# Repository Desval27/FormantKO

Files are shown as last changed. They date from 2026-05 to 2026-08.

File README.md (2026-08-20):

# Formant-KO 

# WIP
A somewhat authentic (at least in spirit) knockoff of the Elektor Formant™ DIY project synthesizer.  

Components that are not easily sourcable are substitued.  Substituted components or adapater boards are noted.

[Original Book 1 PDF](https://ikiwiki.laglab.org/Modular_Beast/ElektorFormantMusicSynthesiser.pdf)

DIN 41617 connecters are replaced with DIN 41612 connectors (Type B 32-PIN).  A backplane is included as part of the project to avoid the point-to-point backend wiring of the original.  However, the current backplane does not currently offer more configurability compared to the original.  It simply provides a secure connection and reduces wiring complexity and fragility.  

I have opted to keep the flying wires for connecting the panel components as opposed to a separate panel mounted "control" PCB.  Right now I'm torn between keeping the layouts and wiring as they were originally defined or replacing them with something like JST XH connectors for easy disconnect & replacement.  Perhaps both?

The goal for verison 2 is to make both the cards and the bus system more configurable compared to the original normaled path (e.g. jumpers for signal routing, etc.).

### What About the μA726?

Of course this part is in very short supply and often quite expensive when available.  However, at least for this iteration, the plan is to replicate the original design as closely as possible.  Not only will this allow original parts to be used but it will also permit available drop in replacements such as the [pA726](https://www.portabellabz.be/pa726.html). 

### A Note About Board Heights

The original Formant used two different PCB sizes.  These were Small (160mm x 100mm) and Large (160mm x 200mm).  The Small corresponds to the standard single height EuroCard, but the standard double height EuroCard is 160mm x 233.35mm. The latter being 33.35mm taller than the original.  This replica will use the double height EuroCard instead of the original Large.  This allows for eaiser usage of standard EuroCard cages and accessories.  

Note: All modules offer mounting support for typical Schroff EuroCard panel and rack accessories.

## Status

⚠️ Very Incomplete ⚠️

Note: This information is only as accurate as I can remember to update it.

Most activity has been in the COM, NOISE, and LFOs modules. Scratch that....most activity has been bits and pieces all over.  I like to switch things up.

Latest updates are for the [ADSR CONTROLLER](modules/ADSR_CONTROLLER/README.md) module.

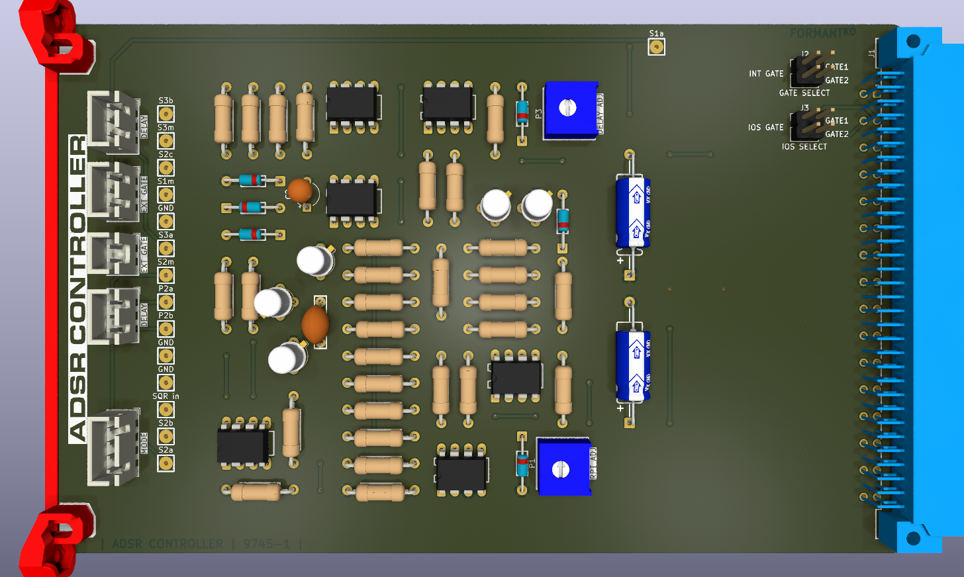
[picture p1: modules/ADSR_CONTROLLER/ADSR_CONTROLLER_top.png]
Top Render


- ✓ PCB/Panel exists but likely a WIP.
- ✔ PCB/Panel exists but may not be completely functional or untested.
- ✅ PCB/Panel exists and is working (for a given value of "working").

## Modules

- [TEMPLATE](modules/TEMPLATE/README.md)

### Book 1

- ✓ [VCO](modules/VCO/README.md)
- ✓ [VCF 12dB](modules/VCF_12/README.md)
- [VCF 24dB](modules/VCF_24/README.md)
- ✓ [RFM](modules/RFM/README.md)
- ✓ [ADSR](modules/ADSR/README.md)
- ✔ [DUAL VCA](modules/DUAL_VCA/README.md)
- [LFOs](modules/LFOs/README.md)
- ✓ [NOISE](modules/NOISE/README.md)
- ✓ [COM](modules/COM/README.md)

### Book 2

- [TOUCH CONTROLLER](modules/TOUCH_CONTROLLER/README.md)
- [NEW PITCH DETECTOR](modules/NPD/README.md)
- [DIGITAL KEYBOARD CONTROLLER](modules/DKC/README.md)
- [VCF EXTENSIONS](modules/VCF_EXT/README.md)
- ✓ [LFO SINE CONVERTER](modules/LFO_SINE/README.md)
- ✓ [NOISE DNG](modules/NOISE_DNG/README.md)
- ✓ [NOISE CNC](modules/NOISE_CNC/README.md)
- [COM EXTENSIONS](modules/COM_EXT/README.md)
- ✓ [RING MODULATOR](modules/RING_MODULATOR/README.md)
- ✔ [PHASE SHIFTER](modules/PHASE_SHIFTER/README.md)
- [KRIMISIZER](modules/KRIMISIZER/README.md)
- [DIGITAL REVERB](modules/DIGITAL_REVERB/README.md)
- [POWER SUPPLIES](modules/POWER_SUPPLIES/README.md)
- [KOV KB-GATE DISTRIBUTION](modules/KOV_KB_GATE_DISTRIBUTION/README.md)
- [MULTIPLE JACKS](modules/MULTIPLE_JACKS/README.md)
- ✔ [ADSR CONTROLLER](modules/ADSR_CONTROLLER/README.md)
- ✓ [VC LFOs](modules/VC_LFOs/README.md)
- [LF VCO](modules/LF_VCO/README.md)
- [DNG](modules/DNG/README.md)
- ✔ [ENVELOPE_FOLLOWER](modules/ENVELOPE_FOLLOWER/README.md)
- ✔ [SAMPLE & HOLD](modules/SAMPLE_AND_HOLD/README.md)
- ✓ [WAVEFORM-PROCESSOR](modules/WAVEFORM_PROCESSOR/README.md)
- [MIXER](modules/MIXER/README.md)
- ✔ [TUNING](modules/TUNING/README.md)
- [SEQUENCER](modules/SEQUENCER/README.md)

## Panels

- [TEMPLATE_3U](panels/TEMPLATE_3U/README.md)
- [TEMPLATE_6U](panels/TEMPLATE_6U/README.md)

### Book 1

- ✓ [VCO](panels/VCO/README.md)
- ✓ [VCF-12](panels/VCF_12/README.md)
- ✓ [VCF-24](panels/VCF_24/README.md)
- ✓ [RFM](panels/RFM/README.md)
- ✓ [ADSR](panels/ADSR/README.md)
- ✓ [DUAL_VCA](panels/DUAL_VCA/README.md)
- [LFOs](panels/LFOs/README.md)
- ✓ [NOISE](panels/NOISE/README.md)
- ✓ [COM](panels/COM/README.md)

### Book 2

- ✓ [RING MODULATOR](panels/RING_MODULATOR/README.md)
- ✓ [PHASE SHIFTER](panels/PHASE_SHIFTER/README.md)
- ✓ [MULTIPLE JACKS 3U](panels/MULTIPLE_JACKS_3U/README.md)
- ✓ [MULTIPLE JACKS 6U](panels/MULTIPLE_JACKS_6U/README.md)
- [DNG](panels/DNG/README.md)
- ✓ [ENVELOPE FOLLOWER](panels/ENVELOPE_FOLLOWER/README.md)
- [WAVEFORM PROCESSOR](panels/WAVEFORM_PROCESSOR/README.md)
- [MIXER 3](panels/MIXER_3/README.md)
- ✓ [TUNING](panels/TUNING/README.md)

## System

- ✓ [KEYBOARD INTERFACE](system/KBI/README.md)
- ✓ [KEYBOARD DIVIDER](system/KB_DIV/README.md)
- ✓ [INTERFACE RECEIVER](system/INTF_RCVR/README.md)
- ✔ [POWER SUPPLY](system/PSU/README.md)
- ✓ [POWER SUPPLY TRANSISTORS](system/PSU/PSU_PT/README.md)
- ✓ [BACKPLANE A](system/BACKPLANE_A/README.md)
- ✅ [TEST BOARD](system/TEST_HARNESS/README.md)
- ✓ [CARD EXTENDER](system/CARD_EXTENDER/README.md)
- ✓ [µA726C TESTER](system/VALIDATOR_JIG/README.md)

## MFOS Based Modules

[MFOS Site (External Link)](https://musicfromouterspace.com/)

### Modules

- [CALIBRATOR](MFOS/modules/CALIBRATOR/README.md)
- [CLOCK](MFOS/modules/CLOCK/README.md)
- [ANALOG CV-16](MFOS/modules/ANALOG/README.md)

### Panels

- [CLOCK](MFOS/panels/CLOCK/README.md)
- [ANALOG CV-16](MFOS/panels/ANALOG/README.md)

## ⚠️ Disclaimer⚠️

This project is provided **"as is"**, without warranty of any kind, express or implied,
including but not limited to the warranties of merchantability, fitness for a
particular purpose, and noninfringement.

This is a DIY electronics project intended for educational and experimental use.
Use at your own risk.

The author assumes **no responsibility or liability** for any damage, injury, or loss
resulting from the use or misuse of this design, including but not limited to:

* Damage to connected equipment (Eurorack modules, power supplies, computers, etc.)
* Incorrect assembly or wiring
* Use with incompatible voltages or signal levels
* Personal injury

### Electrical Safety

This project may interface with:

* ±15V Power rails
* AC Mains Power (Lethal Risk)
* External control voltages (CV)
* Digital and analog circuitry

Improper handling may result in damage or unsafe conditions.

You are responsible for:

* Verifying all connections before powering the system
* Ensuring correct polarity of power connections
* Confirming voltage ranges and signal compatibility
* Using appropriate protection circuits where necessary

### No Guarantees

Schematics, PCB layouts, and code are provided for reference only.
They may contain errors, omissions, or design flaws.

**Always review and validate the design before building or using it.**

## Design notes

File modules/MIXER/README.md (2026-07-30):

# MIXER-3

Format: 3U

## Status

⚠️ Incomplete⚠️

## Documents

- [English Translation](doc/MIXER__en.pdf)
<!--
- [Schematic](doc/schematic.pdf)
- [Assembly](doc/assembly.pdf)
- [Bill of Materials](doc/bom.csv)
- [Interactive Bill of Materials](doc/ibom.html)
-->

## Gerber to Order

⚠️ Untested ⚠️

<!--
- [Default](gerber_to_order/MIXER_160.0x100.0mm_for_Default.zip)
- [Elecrow](gerber_to_order/MIXER_160.0x100.0mm_for_Elecrow.zip)
- [FusionPCB](gerber_to_order/MIXER_160.0x100.0mm_for_FusionPCB.zip)
- [JLCPCB](gerber_to_order/MIXER_160.0x100.0mm_for_JLCPCB.zip)
- [PCBWay](gerber_to_order/MIXER_160.0x100.0mm_for_PCBWay.zip)
-->

## Images

<!--
![Rendered PCB Top](MIXER_top.png "Rendered PCB Top")

![Rendered PCB Bottom](MIXER_bottom.png "Rendered PCB Bottom")
-->

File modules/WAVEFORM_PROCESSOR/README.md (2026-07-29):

# WAVEFORM PROCESSOR

Format: 3U

The **Waveform Processor (WP)** is a versatile waveshaping module that dramatically expands the sonic palette of the **FORMANT** synthesizer by transforming existing oscillator waveforms into entirely new timbres. Using adjustable and voltage-controlled clipping, symmetry control, and selective amplification and inversion of waveform segments, it can produce effects ranging from brighter harmonics and trapezoidal waveforms to emphasized overtones, frequency doubling, and ring-modulator-like textures. With two signal inputs and a CV input for clipping modulation, the module responds dynamically to LFOs, envelopes, sequencers, or audio-rate control signals, making it equally suited for subtle animated timbral movement and aggressive experimental sound design. No calibration is required, making it a straightforward yet highly rewarding addition to any FORMANT system.

## Status

⚠️ Untested⚠️

## Documents

- [English Translation](doc/WAVEFORM_PROCESSOR__en.pdf)
- [Schematic](doc/schematic.pdf)
- [Assembly](doc/assembly.pdf)
- [Bill of Materials](doc/bom.csv)
- [Interactive Bill of Materials](doc/ibom.html)

## Gerber to Order

⚠️ Untested ⚠️

- [Default](gerber_to_order/WAVEFORM_PROCESSOR_160.0x100.0mm_for_Default.zip)
- [Elecrow](gerber_to_order/WAVEFORM_PROCESSOR_160.0x100.0mm_for_Elecrow.zip)
- [FusionPCB](gerber_to_order/WAVEFORM_PROCESSOR_160.0x100.0mm_for_FusionPCB.zip)
- [JLCPCB](gerber_to_order/WAVEFORM_PROCESSOR_160.0x100.0mm_for_JLCPCB.zip)
- [PCBWay](gerber_to_order/WAVEFORM_PROCESSOR_160.0x100.0mm_for_PCBWay.zip)

## Images

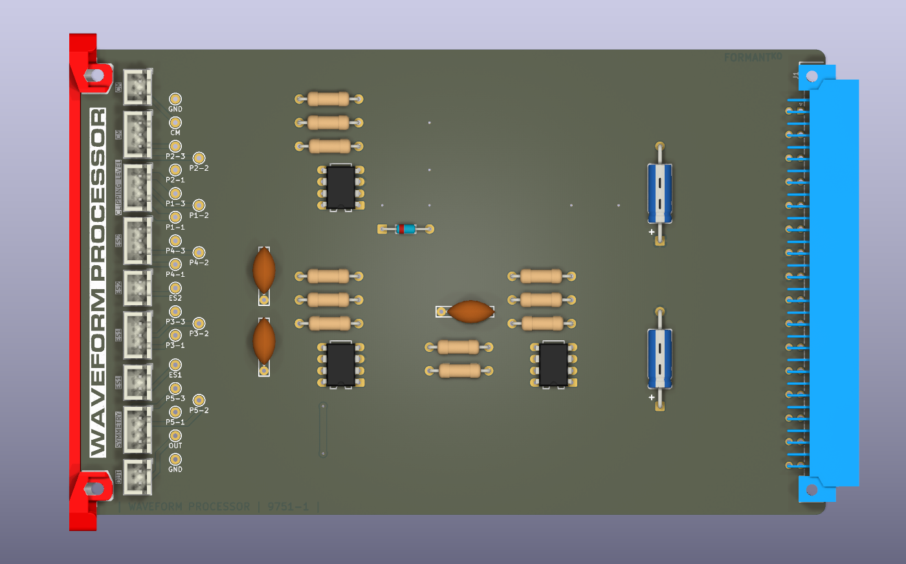
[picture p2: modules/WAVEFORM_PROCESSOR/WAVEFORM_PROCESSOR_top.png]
Rendered PCB Top


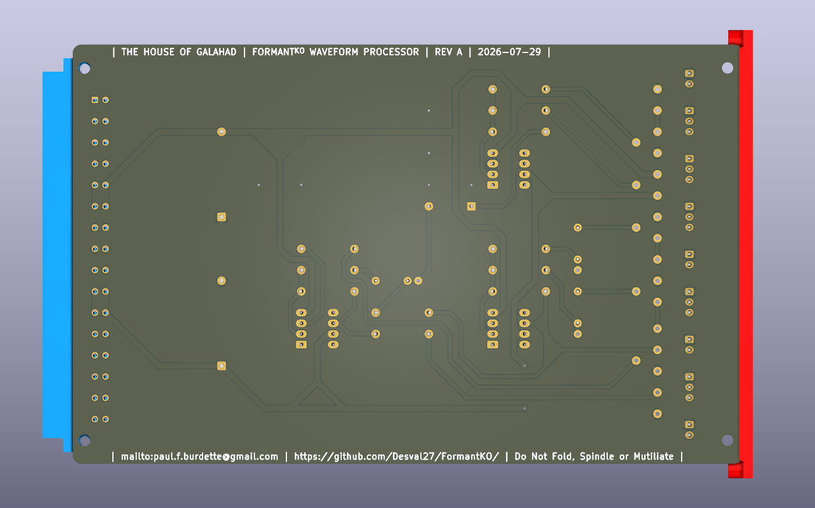
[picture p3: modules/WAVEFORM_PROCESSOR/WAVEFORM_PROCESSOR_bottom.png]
Rendered PCB Bottom


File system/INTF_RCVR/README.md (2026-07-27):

# INTERFACE RECEIVER

Format: Misc

### Modifications

Nothing major so far.

## Status

⚠️ Untested⚠️

## Documents

- [Schematic](doc/schematic.pdf)
- [Assembly](doc/assembly.pdf)
- [Bill of Materials](doc/bom.csv)
- [Interactive Bill of Materials](doc/ibom.html)

## Gerber to Order

⚠️ Untested⚠️

- [Default](gerber_to_order/INTF_RCVR_64.0x72.0mm_for_Default.zip)
- [Elecrow](gerber_to_order/INTF_RCVR_64.0x72.0mm_for_Elecrow.zip)
- [FusionPCB](gerber_to_order/INTF_RCVR_64.0x72.0mm_for_FusionPCB.zip)
- [JLCPCB](gerber_to_order/INTF_RCVR_64.0x72.0mm_for_JLCPCB.zip)
- [PCBWay](gerber_to_order/INTF_RCVR_64.0x72.0mm_for_PCBWay.zip)

## Images

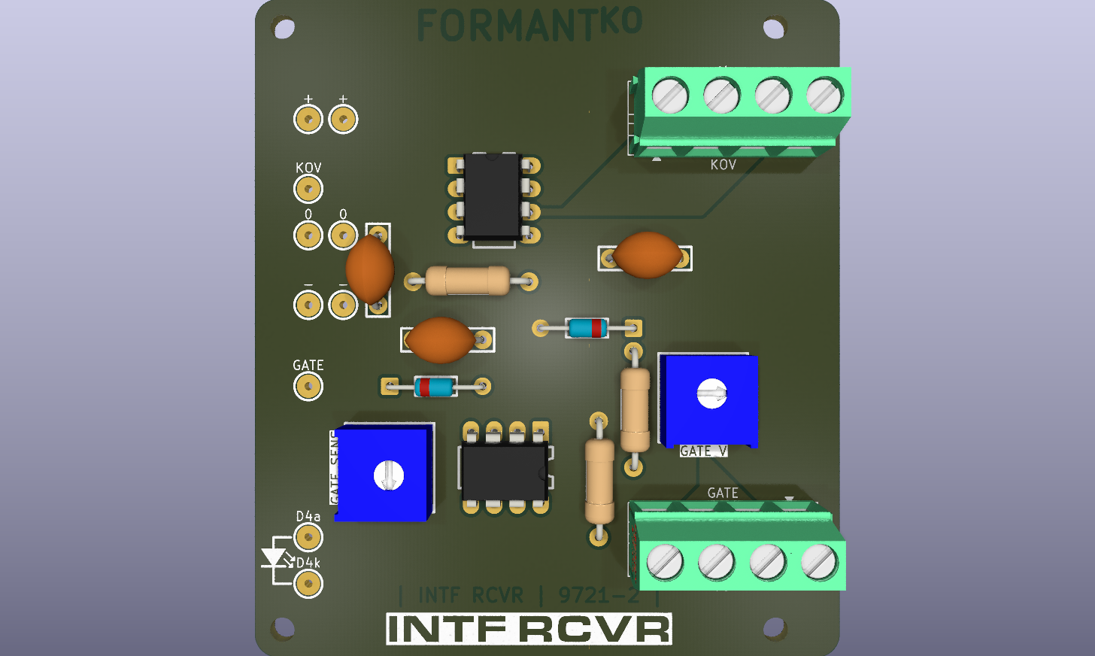
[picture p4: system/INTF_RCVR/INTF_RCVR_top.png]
Rendered PCB Top


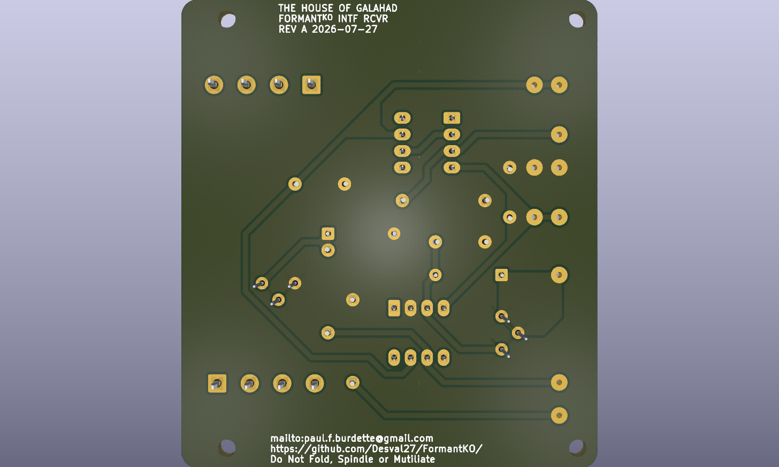
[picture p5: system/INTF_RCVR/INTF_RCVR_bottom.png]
Rendered PCB Bottom


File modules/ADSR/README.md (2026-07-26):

# ADSR

Format: 3U

### Modifications

- Add external gate input.  This is normalized and will disconnect any existing internal gate bus assignment.
- Added jumper to completly disable the external gate path.  With the jumper in place the gate I/O functions the same as the original design.

## Status

⚠️ Untested⚠️

## Documents

- [Schematic](doc/schematic.pdf)
- [Assembly](doc/assembly.pdf)
- [Bill of Materials](doc/bom.csv)
- [Interactive Bill of Materials](doc/ibom.html)

## Gerber to Order

⚠️ Untested⚠️

- [Default](gerber_to_order/ADSR_160.0x100.0mm_for_Default.zip)
- [Elecrow](gerber_to_order/ADSR_160.0x100.0mm_for_Elecrow.zip)
- [FusionPCB](gerber_to_order/ADSR_160.0x100.0mm_for_FusionPCB.zip)
- [JLCPCB](gerber_to_order/ADSR_160.0x100.0mm_for_JLCPCB.zip)
- [PCBWay](gerber_to_order/ADSR_160.0x100.0mm_for_PCBWay.zip)

## Images

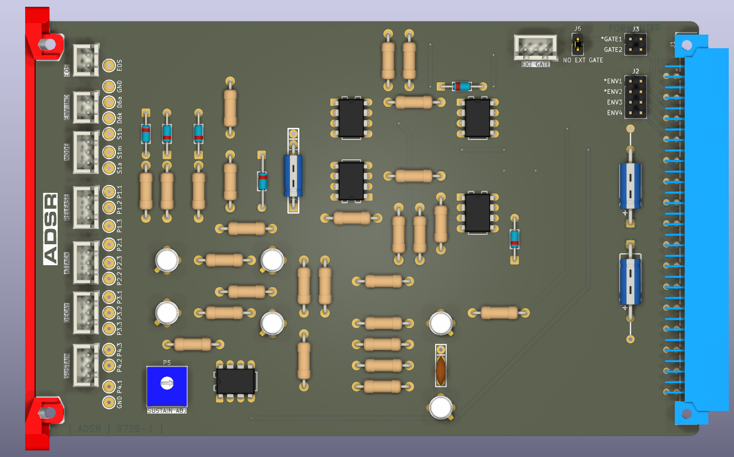
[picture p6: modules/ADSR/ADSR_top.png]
Rendered PCB Top


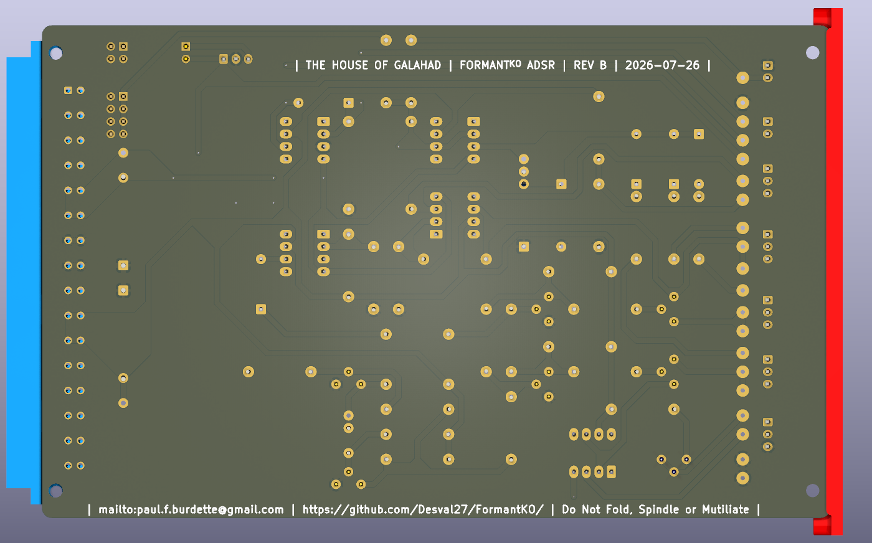
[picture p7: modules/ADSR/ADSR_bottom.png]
Rendered PCB Bottom


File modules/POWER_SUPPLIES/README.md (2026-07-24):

# POWER SUPPLIES

Format: Multiple

## Status

⚠️Incomplete⚠️

## Documents

- [English Translation](doc/POWER_SUPPLIES__en.pdf)

### Bipolar Power Supply

- [Assembly](BIPOLAR_PSU/doc/assembly.pdf)
- [Schematic](BIPOLAR_PSU/doc/schematic.pdf)
- [Bill of Materials](BIPOLAR_PSU/doc/bom.csv)
- [Interactive Bill of Materials](BIPOLAR_PSU/doc/ibom.html)

### 9V Power Supply

## Gerber to Order

⚠️Untested⚠️

### Bipolar Power Supply

- [Default](BIPOLAR_PSU/gerber_to_order/BIPOLAR_PSU_106.0x32.0mm_for_Default.zip)
- [Elecrow](BIPOLAR_PSU/gerber_to_order/BIPOLAR_PSU_106.0x32.0mm_for_Elecrow.zip)
- [FusionPCB](BIPOLAR_PSU/gerber_to_order/BIPOLAR_PSU_106.0x32.0mm_for_FusionPCB.zip)
- [JLCPCB](BIPOLAR_PSU/gerber_to_order/BIPOLAR_PSU_106.0x32.0mm_for_JLCPCB.zip)
- [PCBWAY](BIPOLAR_PSU/gerber_to_order/BIPOLAR_PSU_106.0x32.0mm_for_PCBWay.zip)

### 9V Power Supply

## Images

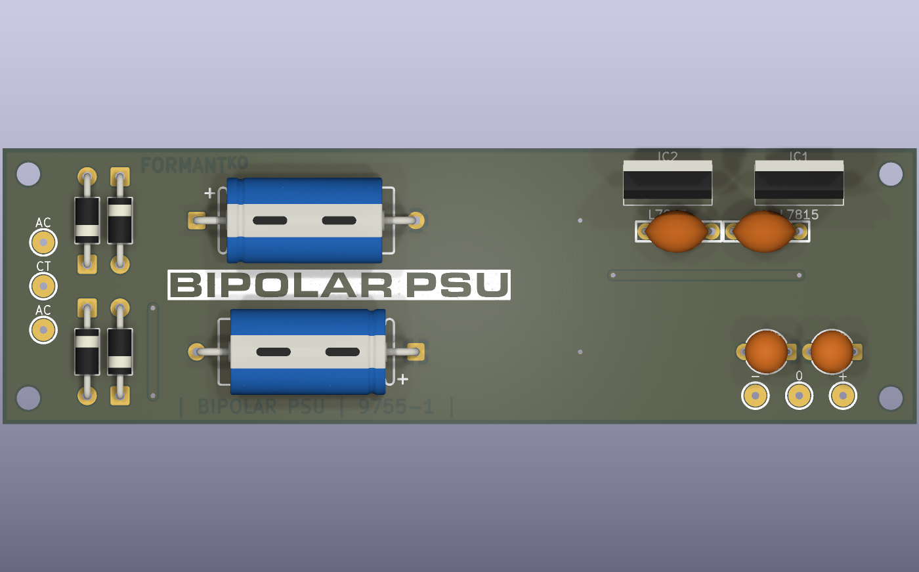
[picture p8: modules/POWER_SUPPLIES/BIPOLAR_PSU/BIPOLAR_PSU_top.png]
Rendered BIPOLAR PCB Top

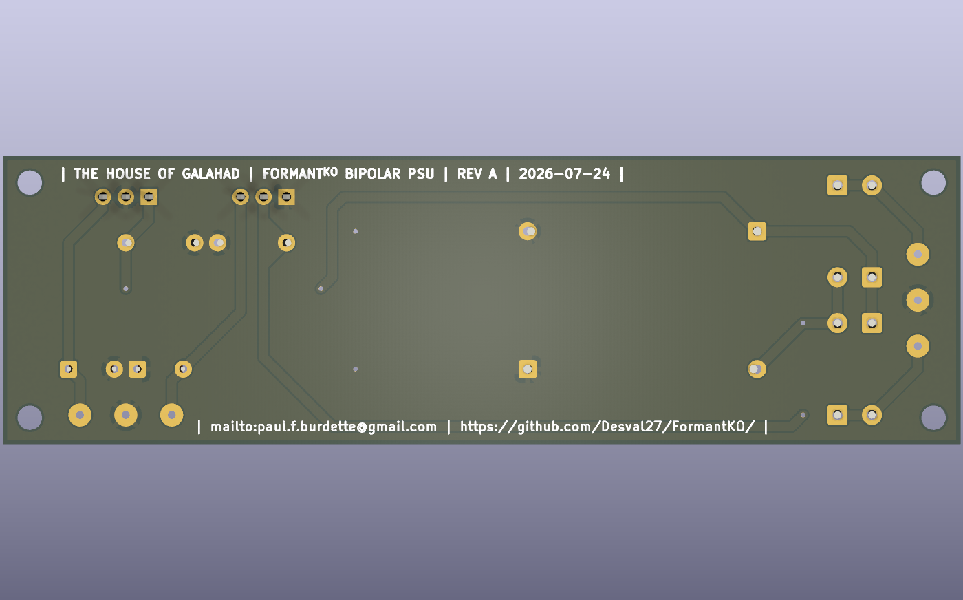
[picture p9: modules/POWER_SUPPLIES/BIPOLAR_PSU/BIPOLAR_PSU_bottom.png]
Rendered BIPOLAR PCB Bottom


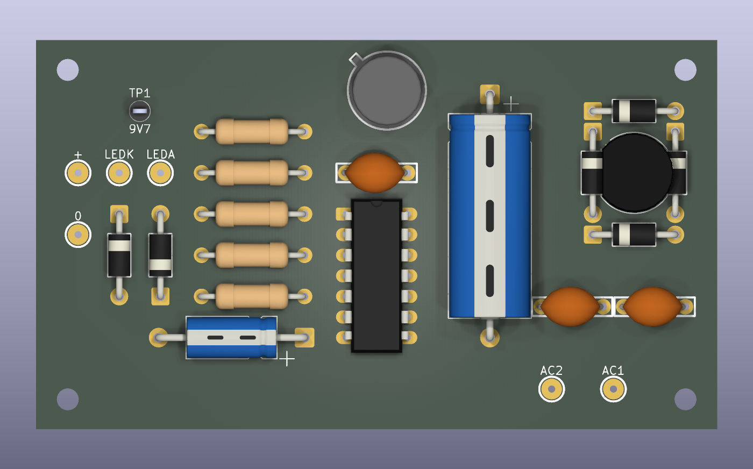
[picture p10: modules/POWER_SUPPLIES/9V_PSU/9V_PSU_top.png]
Rendered 9V PCB Top

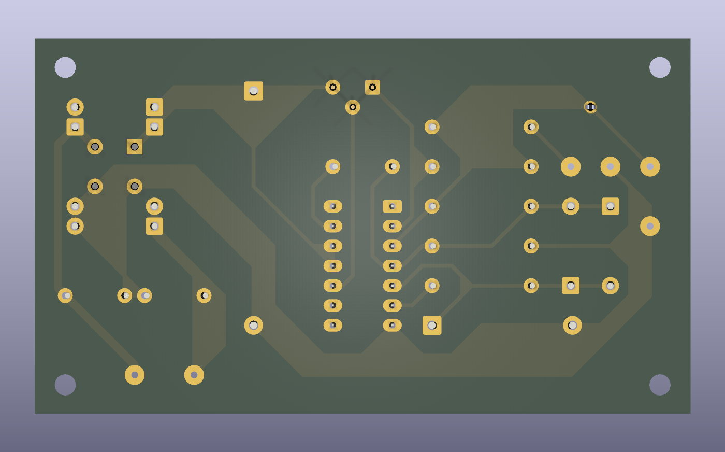
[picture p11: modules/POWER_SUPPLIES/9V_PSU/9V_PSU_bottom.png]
Rendered 9V PCB Bottom


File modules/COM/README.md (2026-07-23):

# COM

Format: 3U

### Modifications

- Change power & gate leds to not require the interface receiver board.
- Use transistor drivers for both gate LEDs.
- Add Gate2 LED and associated tranistor driver.

## Status

⚠️ Untested⚠️

## Documents

- [Schematic](plots/COM__Schematic.pdf)
- [Assembly](plots/COM__Assembly.pdf)
- [Bill of Materials](bom/bom.csv)
- [Interactive Bill of Materials](bom/ibom.html)

## Gerber to Order

⚠️ Untested⚠️

- [Default](gerber_to_order/COM_160.0x100.0mm_for_Default.zip)
- [Elecrow](gerber_to_order/COM_160.0x100.0mm_for_Elecrow.zip)
- [FusionPCB](gerber_to_order/COM_160.0x100.0mm_for_FusionPCB.zip)
- [JLCPCB](gerber_to_order/COM_160.0x100.0mm_for_JLCPCB.zip)
- [PCBWay](gerber_to_order/COM_160.0x100.0mm_for_PCBWay.zip)

## Images

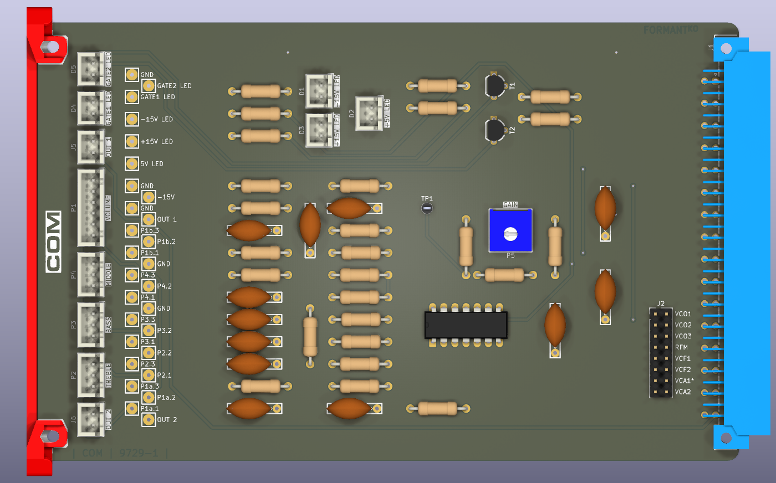
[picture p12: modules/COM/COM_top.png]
Rendered PCB Top


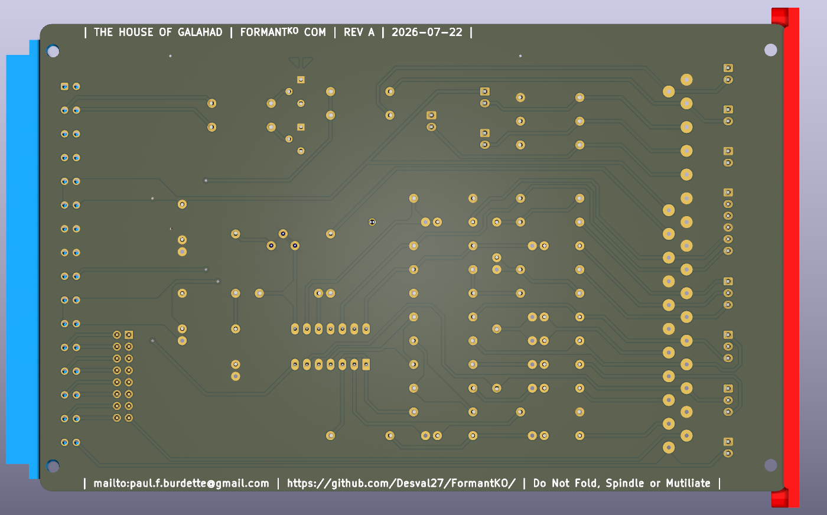
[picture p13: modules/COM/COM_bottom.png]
Rendered PCB Bottom


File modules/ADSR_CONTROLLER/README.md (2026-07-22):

# ADSR CONTROLLER

Format: 3U

The ADSR Controller expands the capabilities of the standard Formant ADSR module by adding clock-driven repeat and delayed triggering functions. An external square-wave clock source (typically an LFO or VC-LFO) can repeatedly retrigger the envelope, enabling rhythmic modulation and gated effects. Repeat operation may be disabled, run continuously (Auto), or only while an external or keyboard gate is active. An adjustable delay function can also postpone envelope triggering, making the module useful for creating delayed attacks, repeating envelopes, and more complex modulation patterns.

## Status

⚠️Untested⚠️

## Documents

- [English Translation](ADSR_CONTROLLER__en.pdf)
- [Schematic](plots/ADSR_CONTROLLER__Schematic.pdf)
- [Assembly](plots/ADSR_CONTROLLER__Assembly.pdf)
- [Bill of Materials](bom/bom.csv)
- [Interactive Bill of Materials](bom/ibom.html)

## Gerber to Order

⚠️Untested⚠️

- [Default](gerber_to_order/ADSR_CONTROLLER_160.0x100.0mm_for_Default.zip)
- [Elecrow](gerber_to_order/ADSR_CONTROLLER_160.0x100.0mm_for_Elecrow.zip)
- [FusionPCB](gerber_to_order/ADSR_CONTROLLER_160.0x100.0mm_for_FusionPCB.zip)
- [JLCPCB](gerber_to_order/ADSR_CONTROLLER_160.0x100.0mm_for_JLCPCB.zip)
- [PCBWay](gerber_to_order/ADSR_CONTROLLER_160.0x100.0mm_for_PCBWay.zip)

## Images

Rendered PCB Top

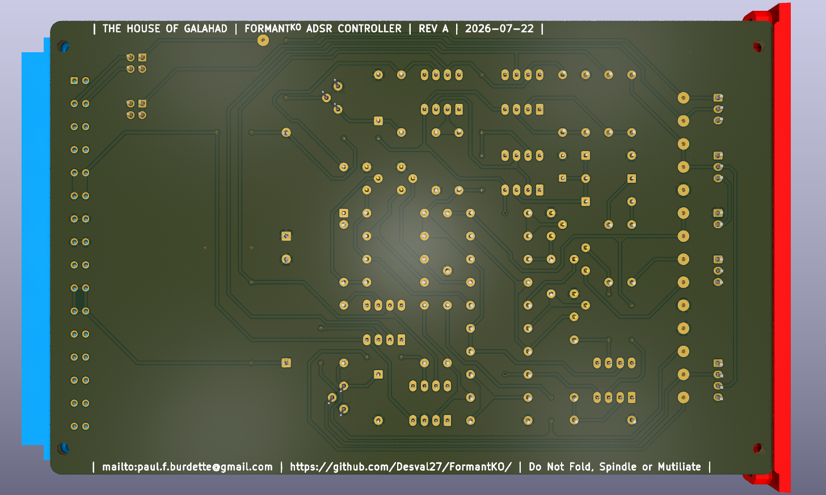
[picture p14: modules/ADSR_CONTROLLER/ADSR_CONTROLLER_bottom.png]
Rendered PCB Bottom


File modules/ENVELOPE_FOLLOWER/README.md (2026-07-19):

# ENVELOPE FOLLOWER

Format: 3U

The Envelope Follower converts an incoming audio signal into control voltages that can be used to modulate other synthesizer modules. It accepts microphone, guitar, or line-level signals, with an adjustable input gain to accommodate a wide range of sources. The module extracts the amplitude envelope of the audio and generates a proportional control voltage (CV), allowing dynamics such as playing intensity or volume changes to control filters, VCAs, oscillators, or other destinations. A separate threshold control produces a gate output whenever the input level exceeds the selected level, making it possible to trigger envelopes, sequencers, or other event-driven modules directly from an audio signal.

## Status

⚠️ Untested⚠️

## Documents

- [English Translation](ENVELOPE_FOLLOWER__en.pdf)
- [Schematic](plots/ENVELOPE_FOLLOWER__Schematic.pdf)
- [Assembly](plots/ENVELOPE_FOLLOWER__Assembly.pdf)
- [Interactive Bill of Materials](bom/ibom.html)

## Gerber to Order

⚠️ Untested⚠️

- [Default](gerber_to_order/ENVELOPE_FOLLOWER_160.0x100.0mm_for_Default.zip)
- [Elecrow](gerber_to_order/ENVELOPE_FOLLOWER_160.0x100.0mm_for_Elecrow.zip)
- [FusionPCB](gerber_to_order/ENVELOPE_FOLLOWER_160.0x100.0mm_for_FusionPCB.zip)
- [JLCPCB](gerber_to_order/ENVELOPE_FOLLOWER_160.0x100.0mm_for_JLCPCB.zip)
- [PCBWay](gerber_to_order/ENVELOPE_FOLLOWER_160.0x100.0mm_for_PCBWay.zip)

## Images

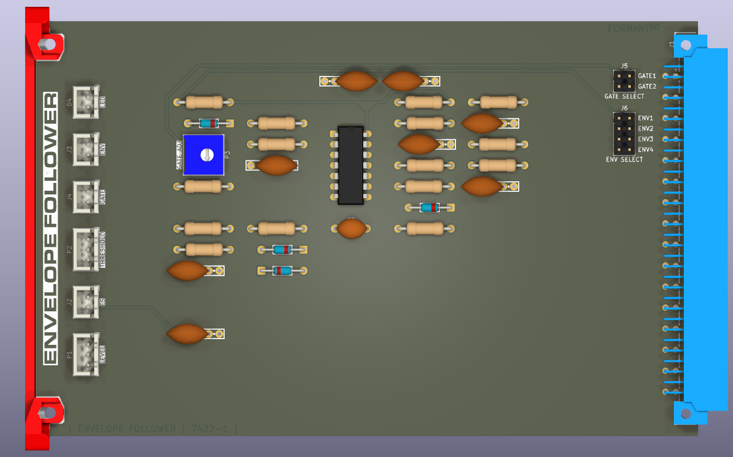
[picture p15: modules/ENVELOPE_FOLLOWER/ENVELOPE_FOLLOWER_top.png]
Rendered PCB Top


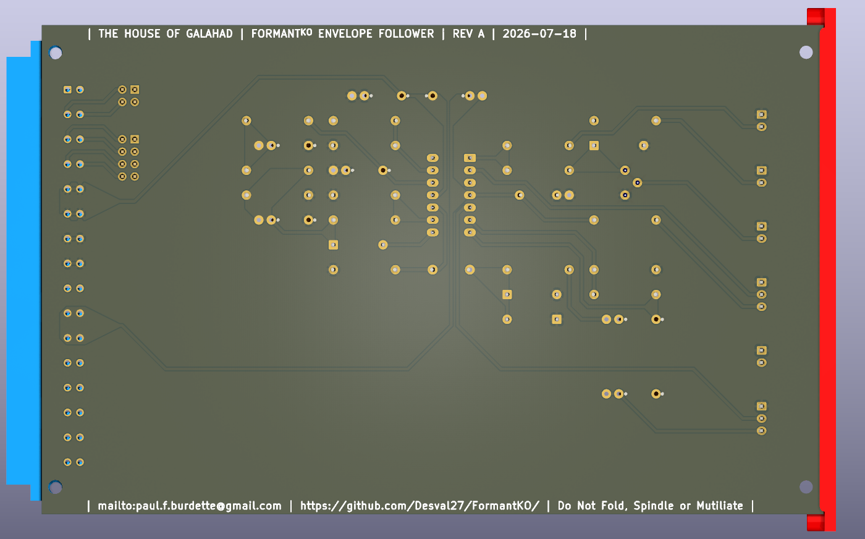
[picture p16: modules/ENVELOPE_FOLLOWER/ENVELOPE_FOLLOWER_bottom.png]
Rendered PCB Bottom


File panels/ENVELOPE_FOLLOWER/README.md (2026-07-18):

# ENVELOPE FOLLOWER

Formant: 3U

### Modifications

None

## Status

⚠️ Untested⚠️

## Gerber to Order

⚠️ Untested⚠️

- [Default](gerber_to_order/ENVELOPE_FOLLOWER_70.78x128.4mm_for_Default.zip)
- [Elecrow](gerber_to_order/ENVELOPE_FOLLOWER_70.78x128.4mm_for_Elecrow.zip)
- [FusionPCB](gerber_to_order/ENVELOPE_FOLLOWER_70.78x128.4mm_for_FusionPCB.zip)
- [JLCPCB](gerber_to_order/ENVELOPE_FOLLOWER_70.78x128.4mm_for_JLCPCB.zip)
- [PCBWay](gerber_to_order/ENVELOPE_FOLLOWER_70.78x128.4mm_for_PCBWay.zip)

## Images

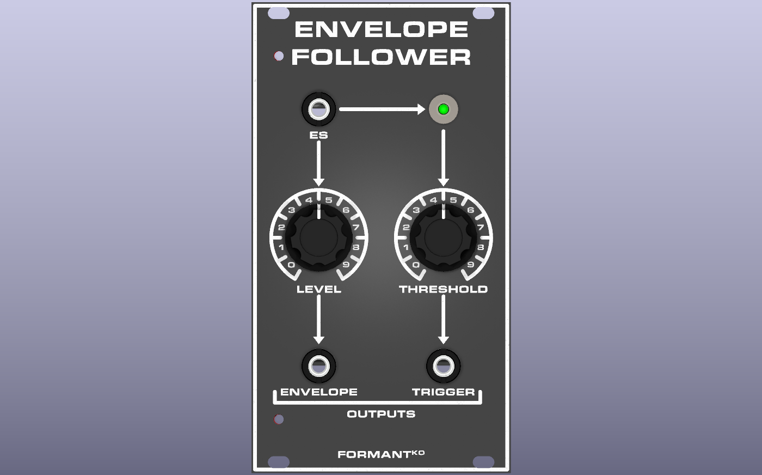
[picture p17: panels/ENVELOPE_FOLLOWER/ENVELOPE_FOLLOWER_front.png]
Rendered Panel Front


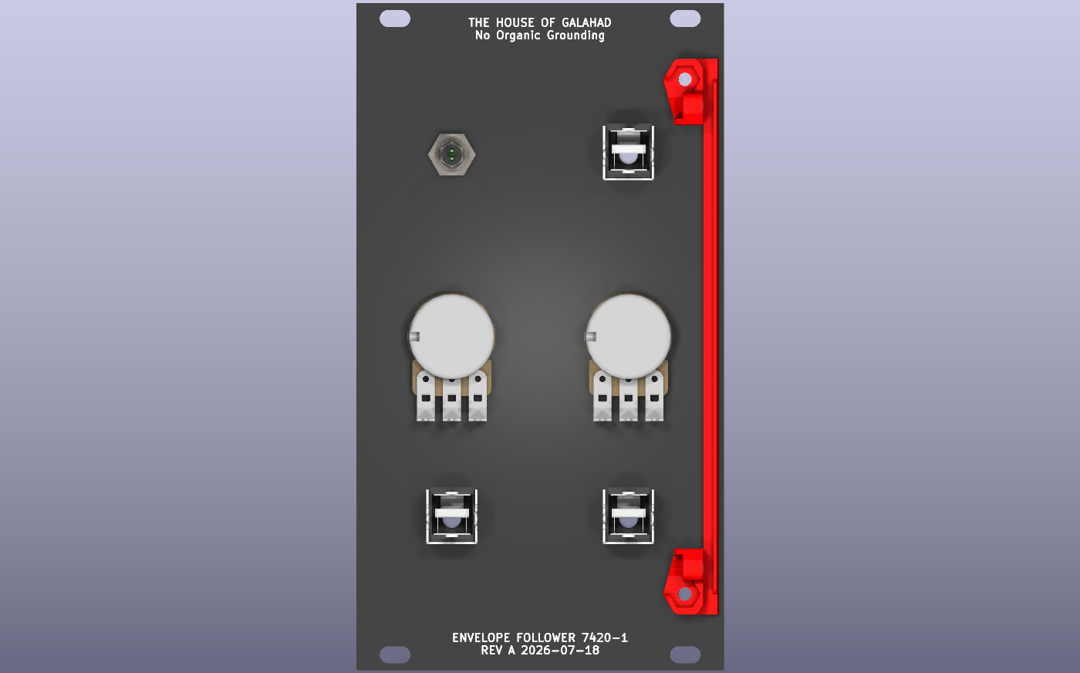
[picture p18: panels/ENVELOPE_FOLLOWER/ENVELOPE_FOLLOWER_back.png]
Rendered Panel Back


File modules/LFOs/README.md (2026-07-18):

# LFOs

Format: 3U

### Modifications

None

## Status

⚠️ Incomplete⚠️

## Documents

<!--
- [Schematic](plots/ADSR__schematic.pdf)
- [Assembly](plots/ADSR__Assembly.pdf)
- [Interactive Bill of Materials](bom/ibom.html)
-->

## Gerber to Order

<!--
⚠️ Untested⚠️
-->

## Images

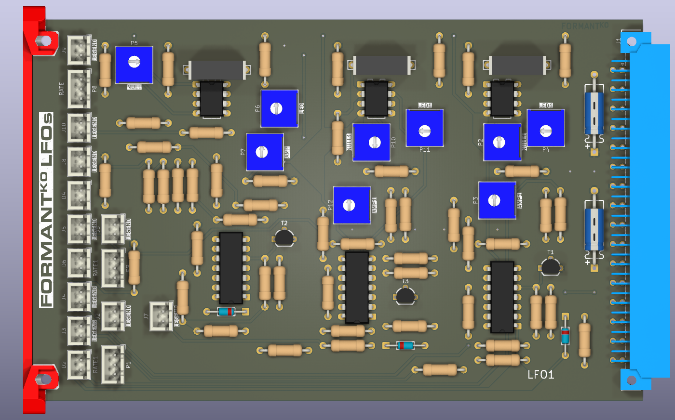
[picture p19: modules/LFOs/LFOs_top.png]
Rendered PCB Top


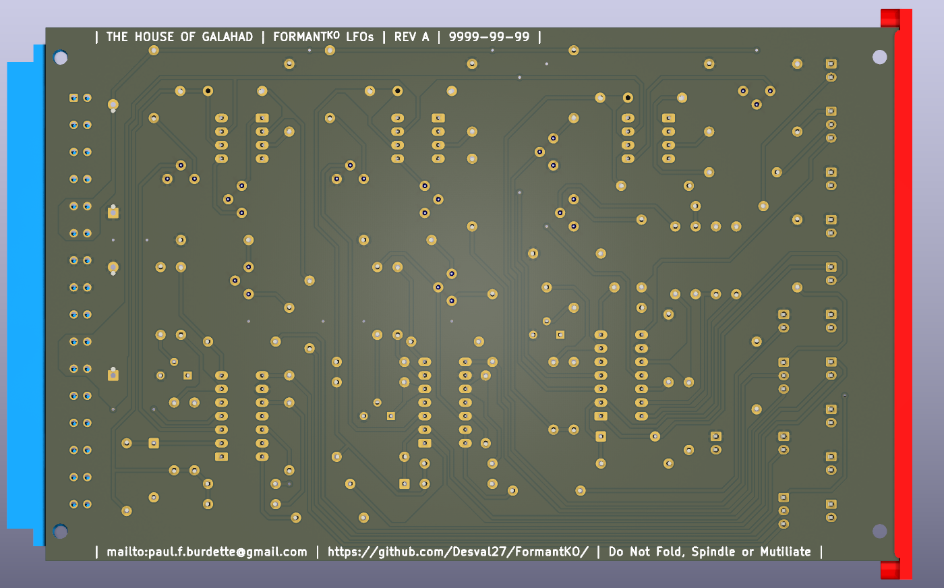
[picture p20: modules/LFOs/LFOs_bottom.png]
Rendered PCB Bottom


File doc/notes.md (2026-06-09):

For a standard 3U Eurocard (100mm x 160mm) system, connector positioning is strictly governed by global standards—specifically IEC 60297-3-101 and IEEE 1101.1. [1, 2] 
Because a backplane serves as a mirror to the card plugging into it, the layout of the backplane's card connectors is derived directly from the standard subrack grid dimensions. [3] 
## How to Access Official CAD Files
To get precise 3D step files, layout blueprints, or 3D PDFs for a 175mm depth 3U subrack, you can utilize official configurations:

* The Schroff Configurator: nVent features a [Visual 3D Configurator](https://www.electromek.com.au/product/nvent-schroff-subracks-and-chassis/) that lets you configure a subrack with a 175mm depth (such as the [EuropacPRO 24563-131 Kit](https://www.nvent.com/en-us/schroff/products/enc24563-131)). [4] 
* CAD Generation: By logging into the nVent Schroff CAD portal, you can download the complete mechanical enclosure in 35 native formats. This assembly includes the exact position of the rear horizontal backplane rails relative to the guide rails. [1, 5] 

## Connector Placement Mechanical Standards
When designing or laying out your backplane PCB, you must account for the exact spatial offset between the card guide rails and where the pins align.

* The Pitch (Horizontal Spacing): The horizontal spacing of card slots is based on 1 HP (Horizontal Pitch) = 5.08 mm (0.2 inches). Standard backplane spacing usually defaults to 4 HP (20.32 mm), 5 HP, or 8 HP increments. [2, 6, 7] 
* The Vertical Centerline: For a standard 3U Backplane (total profile height is roughly 128.4 mm to fit the 132.55 mm subrack opening), the vertical center lines for standard DIN 41612 connectors are strictly constrained:
* For a single-connector card (like VME J1), the connector is dead-centered vertically on the 100mm card edge.
   * The spacing between mounting screw holes on the rear horizontal subrack rails dictates the outer boundaries of your backplane PCB. [1, 8, 9] 

## Step-by-Step Layout Strategy

   1. Pull the Subrack CAD: Download the .STP file for the Schroff EuropacPRO 3U 175mm Subrack.
   2. Isolate the Card Grid: Look at the distance from the front card-mating plane to the rear insulation strip rail.
   3. Reference Plane Offset: Align your backplane PCB's front surface exactly where the card rails terminate. According to the standard [Schroff Design Guide](https://pdf.directindustry.com/pdf/nvent-schroff-gmbh/schroff-design-guide/7799-487781.html), the guide rail guides the bottom/top 1.6mm edge of the Eurocard. The connector pin array always indexes off the first pitch line relative to that 1.6mm reference plane. [1, 2, 4] 

Are you using standard DIN 41612 (two-part plug-in) connectors, or high-speed architectural connectors like CompactPCI (Hard Metric 2.0mm) or VPX (VITA 46)? Let me know so I can pinpoint the exact pin-to-edge offset constraints for that specification. [10, 11] 

[1] [https://www.nvent.com](https://www.nvent.com/en-us/schroff/products/enc24563-131)
[2] [https://pdf.directindustry.com](https://pdf.directindustry.com/pdf/nvent-schroff-gmbh/schroff-design-guide/7799-487781.html)
[3] [https://peakservo.com](https://peakservo.com/products/what-is-a-eurocard/)
[4] [https://us.rs-online.com](https://us.rs-online.com/product/nvent-schroff/24563131/70067572/)
[5] [https://www.nvent.com](https://www.nvent.com/en-us/schroff/configurator-login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)
[6] [https://forum.digikey.com](https://forum.digikey.com/t/backplanes/31677)
[7] [https://www.globalspec.com](https://www.globalspec.com/ds/1075/areaspec/gen_3u_160)
[8] [https://media.onlinecomponents.com](https://media.onlinecomponents.com/productfiles/mf-sch/schroffdesignguide.pdf)
[9] [https://www.nvent.com](https://www.nvent.com/sites/default/files/dam/tbaqy1qkgx/73972-103.pdf)
[10] [https://www.nvent.com](https://www.nvent.com/sites/default/files/dam//73972-101.pdf)
[11] [https://www.nvent.com](https://www.nvent.com/sites/default/files/dam//user-guide-vpx-3u-backplanes.pdf)

When aligning DIN 41612 connectors for a standard 3U Eurocard backplane, the dimensional constraints must strictly adhere to IEC 60297-3-101 standards. This ensures that when a 100mm high card slides into the subrack's top and bottom guide rails, the male connector on the card mates perfectly with the female socket on your backplane. [1] 
## Critical Vertical Alignment Dimensions
The total physical height of a standard 3U backplane PCB typically measures 128.4 mm (5.055 inches) to allow clearance inside a 132.55 mm subrack opening.

* The Reference Datum (0.00 mm): The absolute mechanical reference line is always the inside face of the bottom guide rail (where the bottom edge of the 100mm plug-in Eurocard rests). [2, 3] 
* Connector Centerline: The vertical center axis of the DIN 41612 connector must sit exactly 50.00 mm above this bottom card-guide datum line. This places the connector exactly dead-center relative to the 100mm Eurocard card edge. [2] 
* Mounting Hole Centers: The backplane PCB mounts to the rear horizontal rails of the Schroff EuropacPRO subrack. The center-to-center vertical distance between the top and bottom rear rail mounting screws is exactly 122.50 mm.

  +---------------------------------------------------------+ -- Top of Backplane PCB (~128.4 mm)

  |      o                                           o      | -- Top Mounting Rail Screw Line (122.50 mm)
  |                                                         |
  |   +-------------------------------------------------+   |
  |   | [ ] [ ] [ ] [ ] [ ] DIN 41612 [ ] [ ] [ ] [ ]   |   | == Connector Centerline (50.00 mm Axis)
  |   +-------------------------------------------------+   |
  |                                                         |
  |      o                                           o      | -- Bottom Mounting Rail Screw Line (0.00 mm / Datum)
  +---------------------------------------------------------+

## Connector Mounting Pin Hole Constraints
For a standard 96-position Type C or 64-position Type B DIN 41612 connector (the most common variants), the grid relies on a 2.54 mm (0.100 inch) pitch: [4] 

* The Center Pin (Row 16): On a standard 32-column connector, the horizontal spacing splits evenly between column 16 and 17.
* The Outer Flange Mounting Holes: DIN 41612 connectors feature two mechanical mounting flanges on the far left and right edges. The distance from the vertical centerline of these component mounting holes down to the bottom card reference datum is exactly 50.00 mm. The spacing between these two component holes on the connector body itself is 90.00 mm.

## Exact Reference CAD File Download Links
Instead of drawing the PCB profile from scratch, you can fetch official CAD profiles showing the exact layout of these components:

* Subrack Assembly Model: To verify clearances, view the [nVent Schroff EuropacPRO 3U 175mm Subrack Model](https://www.nvent.com/en-us/schroff/products/enc24563-131). The rear profiles explicitly detail the insulation strips and rail standoffs.
* Component-LevelFootprints: For the connector footprints, manufacturers like TE Connectivity Eurocard Connectors and Mouser Electronics' DIN 41612 Inventory offer native Altium, Eagle, and .STP files. These footprints contain the exact mounting-hole-to-signal-pin coordinate offsets.

Are you using a fully populated 96-pin Type C connector, or a high-power/coaxial hybrid (Type M) variant? I can provide the exact footprint drilling dimensions for the specialized pins if needed. [4] 

[1] [https://standards.iteh.ai](https://standards.iteh.ai/catalog/standards/sist/66706fc7-1eec-489a-9bd3-e31d8fc68f9a/sist-en-60297-3-101-2005)
[2] [https://uk.rs-online.com](https://uk.rs-online.com/web/content/discovery/ideas-and-advice/eurocards-pcb-guide)
[3] [https://en.wikipedia.org](https://en.wikipedia.org/wiki/Eurocard_%28printed_circuit_board%29)
[4] [https://www.farnell.com](https://www.farnell.com/datasheets/1731380.pdf)

Got it. Designing 14 HP modules with 64-position (2x32) Type B DIN 41612 connectors means you will have plenty of physical clearance on your backplane slots while adhering to a strict horizontal grid layout.
## Horizontal Slot Pitch (14 HP Spacing)
The horizontal grid of a Eurocard backplane is strictly bound to the 1 HP = 5.08 mm (0.2 inches) standard. For 14 HP slots, the mechanical constraints dictate the following layout guidelines:

* Slot Center-to-Center Pitch: Your horizontal card-slot spacing must be exactly 71.12 mm (14 HP × 5.08 mm).
* The Slot 1 Reference Datum (X = 0.00 mm): The horizontal center of your very first slot's connector is typically placed 10.16 mm (2 HP) or 15.24 mm (3 HP) from the left physical edge of the backplane PCB to clear the subrack's side panel assembly.
* Subsequent Slot Coordinates: The vertical centerline of each subsequent Type B connector will sit precisely at:
$$\text{Slot } N = \text{Slot 1 X-coordinate} + (N-1) \times 71.12\text{ mm}$$ 

## Type B (2x32) Connector Dimensions & Pin Alignment
A Type B DIN 41612 connector omits row "b", utilizing only rows "a" and "c" on a standard 2.54 mm (0.100 inch) grid.

* Physical Body Width: The connector housing is roughly 95.00 mm long, fitting perfectly within the 100 mm card height.
* Flange Mounting Holes: The spacing between the two mechanical fixing holes on the connector body is 90.00 mm. These holes must sit symmetrically at Y = 50.00 mm relative to the bottom card reference rail, giving them vertical positions of Y = 5.00 mm and Y = 95.00 mm.
* Pin Array Grid Coordinates:
* Rows (Y-Axis): Row "a" sits at Y = 48.73 mm and Row "c" sits at Y = 51.27 mm (spaced 2.54 mm apart, perfectly centered on the Y = 50.00 mm centerline).
   * Columns (X-Axis): There are 32 columns spaced 2.54 mm apart. The center point of the pin array falls exactly between column 16 and column 17. The distance from Pin 1 to Pin 32 along the X-axis is 78.74 mm (31 × 2.54 mm).

## Mechanical Grid Overview

       <----------------------- 71.12 mm (14 HP) ----------------------->

       |                                                                |
+-----------------------------------------------------------------------------------+

|      |                        Slot 1 Center                           |           |
|      v                              v                                 v           |
|     (O) Fixing Hole (Y=95.00)      (O)                               (O)          |
|      |                              |                                 |           |
|    +---+ Row c (Y=51.27)          +---+                             +---+         |
|    |:::|                          |:::|                             |:::|         |
|----|:::|-- Centerline (Y=50.00)---|:::|-----------------------------|:::|---------|
|    |:::|                          |:::|                             |:::|         |
|    +---+ Row a (Y=48.73)          +---+                             +---+         |
|      |                              |                                 |           |
|     (O) Fixing Hole (Y=5.00)       (O)                               (O)          |
|                                                                                   |
+-----------------------------------------------------------------------------------+
       ^                              ^                                 ^

       |---- X = 15.24 mm (Slot 1) ---|----------- X = 86.36 mm --------| (Slot 2)

## Free CAD Models for Type B Connectors
To quickly drop the 3D footprint into your backplane design layout:

* Footprints: You can grab the exact footprint and 3D .STP file directly from the TE Connectivity 64-Position Type B Eurocard Connector Page or Harting's DIN 41612 Type B Catalog.
* Clearance Check: Ensure your PCB layout keeps a 0.8 mm minimum trace clearance around the 90 mm fixing holes, as those will be bolted directly to the subrack's metallic, grounded rear rails.

Would you like me to map out the exact schematic pin numbering scheme for rows A and C, or help you calculate the total physical width your backplane PCB will need based on how many 14 HP slots you want to include?

For a standard 3U Eurocard backplane with 14 HP (71.12 mm) module spacing and HARTING 09021326921 (DIN 41612 Type B) connectors, the mechanical design is strictly defined by IEC 60297-3-101 standards to ensure subrack interchangeability. [1, 2] 
## 1. Backplane PCB Overall Size
The dimensions for a standard 3U backplane are constrained by the subrack's internal opening and mounting rail positions. [3] 

* Physical Height: Typically 128.55 mm.
* Width: This depends on the number of slots. For a 14 HP pitch, calculate the width as (Number of Slots * 71.12 mm) + Side Margin. A 3U 84 HP subrack generally accommodates up to six 14 HP modules.
* Thickness: Standard backplane PCBs are typically 1.6 mm or 2 mm thick. [3] 

## 2. Drill Hole Locations (PCB Mounting)
The backplane attaches to the subrack's rear horizontal rails via dedicated mounting holes. [4, 5] 

* Vertical Mounting Hole Spacing: The center-to-center distance between top and bottom mounting holes is 122.5 mm.
* Horizontal Pitch: Mounting holes are spaced at multiples of 1 HP (5.08 mm). For 14 HP modules, you will typically place mounting holes every 71.12 mm to align with the module slots. [3] 

## 3. Connector PIN Positions (X, Y Coordinates)
The HARTING 09021326921 connector features a 2.54 mm pitch and uses Rows a and b. The alignment is always referenced from the bottom of the subrack. [4, 6, 7] 

| Feature [3, 6, 8] | Coordinate Detail |
|---|---|
| Vertical Centerline (Y-axis) | Fixed at 50.00 mm from the bottom card-guide datum. |
| Row Positions (Y) | Row 'a' sits at Y = 48.73 mm; Row 'b' sits at Y = 51.27 mm. |
| Horizontal Centerline (X-axis) | Centered within the 71.12 mm (14 HP) slot allocation. |
| Column Spacing (X) | 32 columns spaced at 2.54 mm intervals (approx. 78.74 mm total pin width). |

## 4. HARTING 09021326921 Key Specs
This specific right-angle male connector is designed for secure through-hole mounting. [6] 

* Termination: Solder pins for through-hole PCB assembly.
* Mounting: Features two fixing flanges at the ends of the housing to secure the connector to the backplane PCB.
* Current Rating: Up to 2.0 A per pin.
* Durability: Rated for up to 400–500 mating cycles. [6, 9, 10, 11] 

## Design Recommendations

* Reference Datum: Always use the inside face of the bottom guide rail as your Y=0.00 mm reference point. [4] 
* Insulation Strips: Ensure your backplane design accounts for the Schroff insulation strip that sits between the backplane and the horizontal rail to prevent shorts. [5, 12] 
* CAD Models: You can download native 3D step files for your 175 mm depth subrack parts from the [nVent Schroff official portal](https://www.nvent.com/en-us/schroff/products/enc24563-131) to verify all mounting hole alignments. [5] 

Does this summary provide the specific drill coordinates you need for your KiCad layout, or would you like to verify the exact trace clearance required around the mounting flanges?

[1] [https://standards.iteh.ai](https://standards.iteh.ai/catalog/standards/clc/5e849e32-5b8d-4003-81e5-6a1557b2fef3/en-60297-3-101-2004)
[2] [https://standards.iteh.ai](https://standards.iteh.ai/catalog/standards/iec/bdebd5ce-2634-49b6-882c-97d1ca555e47/iec-60297-3-101-2004)
[3] [https://subrack.eu](https://subrack.eu/423-subrack/)
[4] [https://www.nvent.com](https://www.nvent.com/sites/default/files/acquiadam_assets/2023-04/6_1_schroff_cat_europacpro_en.pdf)
[5] [https://www.nvent.com](https://www.nvent.com/en-us/schroff/products/enc24567-149)
[6] [https://www.utmel.com](https://www.utmel.com/productdetail/harting-09231482921-5407667)
[7] [https://www.mouser.com](https://www.mouser.com/new/amphenol/amphenol-fci-din-41612-connectors/)
[8] [https://www.rtlecs.com](https://www.rtlecs.com/Products_36/102.html)
[9] [https://www.eptusa.com](https://www.eptusa.com/index.php?101-60064_en)
[10] [https://www.mouser.com](https://www.mouser.com/pdfDocs/ds-CCS-AIM-DIN-41612-connectors.pdf)
[11] [https://www.ept-connectors.com](https://www.ept-connectors.com/index.php?110-40064_en)
[12] [https://docs.rs-online.com](https://docs.rs-online.com/ef71/A700000010542646.pdf)

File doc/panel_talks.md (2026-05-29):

A 71 mm wide front panel corresponds to an industry-standard 14 HP Eurocard module width (nominally 70.78 mm to 71.12 mm). [1, 2] 
According to standard Schroff configurations for a 14 HP front panel, the module's component board is not centered down the exact middle of the 71 mm frame. Instead, the PCB card-guides align the card closer to the left edge to maintain the standardized chassis slot intervals. [3] 
The drill holes for your 60807-011 brackets must be placed at the following absolute panel coordinates: [3] 
## 1. Absolute Drill Hole Coordinates
Measure your dimensions from the Left-Most Edge and the Top-Most Edge of the raw aluminum front panel:

* Horizontal Position (X-Axis): 35.22 mm from the left-most edge.
* Upper Hole Vertical Position (Y-Axis): 14.20 mm down from the top edge.
* Lower Hole Vertical Position (Y-Axis): 114.20 mm down from the top edge. [2] 

(Note: The absolute vertical distance between your two drilled holes will be exactly 100.00 mm).
------------------------------
## 2. Panel Mounting Screw Hole Coordinates (To Secure Panel to Subrack Rails)
Because a 14 HP module is wide, it must be secured to the chassis subrack frame using its own peripheral mounting screws (independent of the PCB bracket screws). [3] 
To secure the panel itself to your subrack rails, add your external subrack mounting holes at these coordinates: [3] 

* Top-Left Subrack Hole: 7.45 mm from the left edge, 4.00 mm down from the top edge.
* Bottom-Left Subrack Hole: 7.45 mm from the left edge, 124.40 mm down from the top edge (or 4.00 mm up from the bottom).
* Top-Right Subrack Hole: 63.33 mm from the left edge, 4.00 mm down from the top edge.
* Bottom-Right Subrack Hole: 63.33 mm from the left edge, 124.40 mm down from the top edge. [4] 

------------------------------
## 3. Clear Visual Summary for Fabricating Your Front Panel
Use this 2D dimensional map when drilling or programming your CNC mill profile:

  0,0 (TOP-LEFT CORNER)
   +-----------------------------------------------------------+

   |   (O) 7.45mm, 4.00mm                         (O) 63.33mm  | <-- Chassis Rail Screws
   |                                                           |
   |                                                           |
   |                ( ) 35.22mm, 14.20mm                       | <-- UPPER BRACKET (60807-011)
   |                                                           |
   |                                                           |
   |                                                           |
   |                                                           |
   |                                                           |
   |                                                           |
   |                ( ) 35.22mm, 114.20mm                      | <-- LOWER BRACKET (60807-011)
   |                                                           |
   |                                                           |
   |   (O) 7.45mm, 124.40mm                       (O) 63.33mm  | <-- Chassis Rail Screws
   +-----------------------------------------------------------+
                                                               71.00mm, 128.40mm

## 4. Technical Design Reminders

* Drill Sizes: Use a 2.6 mm to 2.8 mm drill bit for the bracket holes at the 35.22 mm line to allow clean pass-through for the M2.5 screws. Use a 5.9 mm to 6.0 mm bit for the outer four subrack rail holes to clear standard subrack M2.5 collar sleeves.
* Chassis Clearance: The standard total vertical height of this front panel is 128.40 mm. [1, 2, 4, 5] 

Are you handling this panel milling manually on a drill press, or would a standard DXF profile file help you load it directly into CAM/CNC machining software?

[1] [https://uk.rs-online.com](https://uk.rs-online.com/web/p/rack-panels/4372028)
[2] [https://www.nvent.com](https://www.nvent.com/en-at/schroff/products/front-panel)
[3] [https://www.nvent.com](https://www.nvent.com/sites/default/files/acquiadam_assets/2023-04/7_1_schroff_cat_frontpanels_en.pdf)
[4] [https://www.farnell.com](https://www.farnell.com/datasheets/2622644.pdf)
[5] [https://www.nvent.com](https://www.nvent.com/en-us/schroff/products/enc20846-450)

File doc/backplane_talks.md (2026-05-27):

Eurocard backplane spacing relies on standardized dimensions established by IEC-60297-3 and IEEE 1101.1/.10. Backplane connectors (typically DIN 41612) feature a standard contact pitch (centerline) of $2.54\text{ mm}$ (0.1 in). Row-to-row spacing varies between $2.54\text{ mm}$, $3.81\text{ mm}$, $4.3\text{ mm}$, and $5.08\text{ mm}$, depending on the specific connector type (e.g., B, C, R, M). [1, 2, 3, 4, 5, 6] 
The layout of Eurocard connectors is highly standardized: [2] 
## Contact Pitch (Pin Spacing)

* Centerline (Pitch): $2.54\text{ mm}$ $[0.1\text{ in}]$ between individual pins.
* Row Spacing: Standard spacing between rows of pins is typically $2.54\text{ mm}$ $[0.1\text{ in}]$ for standard 3-row connectors, or $5.08\text{ mm}$ $[0.2\text{ in}]$ depending on the type. [3, 5] 

## Row & Pin Configurations (DIN 41612)
Eurocards commonly utilize DIN 41612 indirect edge connectors. The most common configurations include: [7, 8, 9] 

* Type B: 2 rows ($32$ or $64$ positions).
* Type C: 3 rows ($32$, $64$, or $96$ positions).
* Type R: Standardized for rear-plugging backplanes.
* Type M: Mixed layouts that accommodate high-power or coaxial contacts alongside standard signal pins. [6, 10, 11, 12, 13, 14] 

## Board-to-Board Spacing (Subrack Pitch)
The physical spacing of the cards themselves in a subrack (i.e., how far apart the PCBs are on the backplane) is measured in Horizontal Pitch (HP). [15] 

* $1\text{ HP}$ = $0.2\text{ in}$ ($5.08\text{ mm}$).
* The most common subrack slot spacing is $4\text{ HP}$ ($20.32\text{ mm}$) or $5\text{ HP}$ ($25.4\text{ mm}$). [15] 

## Standard Eurocard Board Sizes

* 3U: $100\text{ mm} \times 160\text{ mm}$ $[0.5.14]$ (utilizes a single connector, usually on the bottom)
* 6U: $233.4\text{ mm} \times 160\text{ mm}$ $[0.5.14]$ (can utilize multiple connectors or larger high-density Type M connectors)

To explore compatible backplane connectors or verify part geometries for your design, you can browse the official selection on the [TE Connectivity Eurocard Connectors](https://www.te.com/en/plp/eurocard-backplane-connectors/ZnB9Y30my.html) or [Mouser DIN 41612 Connectors](https://www.mouser.com/c/connectors/backplane-connectors/din-41612-connectors/?series=Eurocard) portals.

[1] [https://www.te.com](https://www.te.com/en/product-2-166648-4.html)
[2] [https://peakservo.com](https://peakservo.com/products/what-is-a-eurocard/)
[3] [https://www.farnell.com](https://www.farnell.com/datasheets/4503726.pdf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)
[4] [https://www.te.com](https://www.te.com/en/product-166569-1.html)
[5] [https://www.te.com](https://www.te.com/en/product-5536406-5.html)
[6] [https://www.farnell.com](https://www.farnell.com/datasheets/1731380.pdf)
[7] [https://uk.rs-online.com](https://uk.rs-online.com/web/p/backplanes-motherboards/0435327)
[8] [https://www.unitro.de](https://www.unitro.de/produktunterlagen/19_zoll_kartentechnik/Englisch/Installation_options_for_eurocard_format.pdf)
[9] [https://electronics.stackexchange.com](https://electronics.stackexchange.com/questions/504031/eurocard-backplane-dimensions)
[10] [https://no.rs-online.com](https://no.rs-online.com/web/p/backplane-connectors/0506005)
[11] [https://au.element14.com](https://au.element14.com/amp-te-connectivity/536052-5/backplane-conn-r-a-header-64pos/dp/3791447)
[12] [https://www.te.com](https://www.te.com/en/product-5536386-5.html)
[13] [https://www.te.com](https://www.te.com/en/product-650870-4.html)
[14] [https://www.te.com](https://www.te.com/en/product-5650919-5.html)
[15] [https://en.wikipedia.org](https://en.wikipedia.org/wiki/Eurocard_%28printed_circuit_board%29)

With 71 mm wide panels for your 3U Eurocards, your card-to-card connector spacing must be exactly 14 HP (Horizontal Pitch), which equals 71.12 mm (2.8 inches) from the centerline of one DIN 41612 B connector to the next.
In a standard 19-inch subrack, the total usable width is exactly 84 HP (426.72 mm). Since you are placing six cards across the row, the math aligns perfectly with the standard Eurocard structural grid.
## Backplane Connector Spacing Dimensions

* Center-to-Center Spacing: $71.12 \text{ mm}$ ($14 \text{ HP}$).
* Total Width Used: $426.72 \text{ mm}$ ($84 \text{ HP}$ total for 6 cards).
* Panel Clearance: Your $71 \text{ mm}$ panels leave a nominal $0.12 \text{ mm}$ gap between adjacent panels. This provides the necessary mechanical clearance to prevent binding when inserting or removing cards.

## DIN 41612 Type B Alignment
Since you are using 3U cards with 32-pin Type B connectors, the connectors will sit on the lower portion of the 3U card profile.

* Vertical Position: The centerline of the connector is strictly dictated by the subrack rails, typically aligned so that the card guides slide seamlessly into the backplane mating zone.
* Connector Pitch: Each connector features 2 rows of 16 pins spaced at $2.54 \text{ mm}$ internally, but the entire housing will repeat precisely every $71.12 \text{ mm}$ horizontally across your backplane PCB.

If you are laying out the backplane PCB, you can easily set your grid spacing to 5.08 mm (1 HP) or 2.54 mm (0.5 HP) in your CAD software. Placing a connector guide every 14 grid clicks (at 5.08 mm) ensures perfect mechanical alignment with your subrack rails and card front panels.
If you'd like, let me know:

* If you are designing a custom backplane PCB or assembling discrete rails.
* The exact height of your front panels (to check for standard 3U or extended lip sizes).
* If you need the exact vertical offset coordinates for the connector pins relative to the card guide.

For a custom backplane design, aligning the PCB layout with standard mechanical subrack datums is critical to avoid alignment issues.
Your horizontal spacing remains exactly 71.12 mm (14 HP) between connector centerlines across both the current 3U row and the future 6U row.
## Vertical Offset & PCB Datums
Eurocard mechanical standards (IEEE 1101.1 / IEC 60297-3) define vertical offsets relative to the inside surface of the lower card guide rail. This surface acts as the mechanical datum ($Y = 0.00\text{ mm}$) for the plug-in card.
For the backplane PCB, the standard datum point ($Y = 0.00\text{ mm}$) is typically aligned with the bottom edge of the backplane insulation strip or the bottom edge of the subrack's usable backplane area.
## 1. Current 3U Row Alignment
Your $132.5\text{ mm}$ panel height aligns perfectly with standard 3U dimensions (exactly $128.5\text{ mm}$ plus a typical $2\text{ mm}$ top/bottom lip overhang).

* Card PCB Height: $100.00\text{ mm}$ nominal.
* DIN 41612 Connector Vertical Offset: The centerline of the lower connector (or a single connector on a 3U board) is exactly $11.43\text{ mm}$ ($0.450\text{ in}$) up from the inside surface of the bottom card guide rail ($Y = 0.00\text{ mm}$).
* Pin 1 (Row A) Coordinates: Pin 1A sits at $3.81\text{ mm}$ ($0.150\text{ in}$) above the bottom card guide datum.

## 2. Future 6U Row Alignment
Your $265.9\text{ mm}$ front panels and $200\text{ mm}$ cards are a slight departure from standard 6U specifications. Standard 6U front panels are $261.9\text{ mm}$ high to clear standard subrack frames, and standard 6U cards are $233.35\text{ mm}$ high. Because your cards are non-standard ($200\text{ mm}$), you must manually map the second connector position if you intend to use two connectors per card.

* Bottom Connector Offset: Stays identical to the 3U row. Centerline is at $11.43\text{ mm}$ from the bottom card guide datum.
* Top Connector Offset (Custom for $200\text{ mm}$ Card): Standard 6U subracks place the upper connector centerline at $11.43\text{ mm}$ down from the top card guide datum. For a standard $233.35\text{ mm}$ card, this centers the upper connector at $221.92\text{ mm}$ from the bottom datum. Because your card is shortened to $200\text{ mm}$, your upper connector centerline must be placed at exactly $188.57\text{ mm}$ up from the bottom card guide datum to match the top edge of your card profile.

## Summary CAD Layout Table
When creating your custom backplane in your CAD software, set your origin $(X=0, Y=0)$ at the center of Pin 1 (Row A) of your first slot's bottom connector. Use this relative spacing guide:

| Parameter | 3U Row Layout | Future 6U Row Layout |
|---|---|---|
| Horizontal Slot Step ($X$) | Add $71.12\text{ mm}$ per slot | Add $71.12\text{ mm}$ per slot |
| Bottom Connector Centerline ($Y$) | $7.62\text{ mm}$ above Pin 1A | $7.62\text{ mm}$ above Pin 1A |
| Top Connector Centerline ($Y$) | None | $184.76\text{ mm}$ above Pin 1A |

Would you like me to clarify the exact $X/Y$ drilling coordinates for the DIN 41612 B mounting holes relative to the pins, or do you need help verifying if your $265.9\text{ mm}$ panels will physically clear a standard 19-inch subrack frame?

For the nVent Schroff EuropacPRO (24563-133) subrack, layout dimensions are tightly bound to standard Eurocard mechanics. [1, 2] 
## 1. Estimated Backplane Dimensions

* Total Width: $431.8\text{ mm}$ ($17.0\text{ inches}$). While the physical opening inside the chassis for front panels is $426.72\text{ mm}$ ($84\text{ HP}$), the horizontal aluminum backplane rails themselves span the full distance between the $2\text{ mm}$ thick side plates, pushing the raw PCB board width to $431.8\text{ mm}$.
* Total Height (3U Backplane): $128.5\text{ mm}$ nominal. Standard practice trims this to roughly $128.0\text{ mm}$ to guarantee vertical clearance inside the chassis frame profile. [1, 2, 3] 

## 2. Defining the Origin $(0,0)$ Coordinate
For backplane layouts, setting the origin $(X=0, Y=0)$ to a physical structural point—the bottom-left corner of the backplane PCB—simplifies CAD routing.
When your PCB is fabricated to the standard $431.8\text{ mm} \times 128.0\text{ mm}$ dimensions, the first connector locates relative to this corner boundary.

+--------------------------------------------------------------+  Y = 128mm (Top Edge)

|                                                              |
|                                                              |
|   +---+  +---+  +---+  +---+  +---+  +---+                   |
|   | 1 |  | 2 |  | 3 |  | 4 |  | 5 |  | 6 |                   |
|   | B |  | B |  | B |  | B |  | B |  | B |                   |
|   +---+  +---+  +---+  +---+  +---+  +---+                   |
|     |                                                        |
|     v                                                        |
|   (Slot 1 Centerline Pin 1A)                                 |
+--------------------------------------------------------------+  Y = 0mm (Bottom Edge)
X=0mm (Left Edge)                                              X = 431.8mm (Right Edge)

## 3. Connector Placements Relative to $(0,0)$
The leftmost edge of the card-insertion area sits exactly $2.54\text{ mm}$ inside the left wall of the subrack. Based on this standard orientation, the specific offsets map directly to your grid:
## Slot 1 Location (First Card on the Left)

* First Card Centerline ($X$): The first slot centerline sits at $2.54\text{ mm}$ (clearance offset) + $2.54\text{ mm}$ ($0.5\text{ HP}$ to the midplane of slot 1) = $5.08\text{ mm}$.
* DIN 41612 B Pin 1A ($X$): The physical columns of pins are centered on the slot midline, meaning $X = 5.08\text{ mm}$ for Pin 1A.

## Vertical Alignment ($Y$)

* Bottom Rails Offset: The gap between the bottom edge of the backplane PCB and the inside surface of the bottom card guide rail is standardly $4.00\text{ mm}$.
* DIN 41612 B Pin 1A ($Y$): Adding the mandatory standard vertical offset ($3.81\text{ mm}$) to the bottom rail gap places Pin 1A exactly $7.81\text{ mm}$ up from the bottom edge of your custom backplane.

## CAD Setup Coordinate Reference
To map out your first connector footprints on your layout program relative to your PCB's absolute bottom-left corner $(0,0)$, use these starting reference points:

* Pin 1A (Row A, Column 1): $X = 5.08\text{ mm} \quad\vert\quad Y = 7.81\text{ mm}$
* Pin 1B (Row B, Column 1): $X = 7.62\text{ mm} \quad\vert\quad Y = 7.81\text{ mm}$ (based on standard 2-row $2.54\text{ mm}$ row spacing)
* Slot-to-Slot Progression: Add exactly $71.12\text{ mm}$ to the $X$ coordinates for each subsequent slot (Slot 2, Slot 3, up to Slot 6).

If you plan to utilize mounting holes along the top and bottom margins of the custom backplane to anchor it into the Schroff frame's rear rails, let me know. I can provide the standard mechanical hole intervals for the mounting tracks. [1] 

[1] [https://uk.farnell.com](https://uk.farnell.com/schroff/24563-133/subrack-3u-295mm-84hp/dp/1455788)
[2] [https://www.nvent.com](https://www.nvent.com/sites/default/files/acquiadam_assets/2023-04/6_1_schroff_cat_europacpro_en.pdf)
[3] [https://www.nvent.com](https://www.nvent.com/en-us/schroff/products/enc24563-433)

For your custom backplane to physically mount to the rear horizontal rails of the nVent Schroff EuropacPRO (24563-133) chassis, the mounting holes must align with the standard patterns embedded in the aluminum horizontal tracks. [1] 
Schroff rails feature pre-drilled M2.5 threaded holes spaced precisely at $1\text{ HP}$ ($5.08\text{ mm}$) increments horizontally across the length of the rear tracks. [2] 
## 1. Vertical Hole Offsets (Y-Axis)
Standard 3U Schroff backplane mounting rails expect a vertical distance of exactly $121.92\text{ mm}$ ($4.80\text{ in}$) between the top and bottom rows of chassis mounting screws.
Assuming you maintain the standard $128.00\text{ mm}$ total backplane height, the holes are centered symmetrically with a $3.04\text{ mm}$ margin from the board's top and bottom cut edges:

* Bottom Mounting Hole Row: $Y = 3.04\text{ mm}$
* Top Mounting Hole Row: $Y = 124.96\text{ mm}$ ($3.04\text{ mm} + 121.92\text{ mm}$)

Note: For reference, this places the centerline of your DIN 41612 B connector Pin 1A ($Y = 7.81\text{ mm}$) exactly $4.77\text{ mm}$ above the center of your bottom mounting screws.
## 2. Horizontal Hole Pitches (X-Axis)
Because the frame's internal tracks have holes spaced every $5.08\text{ mm}$, you can space your backplane's mounting screws to match your card layout.
Since your card slots repeat every $14\text{ HP}$ ($71.12\text{ mm}$), the most common practice is to place a mounting hole pair (one top, one bottom) aligned perfectly with the midplanes of your slots, plus anchoring holes at the outer board flanges.
Using the same absolute bottom-left corner $(0,0)$ datum as before, your layout drilling coordinates should be:
## Perimeter/Flange Holes (Anchoring the outer edges)

* Left Edge Anchors: $X = 2.54\text{ mm}$ ($0.5\text{ HP}$ inward from the left physical edge)
* Right Edge Anchors: $X = 429.26\text{ mm}$ ($2.54\text{ mm}$ inward from the right physical edge)

## Slot-Aligned Structural Holes
To guarantee rigidity right where the cards exert mechanical force during insertion, align a set of mounting holes directly with each of your 6 connector columns:

* Slot 1 Holes: $X = 5.08\text{ mm}$ (Matches the column centerline for Pin 1A)
* Slot 2 Holes: $X = 76.20\text{ mm}$ ($5.08\text{ mm} + 71.12\text{ mm}$)
* Slot 3 Holes: $X = 147.32\text{ mm}$
* Slot 4 Holes: $X = 218.44\text{ mm}$
* Slot 5 Holes: $X = 289.56\text{ mm}$
* Slot 6 Holes: $X = 360.68\text{ mm}$

## 3. Drilling Specifications

* Hole Diameter: Drill these backplane mounting holes to $3.2\text{ mm}$ ($0.126\text{ in}$). This provides comfortable clearance for the standard M2.5 cheese-head or pan-head screws shipped with Schroff kits, allowing a small amount of mechanical tolerance play during final chassis assembly.
* Keepout Zones: Maintain a copper-free keepout zone (no traces, power planes, or via pads) with a radius of at least $3.0\text{ mm}$ around the center of each mounting hole to clear the screw heads and the non-conductive insulation strips used on the Schroff rails. [3] 

[1] [https://cenval.es](https://cenval.es/img/cms/BLOG%20NEWS/nVent%20SCHROFF%20-%20Cat%C3%A1logo%20EuropacPRO%20%28edicion%202020%29.pdf)
[2] [https://static6.arrow.com](https://static6.arrow.com/aropdfconversion/5cc47eb67d2f235126346757a7b3beb6599c553e/pgurl_2601709329221757_24563-144.pdf)
[3] [https://www.nvent.com](https://www.nvent.com/sites/default/files/acquiadam_assets/2023-04/6_1_schroff_cat_europacpro_en.pdf)

For the future 6U configuration using your custom $200\text{ mm}$ high cards and $265.9\text{ mm}$ front panels, the horizontal spacing and horizontal hole pitches remain exactly the same as the 3U version ($71.12\text{ mm}$ / $14\text{ HP}$ steps).
However, the vertical dimensions change significantly to accommodate the dual horizontal rail system of a 6U Schroff EuropacPRO frame.
## 1. Estimated 6U Backplane Dimensions

* Total Width: $431.8\text{ mm}$ ($17.0\text{ inches}$) (Identical to the 3U row).
* Total Height (6U Backplane): $261.8\text{ mm}$ nominal (Standard practice trims this to roughly $261.3\text{ mm}$ to guarantee clean vertical clearance inside the 6U frame profile).

## 2. Vertical Hole Offsets (Y-Axis)
A standard 6U Schroff frame features two sets of rear mounting rails (an upper pair and a lower pair). Assuming a standard $261.3\text{ mm}$ total backplane height, the mounting holes align symmetrically with a $3.04\text{ mm}$ margin from the top and bottom cut edges:

* Bottom Mounting Hole Row: $Y = 3.04\text{ mm}$
* Top Mounting Hole Row: $Y = 258.26\text{ mm}$ ($3.04\text{ mm} + 255.22\text{ mm}$ standard 6U rail spacing)

## 3. Complete CAD Setup Coordinates (6U Custom Layout)
Using the absolute bottom-left corner of the 6U backplane PCB as your $(0,0)$ datum, map out your mounting holes and DIN 41612 B connector locations with the following coordinates.
## Horizontal Pitches (X-Axis)
The horizontal coordinates apply to both the top and bottom rows of mounting holes, as well as the columns of the bottom and top connectors:

* Left Flange Edge Anchors: $X = 2.54\text{ mm}$
* Slot 1 (Connector Column & Hole): $X = 5.08\text{ mm}$
* Slot 2 (Connector Column & Hole): $X = 76.20\text{ mm}$
* Slot 3 (Connector Column & Hole): $X = 147.32\text{ mm}$
* Slot 4 (Connector Column & Hole): $X = 218.44\text{ mm}$
* Slot 5 (Connector Column & Hole): $X = 289.56\text{ mm}$
* Slot 6 (Connector Column & Hole): $X = 360.68\text{ mm}$
* Right Flange Edge Anchors: $X = 429.26\text{ mm}$

## Vertical Pitches (Y-Axis)

* Bottom Mounting Screws: $Y = 3.04\text{ mm}$
* Bottom Connector Pin 1A: $Y = 7.81\text{ mm}$ (Sits $4.77\text{ mm}$ above the bottom mounting row, identical to the 3U configuration).
* Top Connector Pin 1A: $Y = 192.57\text{ mm}$ (Calculated based on your custom $200\text{ mm}$ card height to align perfectly with the upper mating zone of the shortened card).
* Top Mounting Screws: $Y = 258.26\text{ mm}$

## Drilling & Keepouts

* Hole Diameter: Keep the same $3.2\text{ mm}$ ($0.126\text{ in}$) drill size for M2.5 Schroff chassis screws.
* Keepout Zones: Maintain a minimum $3.0\text{ mm}$ copper-free radius around all mounting hole centers to safely clear the screw heads and the Schroff rear insulation strips.

If you plan to use an intermediate middle rail in your Schroff frame for extra mechanical support due to the $261.3\text{ mm}$ height, let me know. I can provide the standard center-rail vertical drilling coordinates as well.

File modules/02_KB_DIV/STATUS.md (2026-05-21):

# STATUS

0% Complete

- [ ] Schematic
- [ ] Schematic Additions
- [ ] Schematic Review
- [ ] PCB Placement
- [ ] PCB Routing
- [ ] PCB Review
- [ ] Sample
- [ ] Build
- [ ] Calibrated
- [ ] Tested

<!-- ![Rendered PCB](KB_DIV.png "Rendered PCB") -->

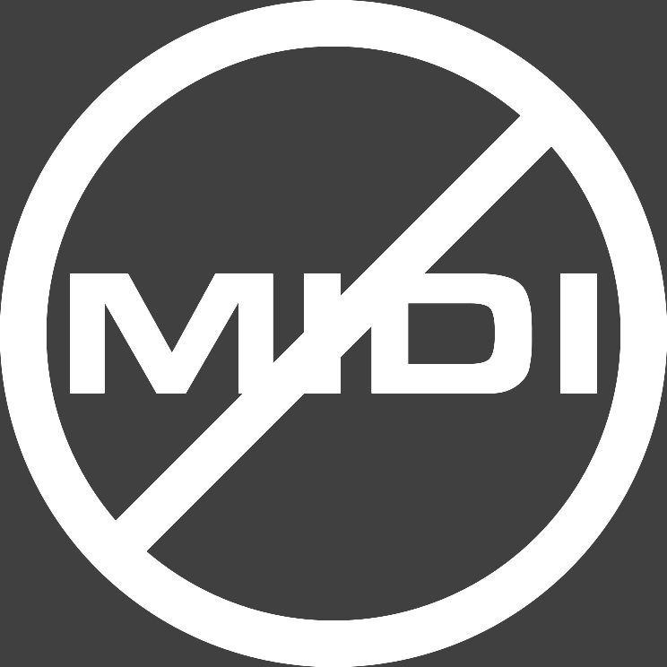
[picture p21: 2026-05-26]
assets/no_midi.png

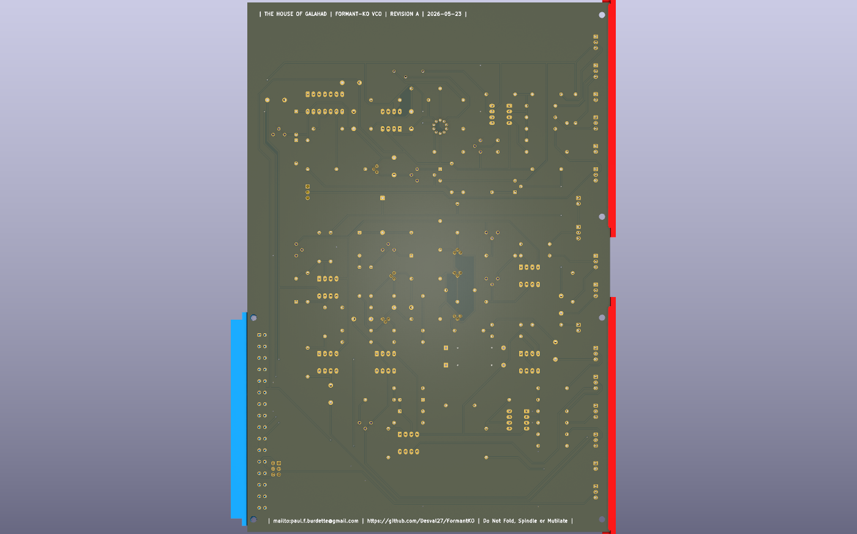
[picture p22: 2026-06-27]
modules/VCO/VCO_bottom.png

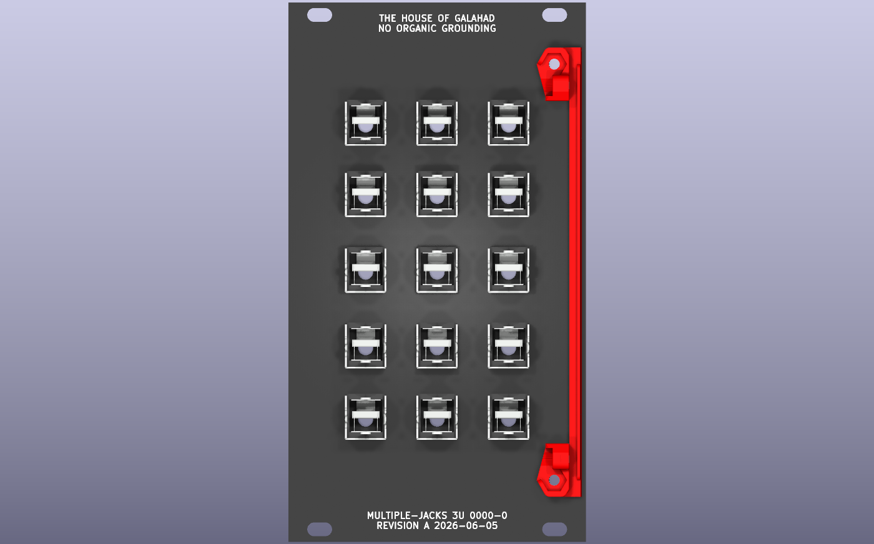
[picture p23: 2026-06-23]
panels/MULTIPLE_JACKS_3U/MULTIPLE_JACKS_3U_back.png

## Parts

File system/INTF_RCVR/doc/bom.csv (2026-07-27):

Reference | Value | Datasheet | Footprint | Qty | DNP
C10 | 220n |  | FormantKO:C_Rect_300 | 1
C11,C12 | 680n |  | FormantKO:C_Rect_300 | 2
D3,D5 | DUS | https://assets.nexperia.com/documents/data-sheet/1N4148_1N4448.pdf | FormantKO:DUS | 2
D4 | DLED |  | FormantKO:PanelConnector_1x02 | 1
IC7,IC8 | µA741C | http://www.ti.com/lit/ds/symlink/lm741.pdf | FormantKO:DIP-8 | 2
J1 | D4a |  | FormantKO:Wire_1x01_General | 1
J2 | D4k |  | FormantKO:Wire_1x01_General | 1
J4,J8 | KOV |  | FormantKO:TerminalBlock_1x04_P5.00mm,FormantKO:Wire_1x01_General | 2
J5,J9 | GATE |  | FormantKO:TerminalBlock_1x04_P5.00mm,FormantKO:Wire_1x01_General | 2
J10,J13 | 0 |  | FormantKO:Wire_1x01_General | 2
J11,J14 | + |  | FormantKO:Wire_1x01_General | 2
J12,J15 | - |  | FormantKO:Wire_1x01_General | 2
P8,R29 | 100k |  | FormantKO:Potentiometer_Trimmer,FormantKO:R_Axial_Horizontal | 2
P9,R30,R31 | 1k |  | FormantKO:Potentiometer_Trimmer,FormantKO:R_Axial_Horizontal | 3

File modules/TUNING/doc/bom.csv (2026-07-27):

Reference | Value | Datasheet | Footprint | Qty | DNP
C1,C2 | 47n |  | FormantKO:C_Rect_300 | 2
C3,C4 | 470n |  | FormantKO:C_Rect_300 | 2
IC1,IC2,IC3 | µA741C | http://www.ti.com/lit/ds/symlink/lm741.pdf | FormantKO:DIP-8 | 3
J1 | Card Connector |  | FormantKO:CardConnector | 1
J2,J4 | EOS |  | FormantKO:PanelConnector_1x02,FormantKO:Wire_1x01_General | 2
J3 | IOS SELECT |  | Connector_PinHeader_2.54mm:PinHeader_2x10_P2.54mm_Vertical | 1
J5 | ⊥ |  | FormantKO:Wire_1x01_General | 1
J6 | S1a |  | FormantKO:Wire_1x01_General | 1
J7 | S1b |  | FormantKO:Wire_1x01_General | 1
J8 | S1m |  | FormantKO:Wire_1x01_General | 1
MH1 | Card Bracket |  | FormantKO:CardBracket | 1
P1,P2 | 1k |  | FormantKO:Potentiometer_Trimmer | 2
P3 | 470R |  | FormantKO:Potentiometer_Trimmer_MultiTurn | 1
R1 | 560R |  | FormantKO:R_Axial_Horizontal | 1
R2 | 10k |  | FormantKO:R_Axial_Horizontal | 1
R3,R4 | 100k |  | FormantKO:R_Axial_Horizontal | 2
R5 | 56k |  | FormantKO:R_Axial_Horizontal | 1
R6 | 470Ω |  | FormantKO:R_Axial_Horizontal | 1
R7 | 220Ω |  |  | 1
S1 | ON/OFF |  | FormantKO:PanelConnector_1x03 | 1

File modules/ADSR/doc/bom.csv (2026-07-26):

Reference | Value | Datasheet | Footprint | Qty | DNP
C1 | 10n |  | FormantKO:C_Rect | 1
C2,C3,C4 | 10µ |  | FormantKO:CP_Axial_500_600_700,FormantKO:CP_Axial_700-900mil,FormantKO:CP_Axial_700-900mil_PinSwap | 3
D1,D2,D3,D4,D5,D7 | 1N4148 | https://www.diodes.com/assets/Datasheets/ds12019.pdf | FormantKO:DO-35_400mil,FormantKO:DO-35_500mil | 6
D6 | ENV IND |  | FormantKO:PanelConnector_1x02_PinSwap | 1
IC1,IC2,IC3,IC4,IC5 | µA741C | http://www.ti.com/lit/ds/symlink/lm741.pdf | FormantKO:DIP-8 | 5
J1 | CardConnector |  | FormantKO:CardConnector | 1
J2 | ENV SELECT |  |  | 1
J3 | GATE SELECT |  |  | 1
J4,J25 | EOS |  | FormantKO:PanelConnector_1x02,FormantKO:Wire_1x01_General | 2
J5 | EXT GATE |  | FormantKO:PanelConnector_1x03 | 1
J6 | NO EXT GATE |  | FormantKO:Jumper_1x02 | 1
J7,J26 | GND |  | FormantKO:Wire_1x01_General | 2
J8 | P1.1 |  | FormantKO:Wire_1x01_General | 1
J9 | P1.3 |  | FormantKO:Wire_1x01_General | 1
J10 | P1.2 |  | FormantKO:Wire_1x01_General | 1
J11 | P2.3 |  | FormantKO:Wire_1x01_General | 1
J12 | P2.2 |  | FormantKO:Wire_1x01_General | 1
J13 | P2.1 |  | FormantKO:Wire_1x01_General | 1
J14 | P3.1 |  | FormantKO:Wire_1x01_General | 1
J15 | P3.3 |  | FormantKO:Wire_1x01_General | 1
J16 | P3.2 |  | FormantKO:Wire_1x01_General | 1
J17 | P4.1 |  | FormantKO:Wire_1x01_General | 1
J18 | P4.2 |  | FormantKO:Wire_1x01_General | 1
J19 | P4.3 |  | FormantKO:Wire_1x01_General | 1
J20 | S1a |  | FormantKO:Wire_1x01_General | 1
J21 | S1b |  | FormantKO:Wire_1x01_General | 1
J22 | S1m |  | FormantKO:Wire_1x01_General | 1
J23 | D6a |  | FormantKO:Wire_1x01_General | 1
J24 | D6k |  | FormantKO:Wire_1x01_General | 1
MH1 | CardBracket |  | FormantKO:CardBracket | 1
P1,P2,P3 | 1M |  | FormantKO:PanelConnector_1x03 | 3
P4,R1,R9,R23,R24 | 10k |  | FormantKO:PanelConnector_1x03_PinSwap,FormantKO:R_Axial_Horizontal | 5
P5 | 25k |  | FormantKO:Potentiometer_Trimmer_PinSwap | 1
R2,R25 | 4k7 |  | FormantKO:R_Axial_Horizontal | 2
R3,R7 | 5k6 |  | FormantKO:R_Axial_Horizontal | 2
R4,R6,R8,R16,R18 | 100k |  | FormantKO:R_Axial_Horizontal | 5
R5,R10,R11,R22 | 33k |  | FormantKO:R_Axial_Horizontal | 4
R12,R26,R27 | 470R |  | FormantKO:R_Axial_Horizontal | 3
R13,R21 | 1k |  | FormantKO:R_Axial_Horizontal | 2
R14,R20 | 27k |  | FormantKO:R_Axial_Horizontal | 2
R15,R19 | 6k8 |  | FormantKO:R_Axial_Horizontal | 2
R17 | 220R |  | FormantKO:R_Axial_Horizontal | 1
S1 | MODE |  | FormantKO:PanelConnector_1x03_PinSwap | 1
T1,T2,T3,T4,T5,T6 | BC108C | https://www.alldatasheet.com/datasheet-pdf/view/607096/CDIL/BC108C.html | FormantKO:TO-18_Wide | 6

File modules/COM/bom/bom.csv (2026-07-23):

Reference | Value | Datasheet | Footprint | Qty | DNP
C1,C2,C9 | 100n |  | FormantKO:C_Rect_300_400 | 3
C3,C4 | 10n |  | FormantKO:C_Rect_300_400 | 2
C5,C6 | 39n |  | FormantKO:C_Rect_300_400 | 2
C7 | 15n |  | FormantKO:C_Rect_300_400 | 1
C8 | 3n3 |  | FormantKO:C_Rect_300_400 | 1
C10,C11,C12 | 680n |  | FormantKO:C_Rect_300_400 | 3
D1,J25 | -15V LED |  | FormantKO:PanelConnector_1x02,FormantKO:Wire_1x01_General | 2
D2 | +5V LED |  | FormantKO:PanelConnector_1x02 | 1
D3,J24 | +15V LED |  | FormantKO:PanelConnector_1x02,FormantKO:Wire_1x01_General | 2
D4,J26 | GATE1 LED |  | FormantKO:PanelConnector_1x02,FormantKO:Wire_1x01_General | 2
D5,J27 | GATE2 LED |  | FormantKO:PanelConnector_1x02,FormantKO:Wire_1x01_General | 2
IC1 | RC4136 |  | FormantKO:DIP-14 | 1
J1 | CardConnector |  | FormantKO:CardConnector | 1
J2 | IS SELECT |  | Connector_PinHeader_2.54mm:PinHeader_2x08_P2.54mm_Vertical | 1
J3 | P1a.1 |  | FormantKO:Wire_1x01_General | 1
J4 | P1a.2 |  | FormantKO:Wire_1x01_General | 1
J5,J19 | OUT 1 |  | FormantKO:PanelConnector_1x02,FormantKO:Wire_1x01_General | 2
J6,J11 | OUT 2 |  | FormantKO:PanelConnector_1x02,FormantKO:Wire_1x01_General | 2
J7 | P1a.3 |  | FormantKO:Wire_1x01_General | 1
J8 | P2.1 |  | FormantKO:Wire_1x01_General | 1
J9 | P2.2 |  | FormantKO:Wire_1x01_General | 1
J10 | P2.3 |  | FormantKO:Wire_1x01_General | 1
J12 | P3.1 |  | FormantKO:Wire_1x01_General | 1
J13 | P3.2 |  | FormantKO:Wire_1x01_General | 1
J14 | P3.3 |  | FormantKO:Wire_1x01_General | 1
J15,J20,J22,J28,J32 | GND |  | FormantKO:Wire_1x01_General | 5
J16 | P1b.1 |  | FormantKO:Wire_1x01_General | 1
J17 | P1b.2 |  | FormantKO:Wire_1x01_General | 1
J18 | P1b.3 |  | FormantKO:Wire_1x01_General | 1
J21 | -15V |  | FormantKO:Wire_1x01_General | 1
J23 | 5V LED |  | FormantKO:Wire_1x01_General | 1
J29 | P4.1 |  | FormantKO:Wire_1x01_General | 1
J30 | P4.2 |  | FormantKO:Wire_1x01_General | 1
J31 | P4.3 |  | FormantKO:Wire_1x01_General | 1
MH1 | CardBracket |  | FormantKO:CardBracket | 1
P1,R19 | 4k7 |  | FormantKO:PanelConnector_1x06,FormantKO:R_Axial_Horizontal | 2
P2,P3,P4,R10,R12 | 100k |  | FormantKO:PanelConnector_1x03,FormantKO:R_Axial_Horizontal | 5
P5 | 250k |  | FormantKO:Potentiometer_Trimmer_PinSwap | 1
R1,R2 | 82k |  | FormantKO:R_Axial_Horizontal | 2
R3,R8,R18 | 470R |  | FormantKO:R_Axial_Horizontal | 3
R4,R6 | 1k5 |  | FormantKO:R_Axial_Horizontal | 2
R5,R7,R11,R13 | 6k8 |  | FormantKO:R_Axial_Horizontal | 4
R9,R14 | 3k9 |  | FormantKO:R_Axial_Horizontal | 2
R15,R17 | 220k |  | FormantKO:R_Axial_Horizontal | 2
R16 | 22k |  | FormantKO:R_Axial_Horizontal | 1
R20,R22 | 680R |  | FormantKO:R_Axial_Horizontal | 2
R21,R24,R27 | 150R |  | FormantKO:R_Axial_Horizontal | 3
R25,R26 | 10k |  | FormantKO:R_Axial_Horizontal | 2
T1,T2 | 2N3904 | https://www.onsemi.com/pub/Collateral/2N3903-D.PDF | FormantKO:TO-92 | 2
TP1 | TestPoint |  | FormantKO:KEYSTONE_5001 | 1

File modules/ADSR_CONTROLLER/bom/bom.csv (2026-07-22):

Reference | Value | Datasheet | Footprint | Qty | DNP
C1 | 10n |  | FormantKO:C_Rect_300 | 1
C2 | 2µ2 |  | Capacitor_THT:CP_Radial_Tantal_D4.5mm_P5.00mm | 1
C3,C4 | 10µ |  | FormantKO:CP_Axial_900 | 2
D1,D2,D3,D6 | DUS | https://assets.nexperia.com/documents/data-sheet/1N4148_1N4448.pdf | FormantKO:DUS | 4
D4,D5 | DUG |  | FormantKO:DUG | 2
IC1,IC2,IC3,IC4,IC5,IC6 | OpAmp | http://www.ti.com/lit/ds/symlink/lm741.pdf | FormantKO:DIP-8 | 6
J1 | CardConnector |  | FormantKO:CardConnector | 1
J2 | GATE SELECT |  | Connector_PinHeader_2.54mm:PinHeader_2x02_P2.54mm_Vertical | 1
J3 | IOS SELECT |  | Connector_PinHeader_2.54mm:PinHeader_2x02_P2.54mm_Vertical | 1
J4 | MonoJack |  | FormantKO:PanelConnector_1x02 | 1
J5 | S1a |  | FormantKO:Wire_1x01_General | 1
J6 | S2a |  | FormantKO:Wire_1x01_General | 1
J7 | S2b |  | FormantKO:Wire_1x01_General | 1
J8 | SQR in |  | FormantKO:Wire_1x01_General | 1
J9,J10,J15 | GND |  | FormantKO:Wire_1x01_General | 3
J11 | P2a |  | FormantKO:Wire_1x01_General | 1
J12 | P2b |  | FormantKO:Wire_1x01_General | 1
J13 | S2m |  | FormantKO:Wire_1x01_General | 1
J14 | S3a |  | FormantKO:Wire_1x01_General | 1
J16 | S1m |  | FormantKO:Wire_1x01_General | 1
J17 | S2c |  | FormantKO:Wire_1x01_General | 1
J18 | S3m |  | FormantKO:Wire_1x01_General | 1
J19 | S3b |  | FormantKO:Wire_1x01_General | 1
MH1 | CardBracket |  | FormantKO:CardBracket | 1
P1,P3,R19 | 1k |  | FormantKO:Potentiometer_Trimmer,FormantKO:Potentiometer_Trimmer_PinSwap,FormantKO:R_Axial_Horizontal | 3
P2 | 1M |  | FormantKO:PanelConnector_1x03 | 1
R1,R2,R4,R8,R9,R10,R13,R14,R21,R26,R27 | 100k |  | FormantKO:R_Axial_Horizontal | 11
R3,R7,R18 | 4k7 |  | FormantKO:R_Axial_Horizontal | 3
R5,R17,R23 | 10k |  | FormantKO:R_Axial_Horizontal | 3
R6,R24 | 27k |  | FormantKO:R_Axial_Horizontal | 2
R11,R16,R22,R30 | 33k |  | FormantKO:R_Axial_Horizontal | 4
R12,R15 | 5k6 |  | FormantKO:R_Axial_Horizontal | 2
R20 | 220R |  | FormantKO:R_Axial_Horizontal | 1
R25,R28 | 6k8 |  | FormantKO:R_Axial_Horizontal | 2
R29 | 330R |  | FormantKO:R_Axial_Horizontal | 1
S1,S3 | SW |  | FormantKO:PanelConnector_1x03 | 2
S2 | MODE |  | FormantKO:PanelConnector_1x04 | 1
T1,T2,T3,T4,T5 | BC109C |  | FormantKO:TO-18_Wide | 5

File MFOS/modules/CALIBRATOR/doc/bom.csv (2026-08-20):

Reference | Value | Datasheet | Footprint | Qty | DNP
C1 | 220µ |  | FormantKO:CP_Radial_P100mil | 1
C2,C8 | 10μ |  | FormantKO:CP_Radial_P100mil | 2
C3,C4,C6,C7 | 100n |  | FormantKO:C_Rect_P200mil | 4
C5,C9 | 220n |  | FormantKO:C_Rect_P200mil | 2
D1,D2 | 1N4148 | https://www.diodes.com/assets/Datasheets/ds12019.pdf | FormantKO:DO-35_P400mil | 2
J1 | MonoJack |  | FormantKO:PanelConnector_1x02 | 1
J2 | Card Connector |  | FormantKO:CardConnector | 1
MH1 | Card Bracket |  | FormantKO:CardBracket | 1
R1,R10,R20 | 10k |  | FormantKO:Potentiometer_Trimmer_MultiTurn,FormantKO:R_Axial_Horizontal_P500mil | 3
R2 | 1k |  | FormantKO:R_Axial_Horizontal_P500mil | 1
R3,R4,R6,R8,R13 | 200k |  | FormantKO:R_Axial_Horizontal_P500mil | 5
R5,R12,R19 | 20k |  | FormantKO:R_Axial_Horizontal_P500mil | 3
R7,R9,R14,R16 | 100k |  | FormantKO:Potentiometer_Trimmer_MultiTurn,FormantKO:R_Axial_Horizontal_P500mil | 4
R11 | 1M |  | FormantKO:PanelConnector_1x03 | 1
R15,R17 | 1k5 |  | FormantKO:R_Axial_Horizontal_P500mil | 2
R18 | 220k |  | FormantKO:R_Axial_Horizontal_P500mil | 1
S1,S2 | SW |  | FormantKO:PanelConnector_1x03 | 2
S3 | SW_Push |  | FormantKO:PanelConnector_1x02 | 1
U1 | 40106 | https://assets.nexperia.com/documents/data-sheet/HEF40106B.pdf | FormantKO:DIP-14N | 1
U2 | 4520 | http://www.intersil.com/content/dam/Intersil/documents/cd45/cd4518bms-20bms.pdf | FormantKO:DIP-16N | 1
U3,U4 | OpAmp | http://www.ti.com/lit/ds/symlink/lm741.pdf | FormantKO:DIP-8N | 2
Z1 | 1N5239B | https://www.onsemi.com/download/data-sheet/pdf/1n5221b-d.pdf | FormantKO:DO-35_P400mil | 1

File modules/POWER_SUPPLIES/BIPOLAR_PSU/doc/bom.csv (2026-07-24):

Reference | Qty | Value | DNP | Exclude from BOM | Exclude from Board | Footprint | Datasheet
C1,C2 | 2 | 470µ |  |  |  | FormantKO:CP_Axial_1000
C3,C4 | 2 | 100n |  |  |  | FormantKO:C_Rect_300
C5,C6 | 2 | 1µ |  |  |  | FormantKO:CP_Radial_Tantal_200
D1,D2,D3,D4 | 4 | type="" model="1N4001" lib="semiconductor.lib" |  |  |  | FormantKO:DO-41_400
F1 | 1 | 315mA |  |  | Excluded from board | FormantKO:FuseHolder_5x20mm
IC1 | 1 | L7815 |  |  |  | 4ms_Package_TO:TO-220-3_Vertical | http://www.st.com/content/ccc/resource/technical/document/datasheet/41/4f/b3/b0/12/d4/47/88/CD00000444.pdf/files/CD00000444.pdf/jcr:content/translations/en.CD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
IC2 | 1 | L7915 |  |  |  | 4ms_Package_TO:TO-220-3_Vertical | http://www.st.com/content/ccc/resource/technical/document/datasheet/c9/16/86/41/c7/2b/45/f2/CD00000450.pdf/files/CD00000450.pdf/jcr:content/translations/en.CD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
J1,J2 | 2 | AC |  |  |  | FormantKO:Wire_1x01_General
J3 | 1 | + |  |  |  | FormantKO:Wire_1x01_General
J4 | 1 | 0 |  |  |  | FormantKO:Wire_1x01_General
J5 | 1 | - |  |  |  | FormantKO:Wire_1x01_General
J6 | 1 | CT |  |  |  | FormantKO:Wire_1x01_General
S1 | 1 | POWER |  |  | Excluded from board
Tr1 | 1 | 36VCT 1500mA |  |  | Excluded from board

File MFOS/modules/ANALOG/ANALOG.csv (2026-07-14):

Reference | Value | Datasheet | Footprint | Qty | DNP
C1,C4 | 100n |  | FormantKO:C_Rect_200 | 2
C2,C3 | 100µ |  | Capacitor_THT:CP_Radial_D8.0mm_P5.00mm | 2
C5,C6 | 470p |  | FormantKO:C_Rect_200 | 2
J1 | Sequencer Bus Connector |  | FormantKO:BusConnector_Full_Male_Horizontal | 1
J2 | QA |  | FormantKO:Wire_2x01_General | 1
J3 | QB |  | FormantKO:Wire_2x01_General | 1
J4 | QC |  | FormantKO:Wire_2x01_General | 1
J5 | QD |  | FormantKO:Wire_2x01_General | 1
J6 | CV1 |  | FormantKO:Wire_1x01_General | 1
J7 | CV2 |  | FormantKO:Wire_1x01_General | 1
J8 | CV3 |  | FormantKO:Wire_1x01_General | 1
J9 | R51-1&2 |  | FormantKO:Wire_1x01_General | 1
J10 | R51-3 |  | FormantKO:Wire_1x01_General | 1
J11,J12 | VSRC |  | FormantKO:Wire_1x01_General | 2
J13,J15,J17,J19,J21,J23,J25,J27,J29,J31,J33,J35,J37,J39,J41,J43 | C |  | FormantKO:Wire_1x01_General | 16
J14,J16,J18,J20,J22,J24,J26,J28,J30,J32,J34,J36,J38,J40,J42,J44 | F |  | FormantKO:Wire_1x01_General | 16
MH1 | CardBracket |  | FormantKO:CardBracket | 1
R1,R72,R74 | 10k |  | FormantKO:R_Axial_Horizontal_400 | 3
R2,R3 | 47k |  | FormantKO:R_Axial_Horizontal_400 | 2
R4,R5,R6,R7,R8,R10,R11,R12,R13,R15,R17,R18,R19,R22,R23,R24,R26,R28,R30,R31,R32,R33,R34,R35,R36,R38,R40,R41,R42,R44,R45,R46,R47,R48,R50,R52,R53,R54,R57,R58,R59,R62,R63,R64,R65,R66,R67,R69,R71,R73 | 100k |  | FormantKO:PanelConnector_1x03,FormantKO:R_Axial_Horizontal_400 | 50
R9,R14,R20,R21,R27,R29,R37,R39,R43,R49,R55,R56,R60,R61,R68,R70 | 2M |  | FormantKO:R_Axial_Horizontal_400 | 16
R25 | 200k |  | FormantKO:R_Axial_Horizontal_400 | 1
R51 | 1M |  | FormantKO:PanelConnector_1x03 | 1
R75 | 22R |  | FormantKO:R_Axial_Horizontal_400 | 1
U1 | TL084 | http://www.ti.com/lit/ds/symlink/tl081.pdf | FormantKO:DIP-14 | 1
U2 | CD4067 | https://assets.nexperia.com/documents/data-sheet/HEF4067B.pdf | FormantKO:DIP-24W | 1
U3 | TL082 | http://www.ti.com/lit/ds/symlink/tl081.pdf | FormantKO:DIP-8 | 1
VS1 | LM4040LP-2.5 | http://www.ti.com/lit/ds/symlink/lm4040-n.pdf | Package_TO_SOT_THT:TO-92_Inline_Wide | 1

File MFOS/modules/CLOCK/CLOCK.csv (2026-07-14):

Reference | Value | Datasheet | Footprint | Qty | DNP
C1,C3,C7,C15,C16,C22 | 10n |  | FormantKO:C_Rect_160,FormantKO:C_Rect_200 | 6
C2,C4,C5,C6 | 20n |  | FormantKO:C_Rect_200 | 4
C8 | 10nf |  | FormantKO:C_Rect_200 | 1
C9,C23 | 20nf |  | FormantKO:C_Rect_160,FormantKO:C_Rect_200 | 2
C10 | 1µ |  | Capacitor_THT:CP_Radial_Tantal_D5.5mm_P2.50mm | 1
C11 | 47p |  | FormantKO:C_Rect_160 | 1
C12,C13,C14,C18 | 1n |  | FormantKO:C_Rect_200 | 4
C17 | 100p |  | FormantKO:C_Rect_200 | 1
C19,C24 | 100n |  | FormantKO:C_Rect_160 | 2
C20,C21 | 10µ |  | Capacitor_THT:CP_Radial_D5.0mm_P2.50mm | 2
D1,D2,D3,D4,D5,D6,D7,D8,D9,D11,D13,D28,D29,D30,D31 | DUS | https://assets.nexperia.com/documents/data-sheet/1N4148_1N4448.pdf | FormantKO:DUS_300 | 15
J1 | Sequencer Bus Connector |  | FormantKO:BusConnector_Full_Male_Horizontal | 1
J2 | CKOUT |  | FormantKO:Wire_1x01_General | 1
J3 | RST |  | FormantKO:Wire_1x01_General | 1
J4 | RIN |  | FormantKO:Wire_1x01_General | 1
J5 | CLR |  | FormantKO:Wire_1x01_General | 1
J6 | RND |  | FormantKO:Wire_1x01_General | 1
J7 | STUP |  | FormantKO:Wire_1x01_General | 1
J8 | STDN |  | FormantKO:Wire_1x01_General | 1
J9 | XCLK |  | FormantKO:Wire_1x01_General | 1
J10 | STRN |  | FormantKO:Wire_1x01_General | 1
J11 | STP |  | FormantKO:Wire_1x01_General | 1
J12 | XSTP |  | FormantKO:Wire_1x01_General | 1
J13 | REV |  | FormantKO:Wire_1x01_General | 1
J14 | R19-1&2 |  | FormantKO:Wire_1x01_General | 1
J15 | R19-3 |  | FormantKO:Wire_1x01_General | 1
J16 | QA |  | FormantKO:Wire_1x01_General | 1
J17 | QB |  | FormantKO:Wire_1x01_General | 1
J18 | QC |  | FormantKO:Wire_1x01_General | 1
J19 | QD |  | FormantKO:Wire_1x01_General | 1
J20 | 0 |  | FormantKO:Wire_2x01_General | 1
J21 | 1 |  | FormantKO:Wire_2x01_General | 1
J22 | 2 |  | FormantKO:Wire_2x01_General | 1
J23 | 3 |  | FormantKO:Wire_2x01_General | 1
J24 | 4 |  | FormantKO:Wire_2x01_General | 1
J25 | 5 |  | FormantKO:Wire_2x01_General | 1
J26 | 6 |  | FormantKO:Wire_2x01_General | 1
J27 | 7 |  | FormantKO:Wire_2x01_General | 1
J28 | 8 |  | FormantKO:Wire_2x01_General | 1
J29 | 9 |  | FormantKO:Wire_2x01_General | 1
J30 | 10 |  | FormantKO:Wire_2x01_General | 1
J31 | 11 |  | FormantKO:Wire_2x01_General | 1
J32 | 12 |  | FormantKO:Wire_2x01_General | 1
J33 | 13 |  | FormantKO:Wire_2x01_General | 1
J34 | 14 |  | FormantKO:Wire_2x01_General | 1
J35 | 15 |  | FormantKO:Wire_2x01_General | 1
J36 | GB |  | FormantKO:Wire_1x01_General | 1
J37 | CBUS |  | FormantKO:Wire_1x01_General | 1
J38 | TRIG |  | FormantKO:Wire_1x01_General | 1
J39 | GATE |  | FormantKO:Wire_1x01_General | 1
LED1 | DLED |  | FormantKO:PanelConnector_1x02 | 1
MH1 | CardBracket |  | FormantKO:CardBracket | 1
Q1 | 2N3904 | https://www.onsemi.com/pub/Collateral/2N3903-D.PDF | Package_TO_SOT_THT:TO-92_Inline_Wide | 1
R1,R5,R10,R11,R17,R20,R39 | 10k |  | FormantKO:R_Axial_Horizontal_400 | 7
R2,R6,R15,R22 | 680k |  | FormantKO:R_Axial_Horizontal_400 | 4
R3,R7,R16,R21 | 220k |  | FormantKO:R_Axial_Horizontal_400 | 4
R4,R8,R12,R40 | 47k |  | FormantKO:R_Axial_Horizontal_400 | 4
R9,R26,R28,R32,R44,R45,R46,R47 | 100k |  | FormantKO:R_Axial_Horizontal_400 | 8
R13,R14,R19,R33,R38 | 1M |  | FormantKO:PanelConnector_1x03,FormantKO:R_Axial_Horizontal_400 | 5
R18 | 20k |  | FormantKO:R_Axial_Horizontal_400 | 1
R23 | 6k2 |  | FormantKO:R_Axial_Horizontal_400 | 1
R24,R30 | 3k |  | FormantKO:R_Axial_Horizontal_400 | 2
R25 | 4K7 |  | FormantKO:R_Axial_Horizontal_400 | 1
R27,R29,R41,R42 | 1k |  | FormantKO:R_Axial_Horizontal_400 | 4
R31,R35 | 2M |  | FormantKO:R_Axial_Horizontal_400 | 2
R34,R37 | 4k7 |  | FormantKO:R_Axial_Horizontal_400 | 2
R36 | 4M7 |  | FormantKO:R_Axial_Horizontal_400 | 1
R43 | 3k9 |  | FormantKO:R_Axial_Horizontal_400 | 1
S1 | FORWARD |  | FormantKO:PanelConnector_1x02 | 1
S2 | BACK |  | FormantKO:PanelConnector_1x02 | 1
S3 | RESET |  | FormantKO:PanelConnector_1x02 | 1
S4 | STOP/RUN |  | FormantKO:PanelConnector_1x02 | 1
TP1 | TestPoint |  | FormantKO:KEYSTONE_5001 | 1
U1,U2,U6 | 40106 | https://assets.nexperia.com/documents/data-sheet/HEF40106B.pdf | FormantKO:DIP-14 | 3
U3 | 4013 | http://www.onsemi.com/pub/Collateral/MC14013B-D.PDF | FormantKO:DIP-14 | 1
U4 | 40193 |  | FormantKO:DIP-16 | 1
U5 | 4514 |  | FormantKO:DIP-24W | 1
U7 | TL082 |  | FormantKO:DIP-8 | 1
U8 | HEF4094B | https://assets.nexperia.com/documents/data-sheet/HEF4094B.pdf | FormantKO:DIP-16 | 1

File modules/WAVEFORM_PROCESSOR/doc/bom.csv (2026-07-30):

Reference | Value | Datasheet | Footprint | Qty | DNP
C1,C2,C3 | 560n |  | FormantKO:C_Rect_P200mil | 3
C4,C5 | 10µ |  | FormantKO:CP_Axial_P600mil | 2
D1 | DUS | https://assets.nexperia.com/documents/data-sheet/1N4148_1N4448.pdf | FormantKO:DO-35_P400mil | 1
IC1,IC2,IC3 | µA741C | http://www.ti.com/lit/ds/symlink/lm741.pdf | FormantKO:DIP-8N | 3
J1 | Card Connector |  | FormantKO:CardConnector | 1
J2,J3,J4,J5 | Mono_Jack |  | FormantKO:PanelConnector_1x02 | 4
MH1 | CardBracket |  | FormantKO:CardBracket | 1
P1,P2,R6 | 100k |  | FormantKO:PanelConnector_1x03,FormantKO:R_Axial_Horizontal_P500mil | 3
P3,P4 | 50k |  | FormantKO:PanelConnector_1x03 | 2
P5 | 10k |  | FormantKO:PanelConnector_1x03 | 1
R1,R2,R8,R9 | 56k |  | FormantKO:R_Axial_Horizontal_P500mil | 4
R3,R7 | 120k |  | FormantKO:R_Axial_Horizontal_P500mil | 2
R4 | 5k6 |  | FormantKO:R_Axial_Horizontal_P500mil | 1
R5 | 470k |  | FormantKO:R_Axial_Horizontal_P500mil | 1
R10 | 82k |  | FormantKO:R_Axial_Horizontal_P500mil | 1
R11 | 470Ω |  | FormantKO:R_Axial_Horizontal_P500mil | 1

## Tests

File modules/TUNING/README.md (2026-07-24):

# TUNING

Format: 3U

The **Tuning Module** provides a stable and convenient pitch reference for calibrating the synthesizer. It generates a fixed reference tone and/or precision control voltage that allows VCOs to be adjusted for correct tuning, octave tracking, and consistency across the system. Rather than being used as part of a patch during performance, it serves as a workshop and maintenance tool, making oscillator calibration faster, more accurate, and repeatable after construction, repair, or periodic adjustment.

## Status

⚠️ Untested ⚠️

## Documents

- [English Translation](doc/TUNING__en.pdf)
- [Schematic](doc/schematic.pdf)
- [Assembly](doc/assembly.pdf)
- [Bill of Materials](doc/bom.csv)
- [Interactive Bill of Materials](doc/ibom.html)

## Gerber to Order

⚠️ Untested ⚠️

- [Default](gerber_to_order/TUNING_160.0x100.0mm_for_Default.zip)
- [Elecrow](gerber_to_order/TUNING_160.0x100.0mm_for_Elecrow.zip)
- [FusionPCB](gerber_to_order/TUNING_160.0x100.0mm_for_FusionPCB.zip)
- [JLCPCB](gerber_to_order/TUNING_160.0x100.0mm_for_JLCPCB.zip)
- [PCBWay](gerber_to_order/TUNING_160.0x100.0mm_for_PCBWay.zip)

## Images

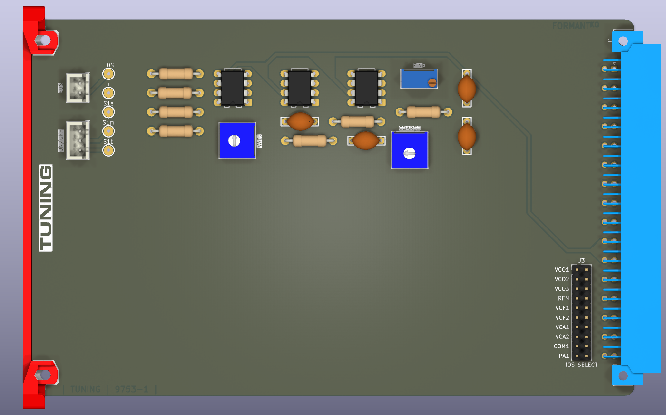
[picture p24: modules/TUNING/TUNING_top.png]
Rendered PCB Top


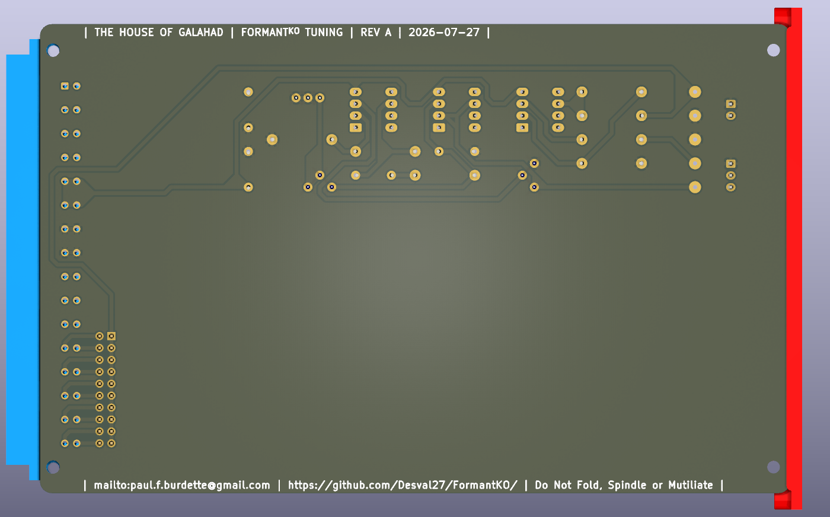
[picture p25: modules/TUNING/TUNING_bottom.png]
Rendered PCB Bottom


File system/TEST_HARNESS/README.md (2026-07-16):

# MODULE TEST BOARD

The **Test Board** is a bench-top development, calibration, and diagnostic tool for Formant modules. It provides a single backplane bus connector with convenient access to all bus signals, allowing individual modules to be powered, calibrated, and tested without being installed in a complete synthesizer system.

The board accepts power from a laboratory bench supply via banana jacks and includes LED indicators for the power rails and GATE bus states. All bus signals are brought out through jumper headers for easy monitoring, isolation, or external connection. Built-in pushbuttons allow manual injection of GATE signals, while selectable potentiometers and switches provide adjustable KOV/CV test voltages for functional testing and calibration. This makes it possible to verify module operation, perform adjustments, and troubleshoot faults entirely on the workbench before installation in a Formant cabinet.

## STATUS

⚠️ Complete⚠️

Partially Tested.

## Documents

- [Schematic](plots/TEST_HARNESS__Schematic.pdf)
- [Assembly](plots/TEST_HARNESS__Assembly.pdf)
- [Interactive Bill of Materials](bom/ibom.html)

## Gerber to Order

- [Default](gerber_to_order/TEST_HARNESS_127.0x104.14mm_for_Default.zip)
- [Elecrow](gerber_to_order/TEST_HARNESS_127.0x104.14mm_for_Elecrow.zip)
- [FusionPCB](gerber_to_order/TEST_HARNESS_127.0x104.14mm_for_FusionPCB.zip)
- [JLCPCB](gerber_to_order/TEST_HARNESS_127.0x104.14mm_for_JLCPCB.zip)
- [PCBWay](gerber_to_order/TEST_HARNESS_127.0x104.14mm_for_PCBWay.zip)

## Images

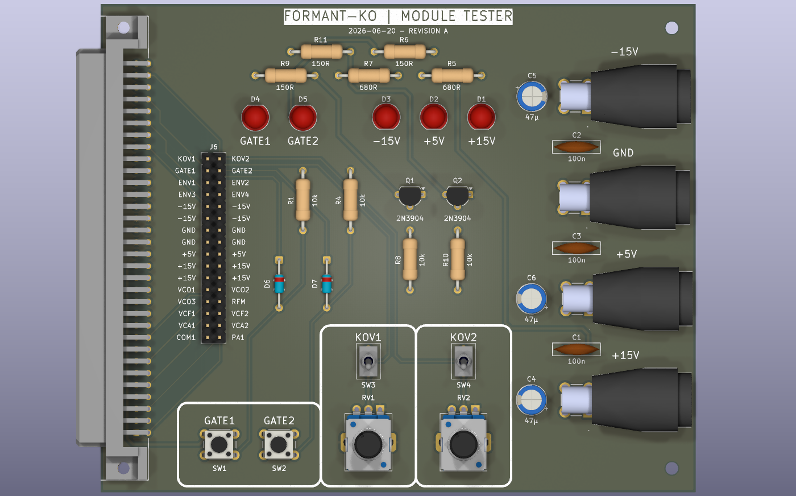
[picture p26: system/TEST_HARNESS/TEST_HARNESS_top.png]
Rendered PCB Top


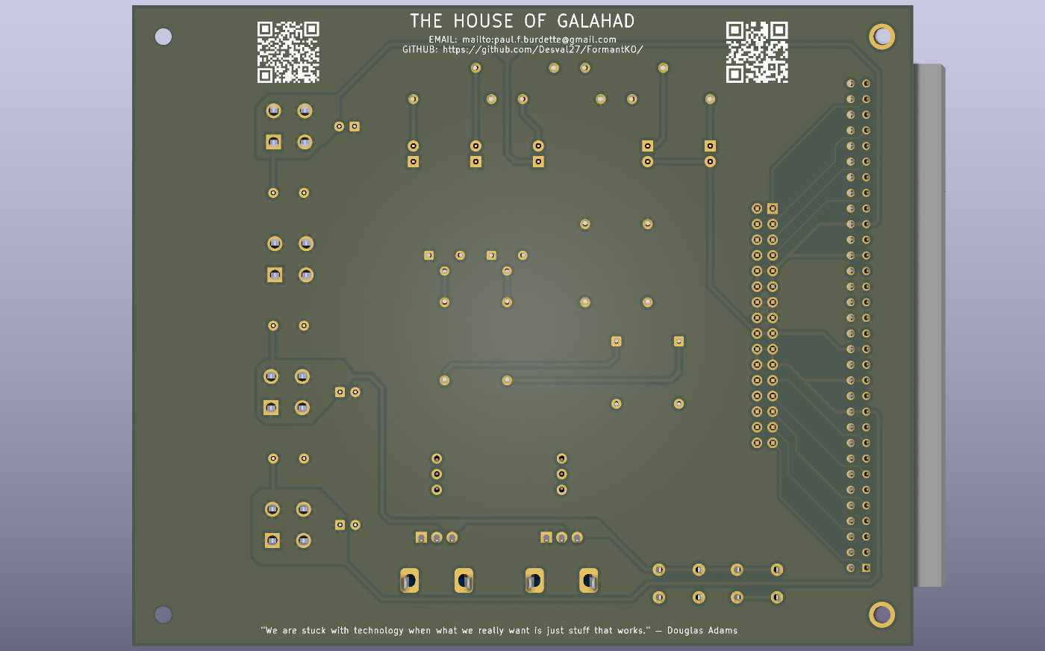
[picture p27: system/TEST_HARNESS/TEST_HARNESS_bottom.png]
Rendered PCB Bottom


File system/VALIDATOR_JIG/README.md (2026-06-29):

# uA726C TESTER

## STATUS

⚠️ Untested ⚠️

But possibly ready to get first samples...

## Documents

- [Schematic](schematic.pdf)
- [Assembly](plots/VALIDATOR_JIG__Assembly.pdf)
- [Interactive Bill of Materials](bom/ibom.html)

## Gerber to Order

⚠️ Untested ⚠️

- [Default](gerber_to_order/VALIDATOR_JIG_55.88x76.2mm_for_Default.zip)
- [Elecrow](gerber_to_order/VALIDATOR_JIG_55.88x76.2mm_for_Elecrow.zip)
- [FusionPCB](gerber_to_order/VALIDATOR_JIG_55.88x76.2mm_for_FusionPCB.zip)
- [JLCPCB](gerber_to_order/VALIDATOR_JIG_55.88x76.2mm_for_JLCPCB.zip)
- [PCBWay](gerber_to_order/VALIDATOR_JIG_55.88x76.2mm_for_PCBWay.zip)

## Images

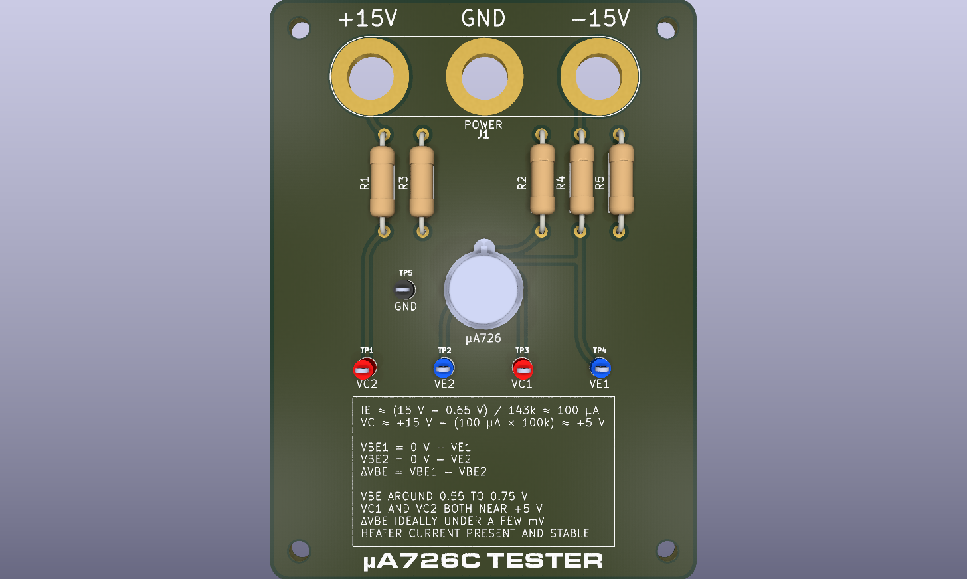
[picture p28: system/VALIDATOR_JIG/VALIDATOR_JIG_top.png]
Rendered PCB Top


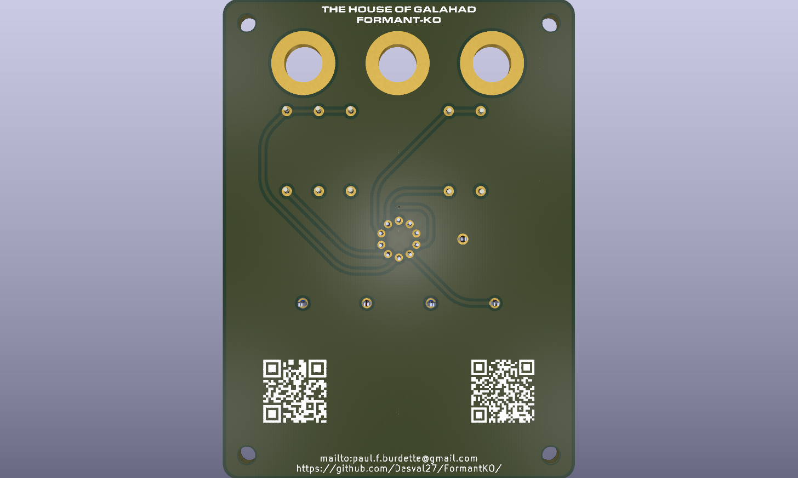
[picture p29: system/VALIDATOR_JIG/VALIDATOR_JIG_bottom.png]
Rendered PCB Bottom


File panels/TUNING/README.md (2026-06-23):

# TUNING

## Status

⚠️ Untested⚠️

## Documents

- [Assembly](plots/TUNING__Assembly.pdf)

## Gerber To Order

⚠️ Untested⚠️

- [Default](gerber_to_order/TUNING_70.78x128.4mm_for_Default.zip)
- [Elecrow](gerber_to_order/TUNING_70.78x128.4mm_for_Elecrow.zip)
- [FusionPCB](gerber_to_order/TUNING_70.78x128.4mm_for_FusionPCB.zip)
- [JLCPCB](gerber_to_order/TUNING_70.78x128.4mm_for_JLCPCB.zip)
- [PCBWay](gerber_to_order/TUNING_70.78x128.4mm_for_PCBWay.zip)

## Images

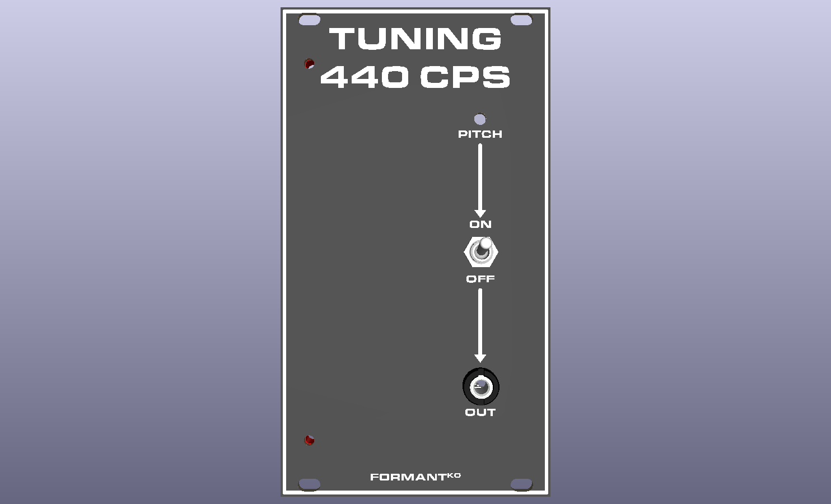
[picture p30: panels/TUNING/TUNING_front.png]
Rendered Front Panel

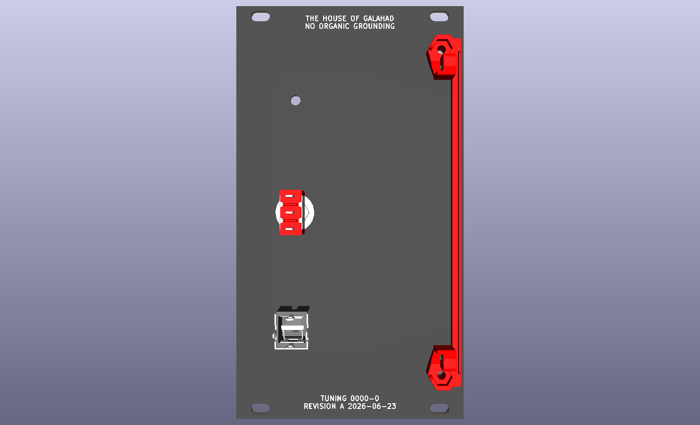
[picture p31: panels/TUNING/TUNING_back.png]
Rendered Back Panel


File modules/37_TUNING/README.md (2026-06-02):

# TUNING

## Status

60% Complete

- [x] Schematic
- [x] Schematic Additions
- [x] Schematic Review
- [x] PCB Placement
- [x] PCB Routing
- [x] PCB Review
- [ ] Sample
- [ ] Build
- [ ] Calibrated
- [ ] Tested

## Documents

- [Translated Document](TUNING.pdf)
- [Assembly](plots/TUNING__Assembly.pdf)
- [Interactive Bill of Materials](bom/ibom.html)

## Gerber to Order

!Untested!

- [Default](gerber_to_order/TUNING_160.0x100.0mm_for_Default.zip)
- [Elecrow](gerber_to_order/TUNING_160.0x100.0mm_for_Elecrow.zip)
- [FusionPCB](gerber_to_order/TUNING_160.0x100.0mm_for_FusionPCB.zip)
- [JLCPCB](gerber_to_order/TUNING_160.0x100.0mm_for_JLCPCB.zip)
- [PCBWay](gerber_to_order/TUNING_160.0x100.0mm_for_PCBWay.zip)

## Images

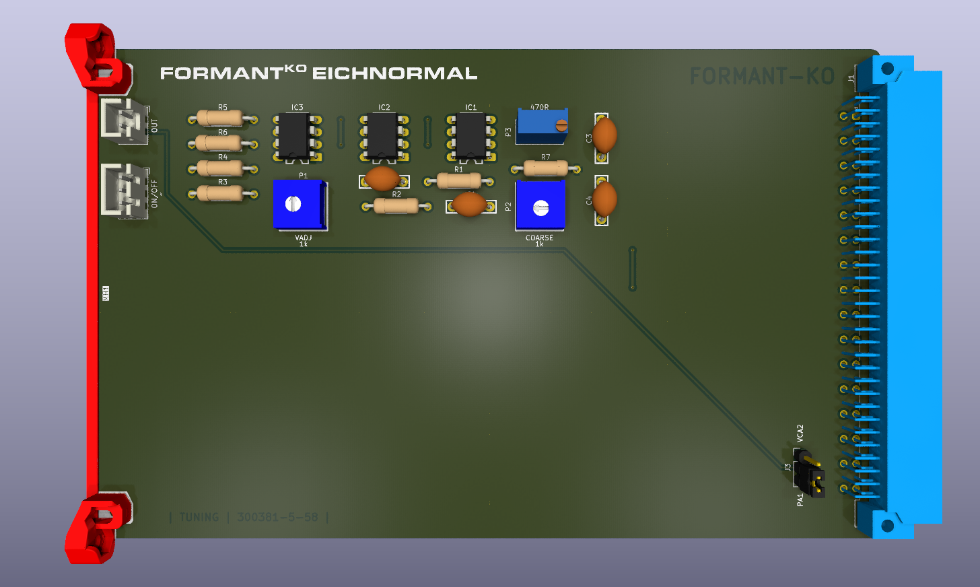
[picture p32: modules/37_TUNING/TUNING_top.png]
Rendered PCB Top

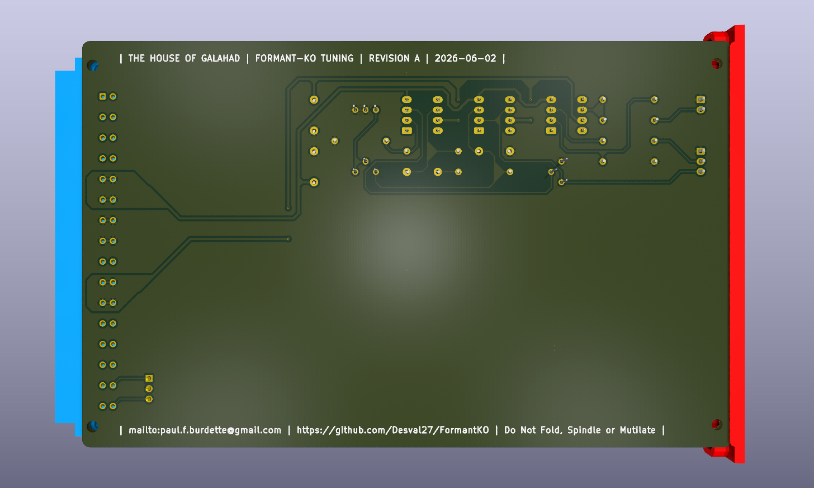
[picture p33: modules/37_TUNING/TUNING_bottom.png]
Rendered PCB Bottom


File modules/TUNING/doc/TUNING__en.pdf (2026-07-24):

# Reference Standard (440 Hz tuning)

A calibration standard is an absolute "must" for the FORMANT—especially since the previous lack of such a circuit was also criticized in a review of the FORMANT published in a well-known German music trade magazine.

In a simple manner, this "electronic tuning fork" generates the standard concert pitch "A" (440.0 Hz). Thanks to the FORMANT's diverse control options, it serves as an (almost) indispensable Due to the manifold control options, the tuning voltage of the VCOs—for instance—changes with every new program combination. The calibration standard, set to 440 Hz, ensures rapid adjustment of the keyboard.

Unless one is dealing with studio-grade equipment, the effort required for quartz standards is too costly. For small to medium-sized music synthesizers—such as those used by amateurs—a stable (conventional) sine-wave oscillator is entirely sufficient.

# The Circuit

The frequency of the oscillator, whose complete circuit diagram is shown in Figure 1, is determined by a simple Wien bridge. C1, C2, B2, P2, and P2 are integrated as frequency-determining components in the positive feedback path of op-amps IC1 and IC2. P1 is connected in the negative feedback path, which provides stabilization. Op-amp 1C2 provides an adjustment of the signal level to FORMANT standards and for low-impedance decoupling. With S1, the sine wave oscillator can be "switched off."

# **Construction**

Construction based on the layout and component placement plan shown in Figure 2 should present no difficulties whatsoever. Since the circuit—which is not particularly large—fits comfortably onto a standard Eurocard, the remaining free space can be utilized to accommodate a +9 V power supply; this can be used, for example, to enable various effects units for musicians to operate independently of batteries. The schematic and component placement plan for this power supply can be found in Appendix D. It is advisable to route the fine-tuning potentiometer P3 to the front panel so that subsequent adjustments can be made without having to remove the rear cover or extract the module. A corresponding mounting hole is provided on the front panel (Figure 3). 70-turn helical potentiometers are commercially available and are, of course, well-suited for this purpose. Their only drawback is likely their cost. The sketch in Figure 4 illustrates how this issue can be resolved more simply—that is, more economically. A Cermet helical trimmer is mounted on a perforated circuit board, which is in turn secured to the rear side of the front panel using an aluminum angle bracket. The trimmer's connections are routed via solder pins. The only critical component is R7. Should a 220-ohm PTC resistor not be available, a miniature incandescent lamp (6 V, 30 mA) may be used instead.

# Calibration

P1 must be adjusted so that the amplitude of the output voltage lies within a range of 2.5 V. When measuring with a multimeter (preferably one with high input impedance), it should be noted that the measured RMS value must be multiplied by the factor 2√2 (≈ 2.828).

P2 is used for coarse adjustment, and P3 for fine adjustment of the oscillator frequency. Due to operating temperature considerations, calibration should not be started until the unit has been running for approximately 10 minutes. Precise adjustment of P2 and P3 can be easily achieved by tuning the oscillator against a reference signal to "zero beat." An AF function generator, an electronic organ, or a tuning fork may be used as a reference signal.

More accurate results can be obtained by calibrating with a digital frequency counter, although this process is correspondingly time-consuming given a gate time of 5 to 10 seconds. With a view to its use in conjunction with other (mechanical) musical instruments, a calibration frequency of 440 Hz was selected. This corresponds to the "Kammerton" (concert pitch) A4. However, the sine oscillator oscillates reliably within a range of 250 Hz to 750 Hz, allowing it to be tuned to a frequency other than 440 Hz if desired.

# Wiring

The wiring connections between the circuit board and the front panel require no further explanation.

However, a few remarks regarding the "placement" of the calibration standard within the internal wiring of the FORMANT music synthesizer are in order:

The internal output (IOS) of the calibration standard module is best wired to the IS input—an input that is also connected to one or more outputs of the VCAs. Via the EOS output on the front panel, the tuning tone is also available—for instance, for an additional "VCO Bank" housed in a separate enclosure.

# Application in the FORMANT

The tuning procedure for the FORMANT VCOs is described in detail in the second section of the first FORMANT manual.

To tune the system, set the VCFs and VCAs to full transparency (open) with maximum gain. Next, while holding down the "A" key on the keyboard, adjust the individual FINE and COARSE controls to achieve a zero beat. With this done, the FORMANT is ready to be played alongside other musical instruments. When tuning to chords, simply count down—starting from the "A" reference—the number of semitones by which the target VCO is intended to sound higher, and then adjust that VCO to a zero beat. For example, to tune to a major third interval, set VCO1 to

"A" and VCO2 to "F"—that is, four semitones lower—and adjust both to a zero beat. VCO2 will then sound exactly four semitones higher than VCO1. This eliminates the need to "memorize" the individual tuning settings for each VCO, thereby greatly simplifying the tuning process. Even after the initial adjustment, the resulting chord is usually so pure that further fine-tuning is rarely necessary.

# Figures

- Figure 1. Calibration Standard for the FORMANT. It consists of a sine-wave oscillator tuned to 440 Hz (concert pitch "A").
- Figure 2. Layout and component placement diagram for the calibration standard. Since this circuit board is also designed in the Eurocard format, sufficient space remains for a +9 V power supply. The circuit diagram, PCB layout, and parts list are provided in Appendix D.
- Figure 3. Proposed front panel layout (80% of original size) for the calibration standard.
- Figure 4. Proposed mounting arrangement for a cermet helical trimmer potentiometer, in cases where a 10-turn helical potentiometer is not a viable option.



## Tuning Bill of Materials

### Resistors (Carbon Film, 5%):

- R1 = 560 Ω
- R2 = 10 kΩ
- R3, R4 = 100 kΩ
- R5 = 56 kΩ
- R6 = 470 Ω
- R7 = PTC 220 Ω (see text)

### Potentiometers:

- P1 = 1 kΩ (Trimmer)
- P2 = 10 kΩ (Trimmer)
- P3 = 470 Ω (see text)

### Capacitors:

- C1, C2 = 47 nF (MKH/MKS)
- C3, C4 = 470 pF (MKH/MKS)

### Semiconductors:

- IC1...IC3 = 741 (Mini-DIP)

### Miscellaneous:

- S1 = Miniature Toggle Switch (SPDT)
- 1 x 3.5mm Jack Socket
- 1 x 31-pin Header Strip or Solder Pins

# References:

- C. Chapman: FORMANT Music Synthesizer, Elektor Verlag
- G. Dellmann: FORMANT SYNTHESIZER, Fachblatt – Music Magazine (Section: Music – TÜV), No. 53, August 1977
- H. Tünker: Electronic Pianos and Synthesizers, Franzis Verlag, Munich, RPB Series No. 302 (1975, 1st ed.) pp. 109, 110

# A Brief Word

Fundamental information regarding the scope of the FORMANT’s modules has already been covered in the first FORMANT book, as well as in the introduction to this volume. However, since this topic presents a rather significant challenge for many synthesizer users, a final attempt to provide an answer is certainly warranted.

Very few synthesizer enthusiasts know exactly—right from the start—which modules they will need, or in what quantities. As a rule, those encountering a complex electronic musical instrument for the first time typically lack concrete ideas regarding the appropriate scope of their system. Fundamentally, the overall scope of a synthesizer system is determined by its intended application. An audio/film hobbyist who merely wishes to provide an acoustic backdrop for their slide and film shows requires a different module configuration than an (electronic) jazz musician. When building a system oneself, the amount of time one is able to dedicate to the hobby also plays a significant role. Last but not least, an individual's financial situation is also a crucial factor when configuring a system. However, much can be done to address this through meticulous planning (e.g., by creating a comprehensive parts list for the entire system). After all, when purchasing—for instance—100 resistors, the unit cost per resistor is lower than when purchasing only 10.

One important point should not be overlooked during the planning phase: the potential for future expansion of the initial system. The desire to expand the system inevitably arises once all its musical capabilities have been fully explored. Therefore, this factor must be given careful consideration during the mechanical design phase and when selecting a housing. The modular architecture of the FORMANT is ideally suited for—and practically invites—construction in stages. This approach offers a further advantage that may not be immediately obvious: by starting with a manageable scope, one can achieve musically meaningful results much more quickly, while simultaneously growing into the system as it is gradually expanded later on.

So, exactly how many of each module does one actually need? Experience shows that one can never have enough VCOs, VCAs, and ADSRs. The exact number of VCFs required is difficult to determine, as it depends—particularly—on the intended application; this applies equally to several other modules described in this book. However, it certainly does no harm to build at least one of each of these specialized circuits (ring modulator, envelope follower, sample & hold, etc.) in order to discover the musical potential inherent in them. Only once you have gained a clear understanding of this can the specific number of new modules be decided upon. The accompanying table can serve as a guideline during this decision-making process. It is based on empirical data derived from typical synthesizer systems. The "basic configuration" corresponds roughly to the circuits described in Book 1. The setup designated in the table as a "medium system" already falls into the high-end category when compared to commercial equipment. This level of sophistication offers ample scope for both the amateur enthusiast and the adventurous player. The "large system" closely mirrors the configurations found in professional recording studio synthesizers. Finally, when assembling your own system, you might also choose to use the equipment setups of well-known synthesizer players as a point of reference.

In any case, amidst all these considerations, one objective must never be lost sight of: a synthesizer exists for the sole purpose of making music. It serves as an effective tool for providing beginners with an entry point into the world of musical acoustics—and, by extension, into the realm of electronic music. The true art lies in translating one's own imagination into concrete musical forms. Keeping records of interesting sounds helps in building a personal "idea bank." This can be done either in writing—using the methods outlined in Appendix A—or by using a cassette recorder as an "active memory."

One final thought: despite all the modernization and expansion of individual modules, it is ultimately the player themselves who shapes physical vibrations into music. New modules, in and of themselves, do not automatically foster greater creativity. Experience has already proven this to be true: the more module cabinets and keyboards that cluttered the stage, the more the imagination tended to wither away. Being a gear fetishist is no guarantee of a "creative sound." On the contrary: with just two or three FORMANT modules (e.g., a VCF and a Noise module), a microphone, and an acoustic instrument, it is already possible to venture into new acoustic dimensions. Jiří Klásek once aptly described this potential when he said: "Through electronics to more music—and not the other way around."

| Module Title | Basic Fit-out | Intermediate System | Large system
FORMANT -Book 1 + 2 | VCO | 3 | 4…6 | 7…12
| VCF (12dB) | 1 | 2 | 3…4
| VCF (24dB) | 1 | 2 | 4…5
| Dual-VCA | 1 | 2…3 | 5…10
| ADSR | 1…2 | 3…6 | 8…15
| LFOs, VC-LFOs, LF-VCO | 1 | 2 | 3…4
| NOISE or DNG | 1 | 2 | 4
| RFM | 0…1 | 1…2 | 2…4
| COM | 1 | 2 | 2…4
FORMANT -Book 1 + 2 | Controllers (analog or digital Keyboard, Joystick, Touch Plate, Ribbon Controller, etc.) | 1 | 2 | 3…6
FORMANT - | Stroke Control | 0 | 0…1 | 1…2

Extensions
(Book 2)
NPD | 0…1 | 1…2 | 2..4
Ring Modulator | 0…1 | 1…2 | 4
Phase Shifter | 0 | 1…2 | 3…5
Krimisizer | 0…1 | 0…2 | 0…3
(Digital) Reverb | 0 | 0…1 | 1…3
KOV/KB-Gate | 0…1 | 1…2 | 2
Multiple Jacks | 0…1 | 1…2 | 3…6
ADSR-Controller | 0 | 1…2 | 3…8
ENV-F | 0 | 1 | 2
Waveform Processor | 0 | 1 | 2
S & H | 0…1 | 2 | 4
Mixer | 0 | 1…2 | 3…6
440 Cps Tuning | 0 | 1 | 1…2
(DIgital) Sequencer | 0…1 | 1…2 | 2…5

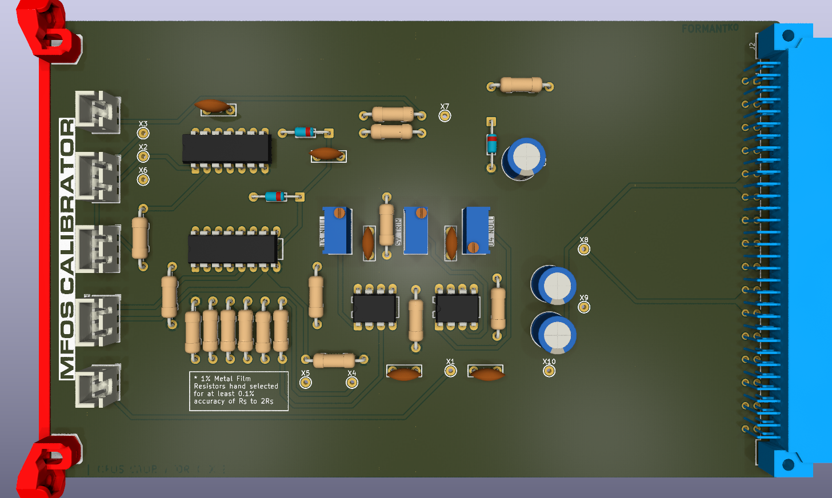
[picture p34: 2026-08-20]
MFOS/modules/CALIBRATOR/doc/pcb_top.png

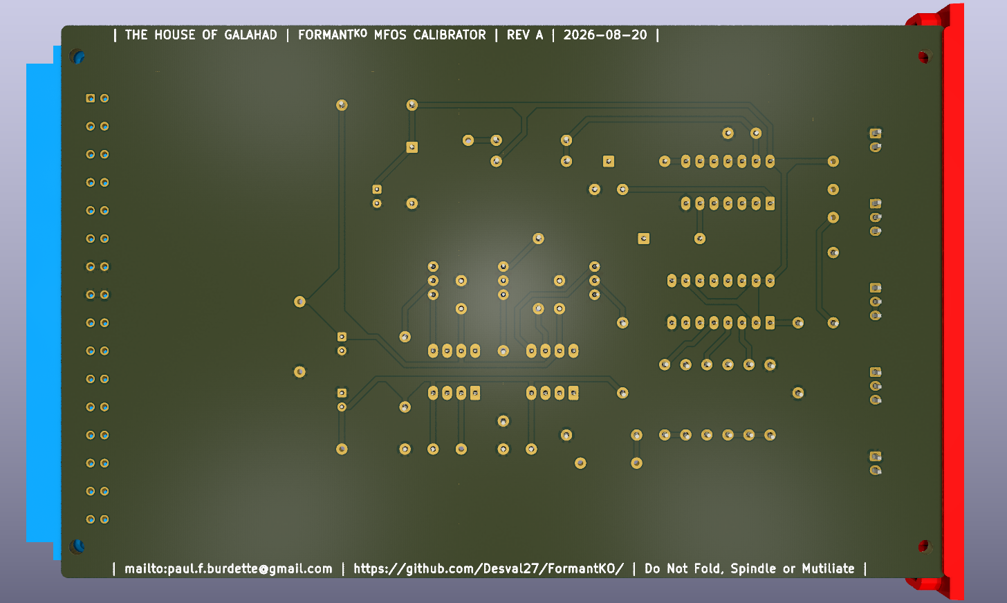
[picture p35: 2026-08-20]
MFOS/modules/CALIBRATOR/doc/pcb_bottom.png

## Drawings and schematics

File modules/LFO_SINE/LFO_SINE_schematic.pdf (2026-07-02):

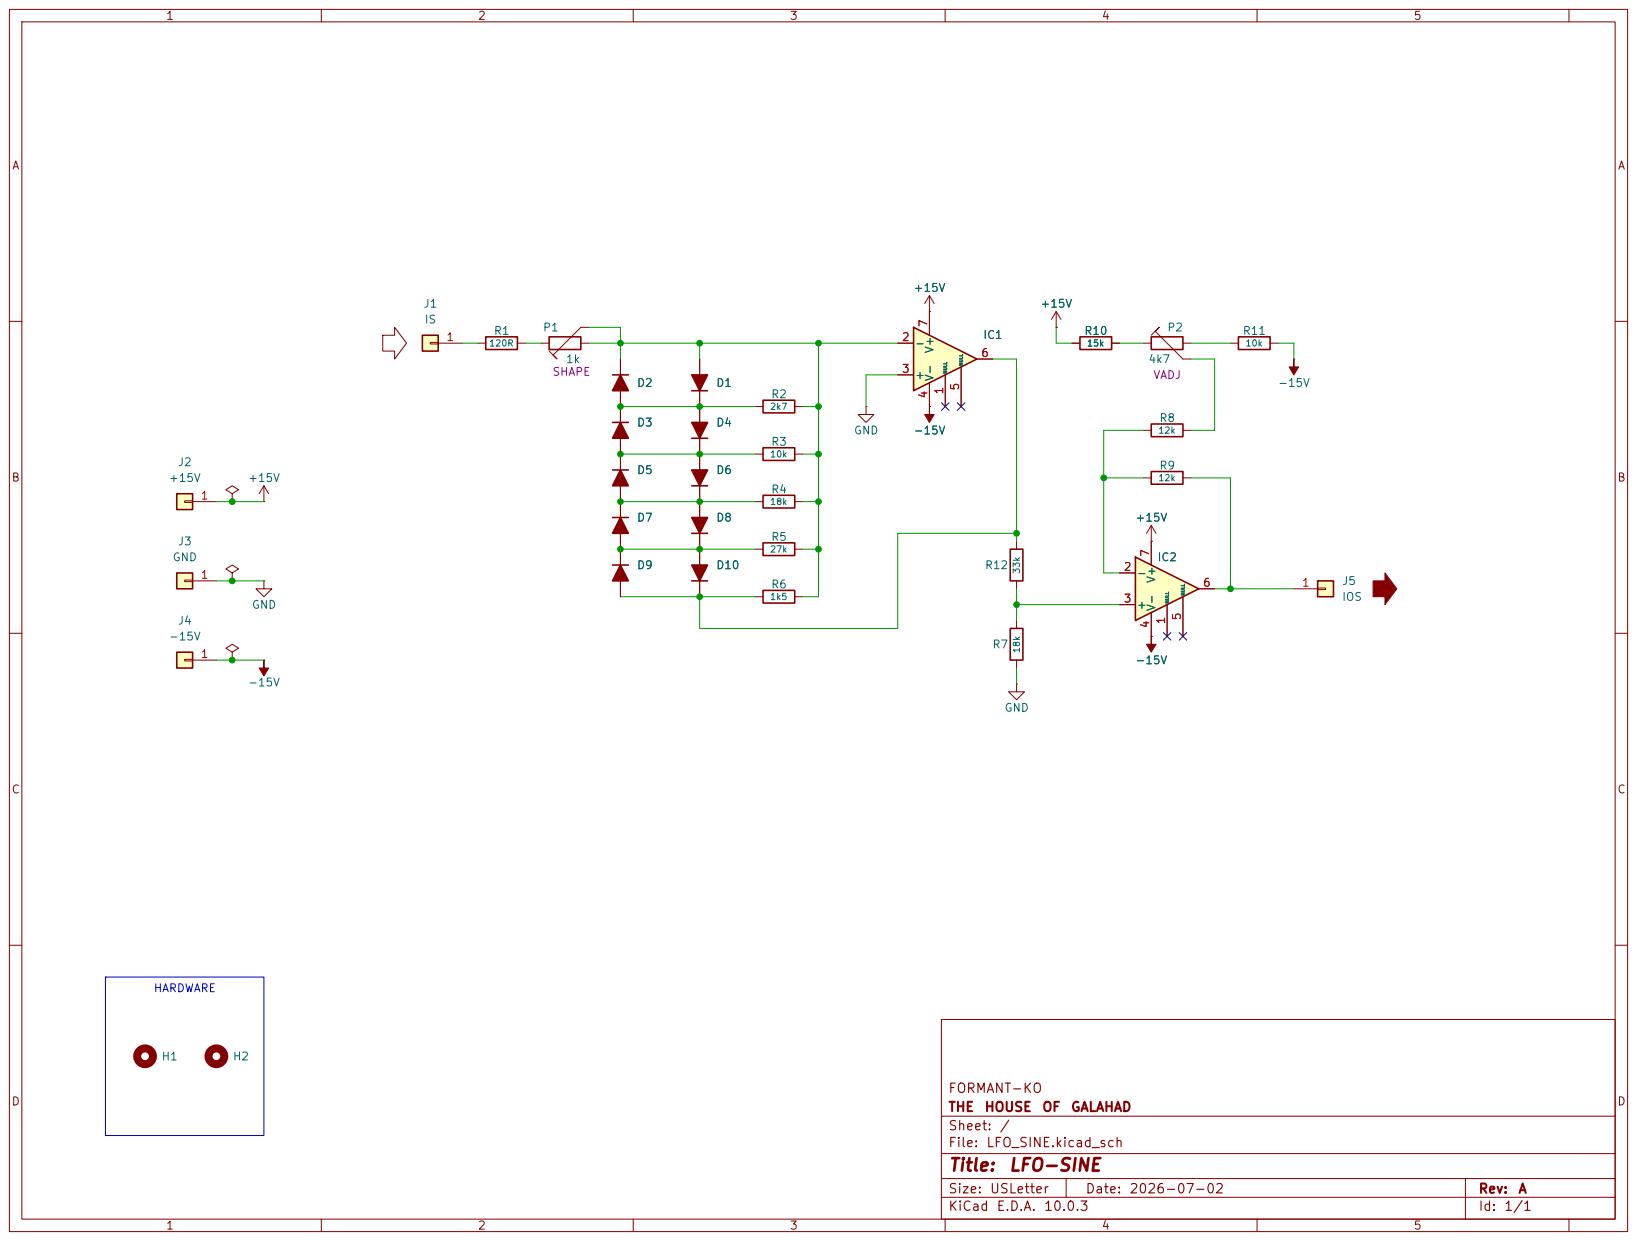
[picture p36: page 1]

THE HOUSE OF GALAHAD
Sheet: /
File: LFO_SINE.kicad_sch
Title: LFO-SINE

Size: USLetter | Rev: A
KiCad E.D.A. 10.0.3 | Id: 1/1

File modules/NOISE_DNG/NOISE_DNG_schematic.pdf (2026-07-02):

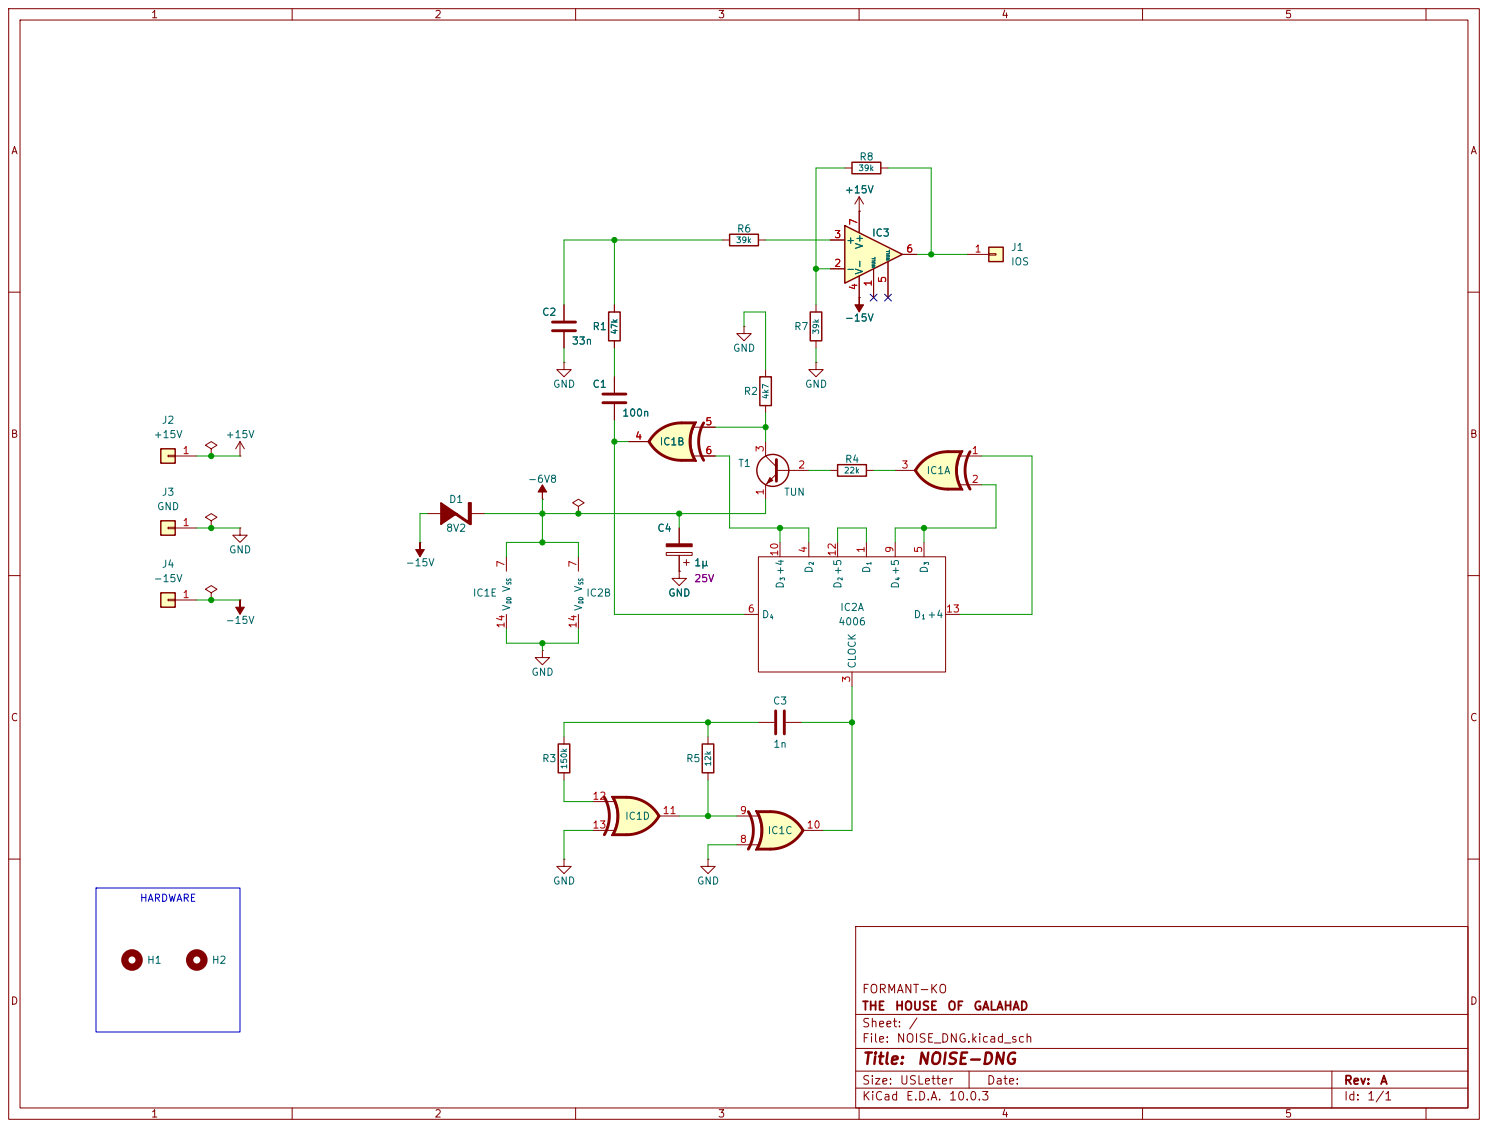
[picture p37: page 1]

FORMANT-KO V SS 7 V DD 14

THE HOUSE OF GALAHAD
Sheet: /
File: NOISE_DNG.kicad_sch
Title: NOISE-DNG

Size: USLetter | Rev: A
KiCad E.D.A. 10.0.3 | Id: 1/1

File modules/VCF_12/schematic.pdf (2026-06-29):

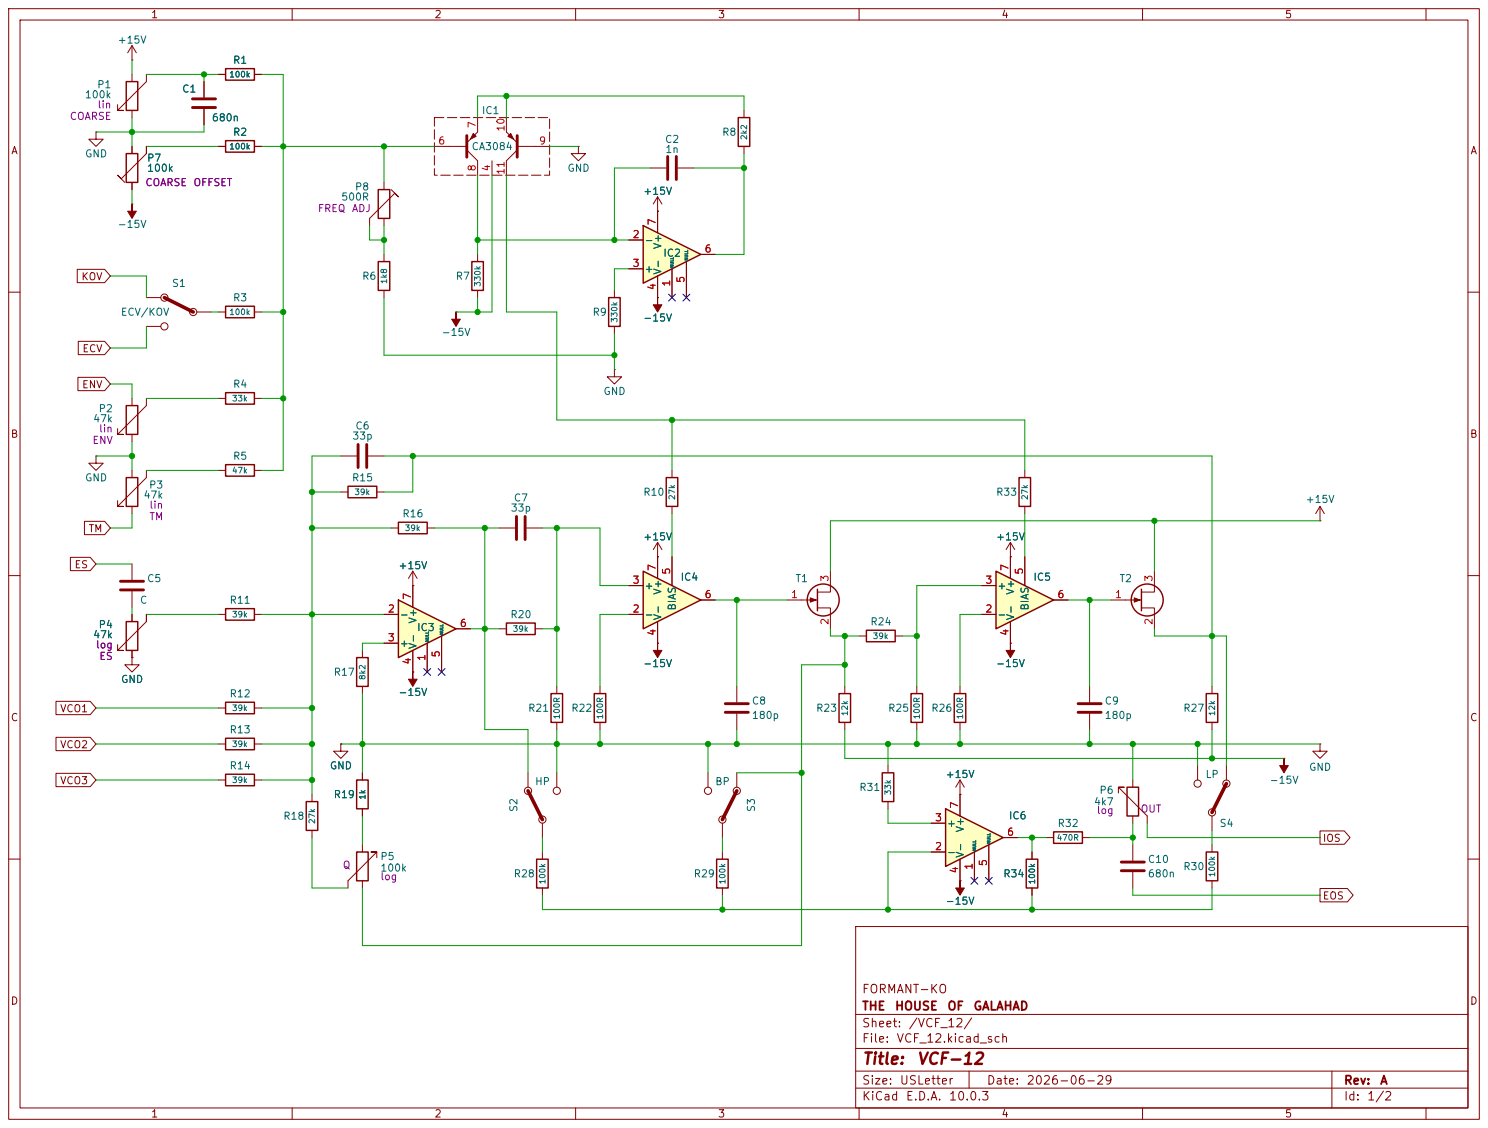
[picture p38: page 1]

FORMANT-KO
THE HOUSE OF GALAHAD
Sheet: /VCF_12/
File: VCF_12.kicad_sch
Title: VCF-12

Size: USLetter | Rev: A
KiCad E.D.A. 10.0.3 | Id: 1/2

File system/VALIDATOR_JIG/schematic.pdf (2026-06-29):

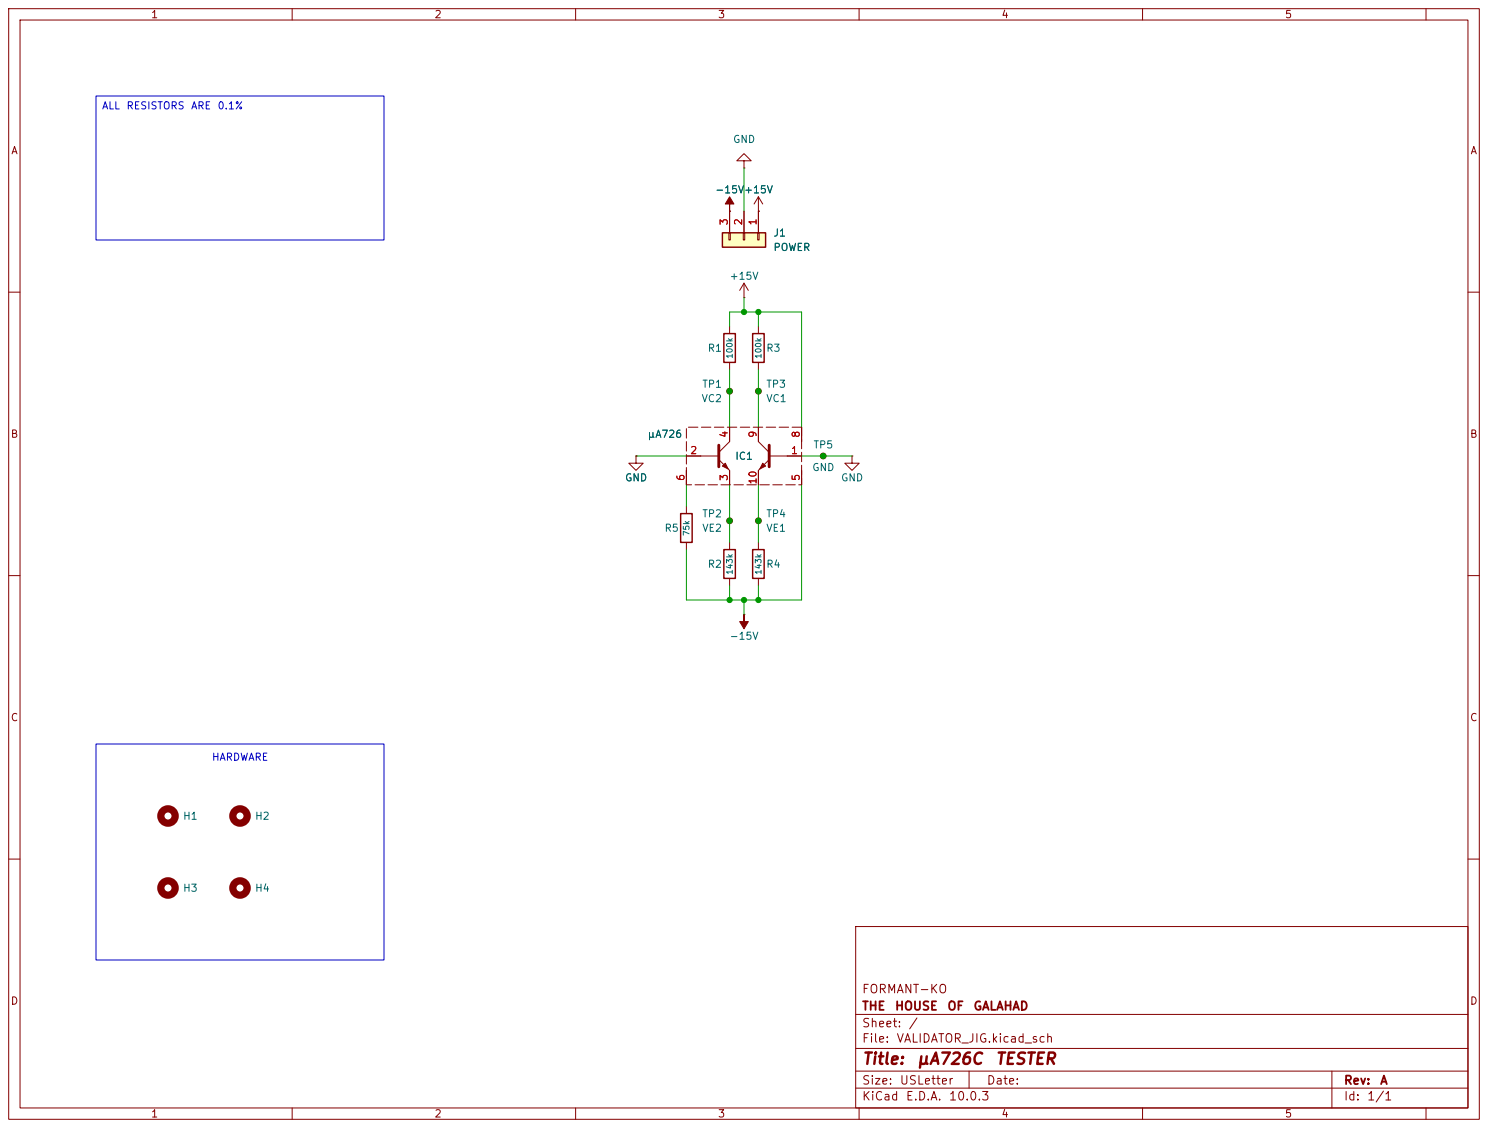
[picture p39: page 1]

FORMANT-KO
THE HOUSE OF GALAHAD
Sheet: /
File: VALIDATOR_JIG.kicad_sch
Title: µA726C TESTER

Size: USLetter | Rev: A
KiCad E.D.A. 10.0.3 | Id: 1/1

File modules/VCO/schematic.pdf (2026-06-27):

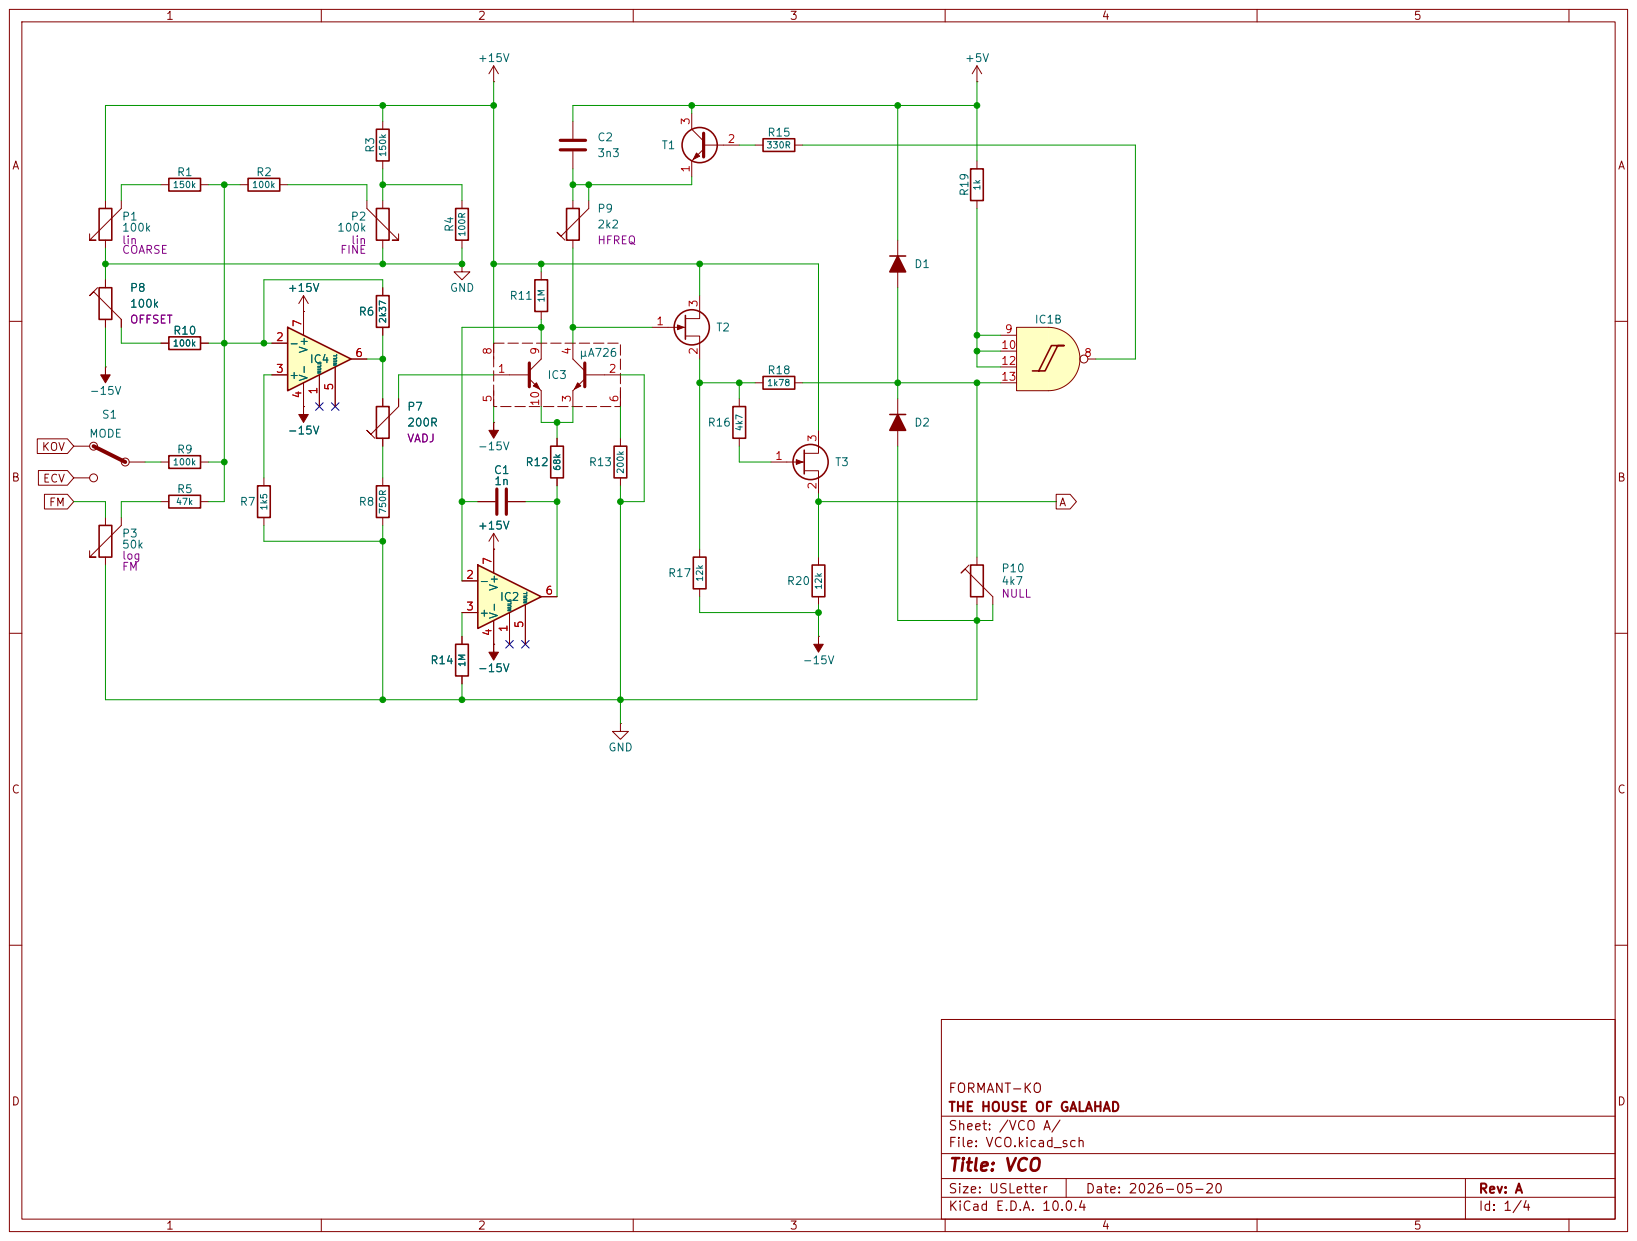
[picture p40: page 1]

FORMANT-KO
THE HOUSE OF GALAHAD
Sheet: /VCO A/
File: VCO.kicad_sch
Title: VCO

Size: USLetter | Rev: A
KiCad E.D.A. 10.0.4 | Id: 1/4

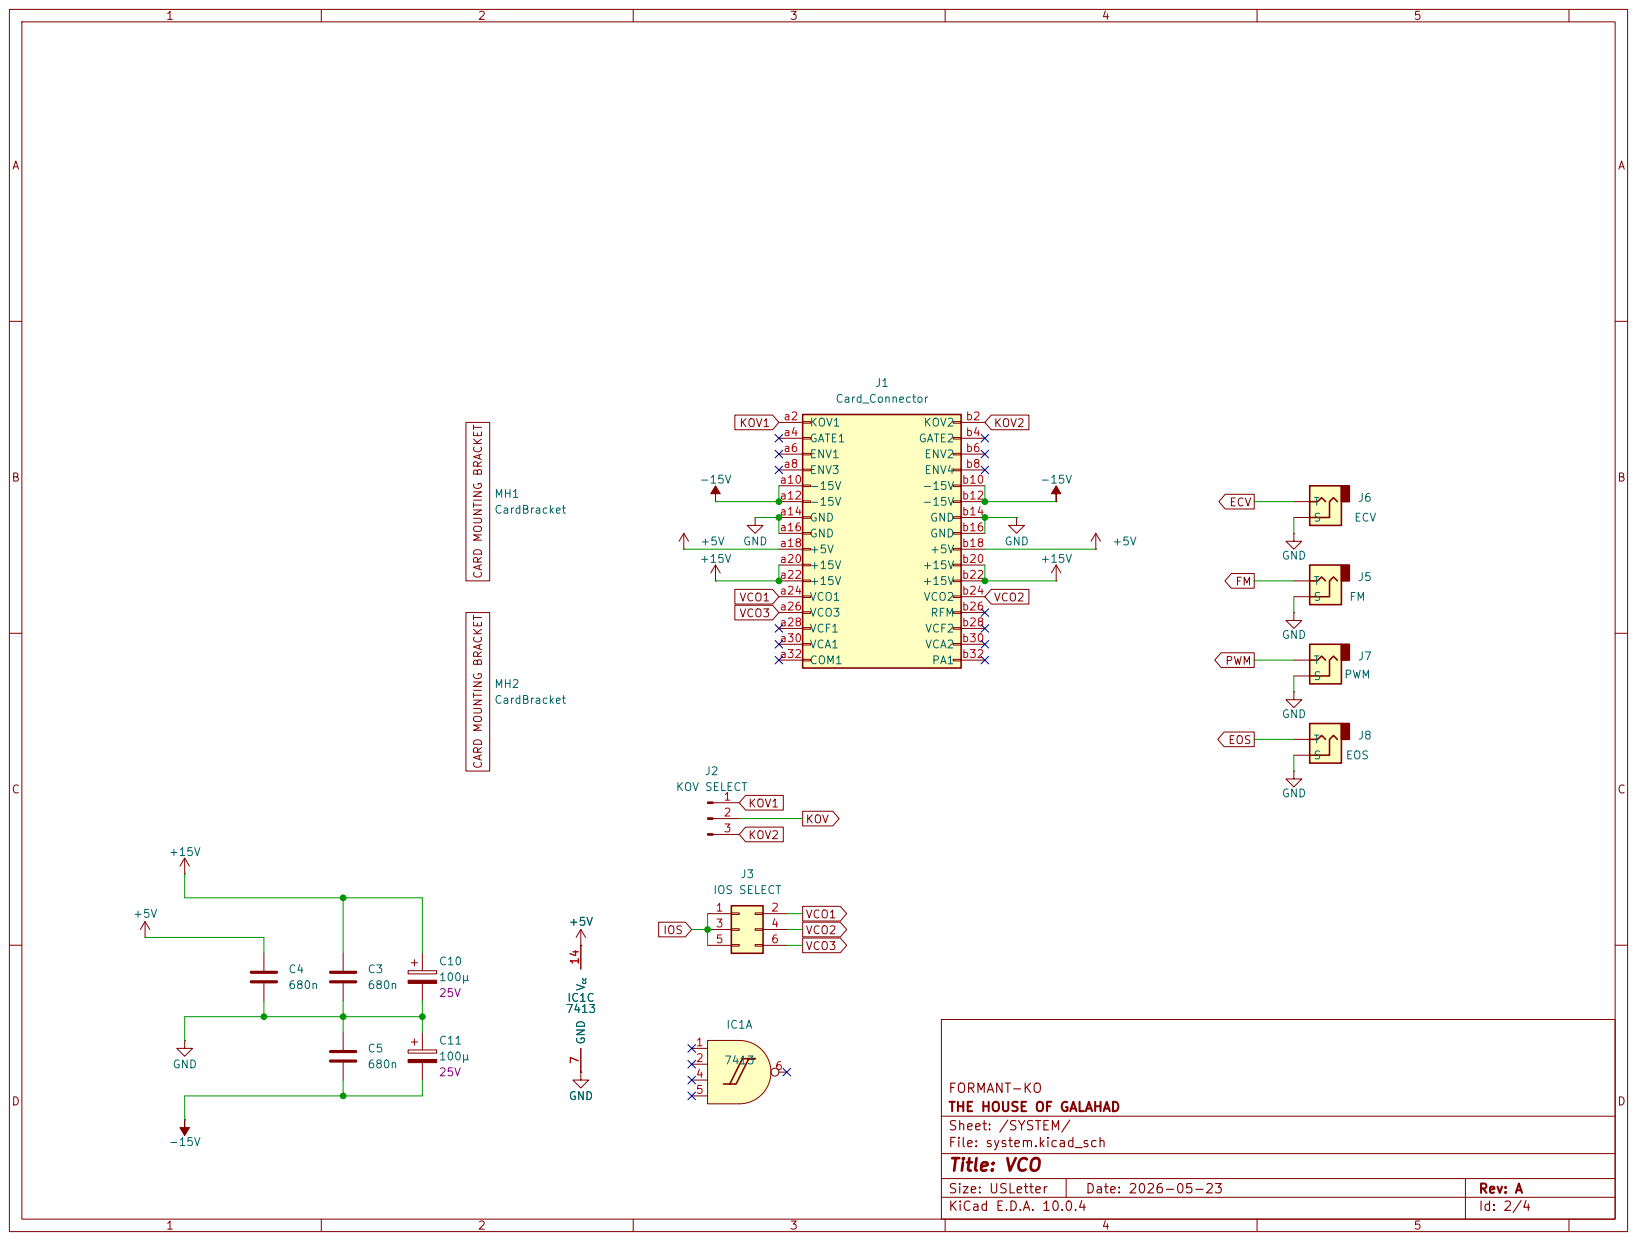
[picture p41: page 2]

FORMANT-KO
THE HOUSE OF GALAHAD
Sheet: /SYSTEM/
File: system.kicad_sch
Title: VCO

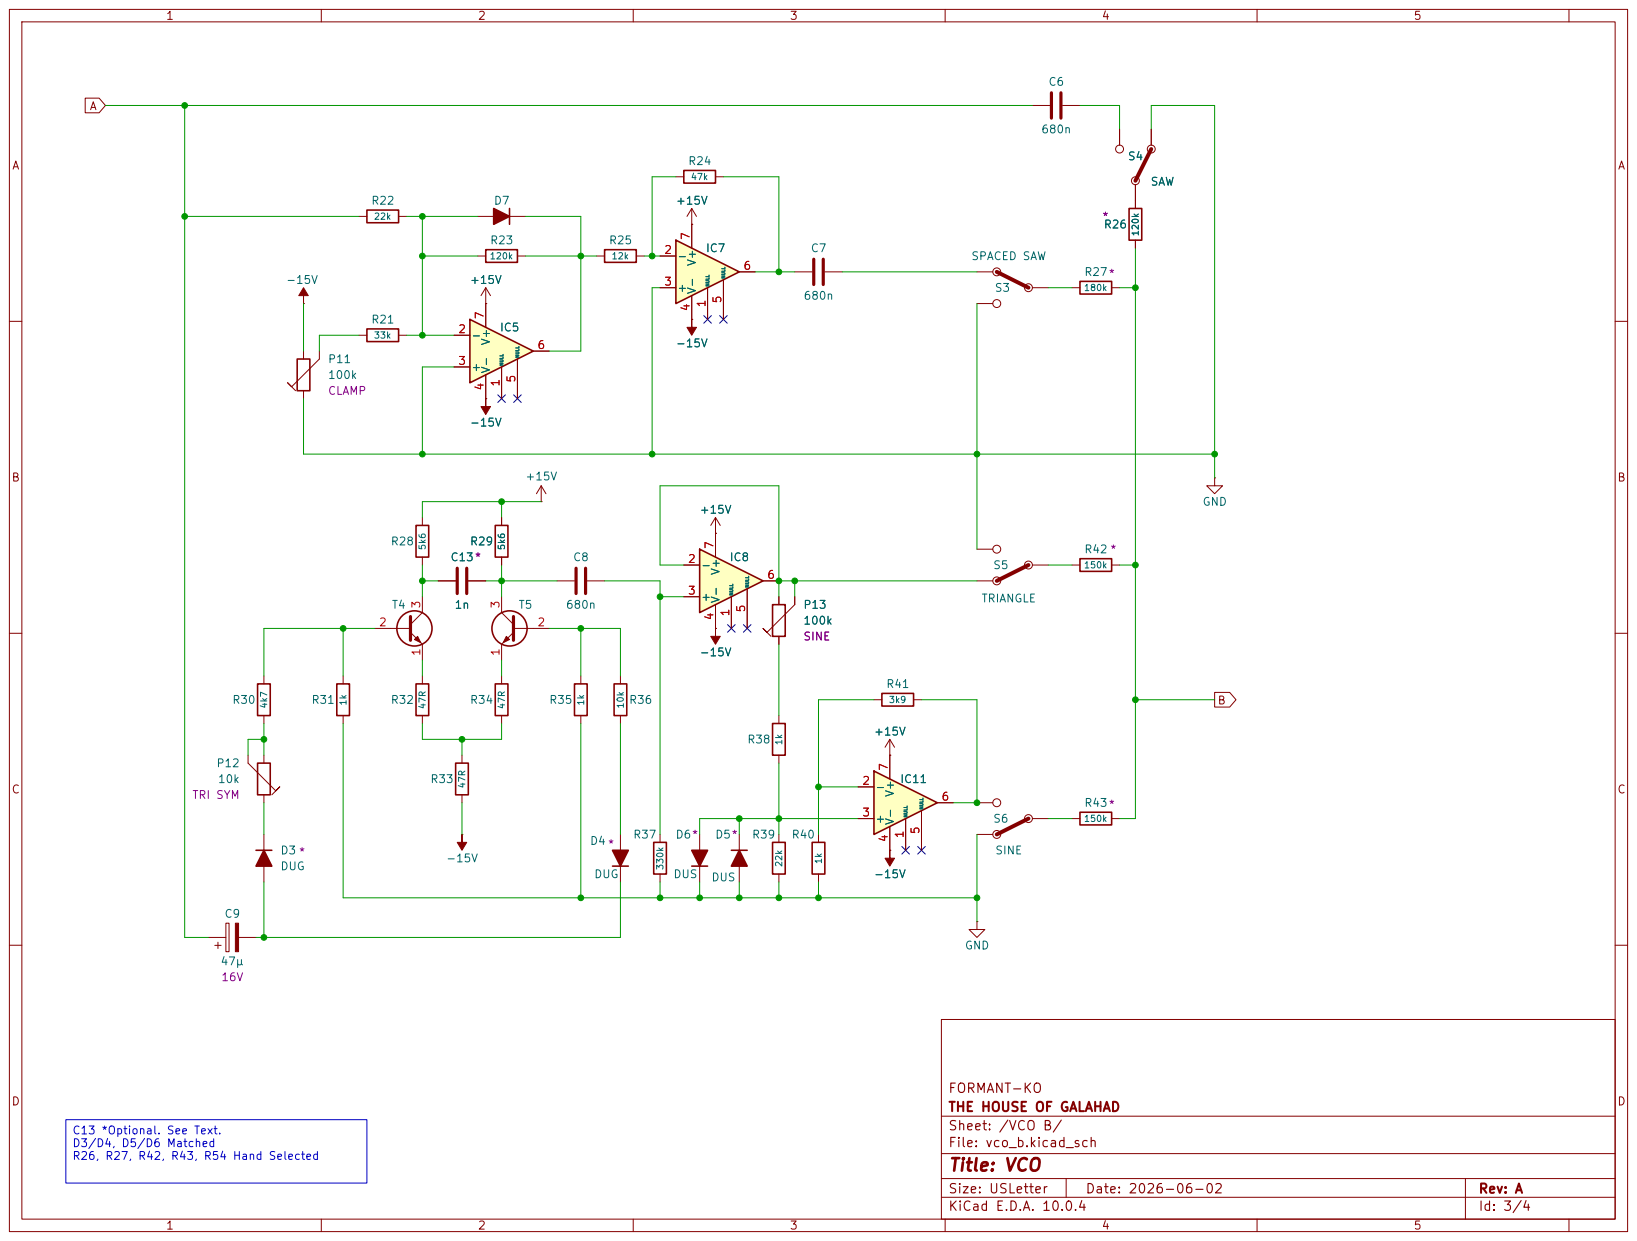
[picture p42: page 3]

FORMANT-KO
THE HOUSE OF GALAHAD
Sheet: /VCO B/
File: vco_b.kicad_sch
Title: VCO

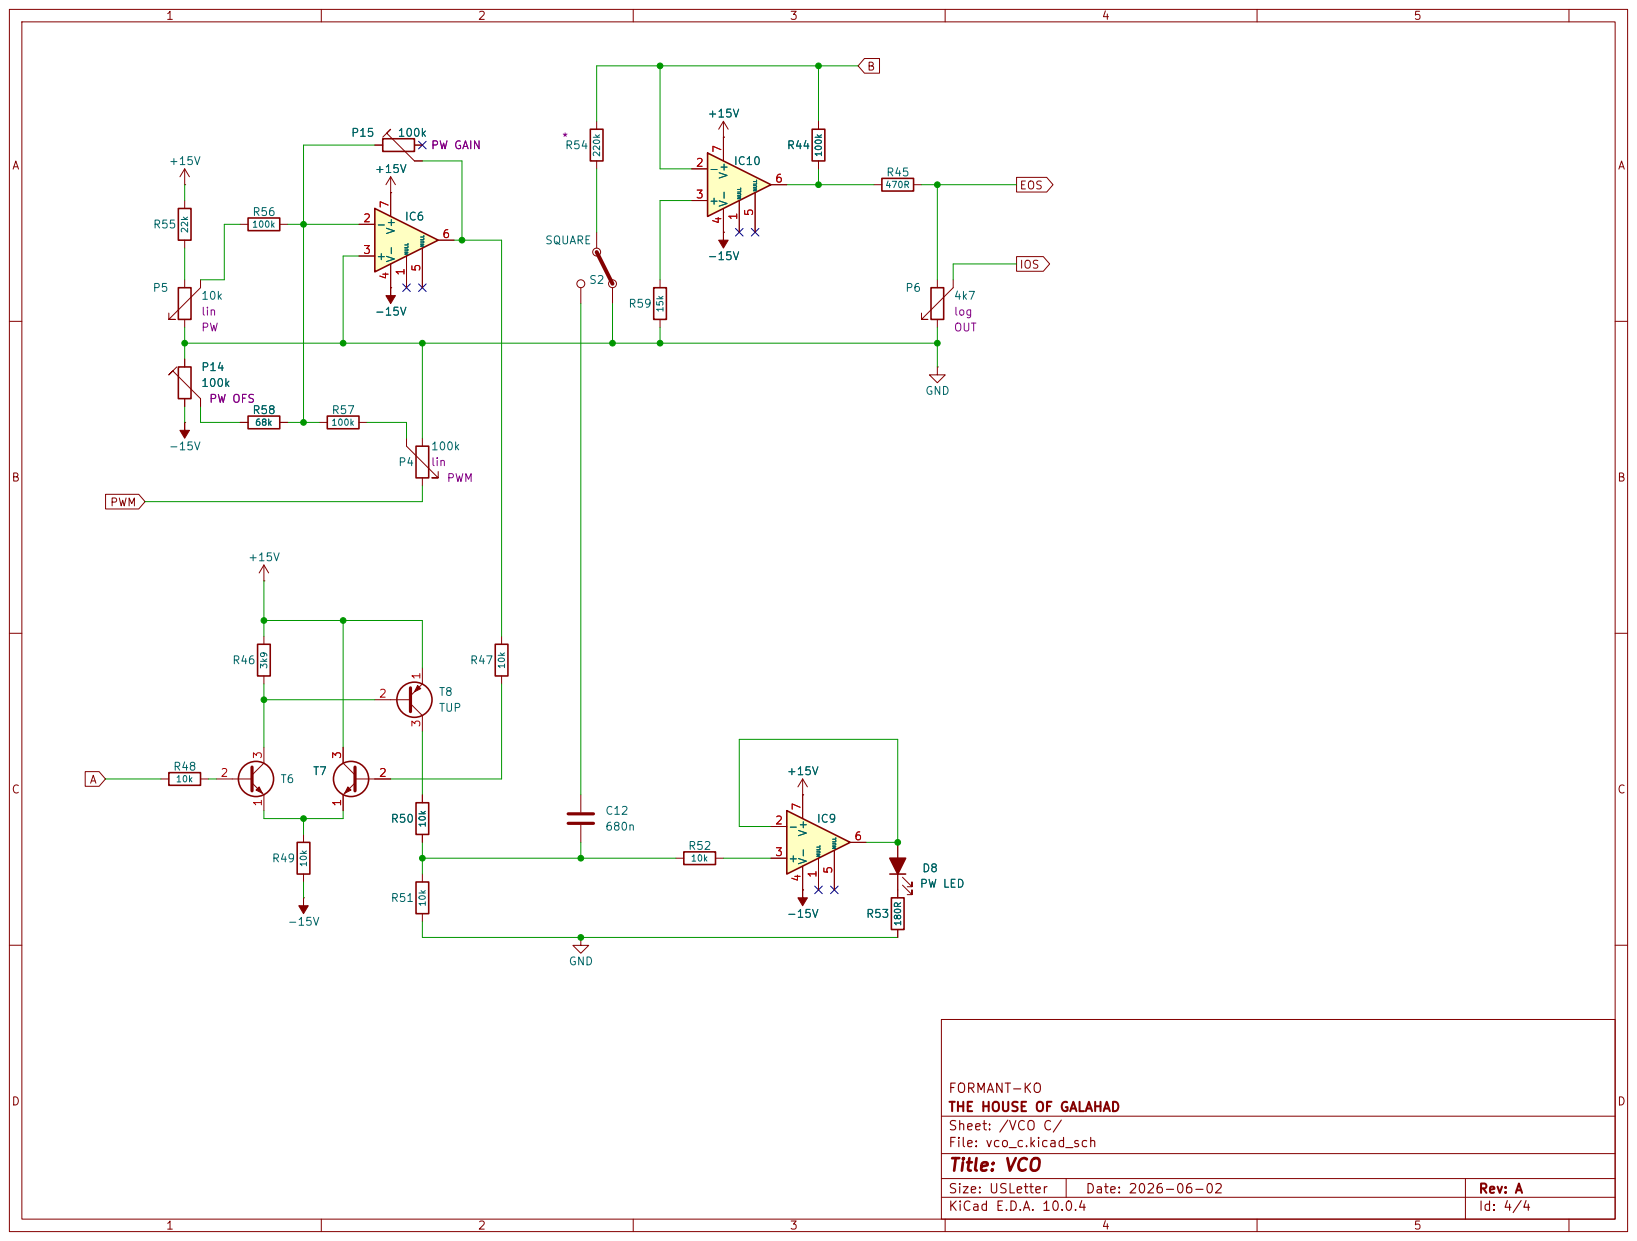
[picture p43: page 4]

FORMANT-KO
THE HOUSE OF GALAHAD
Sheet: /VCO C/
File: vco_c.kicad_sch
Title: VCO

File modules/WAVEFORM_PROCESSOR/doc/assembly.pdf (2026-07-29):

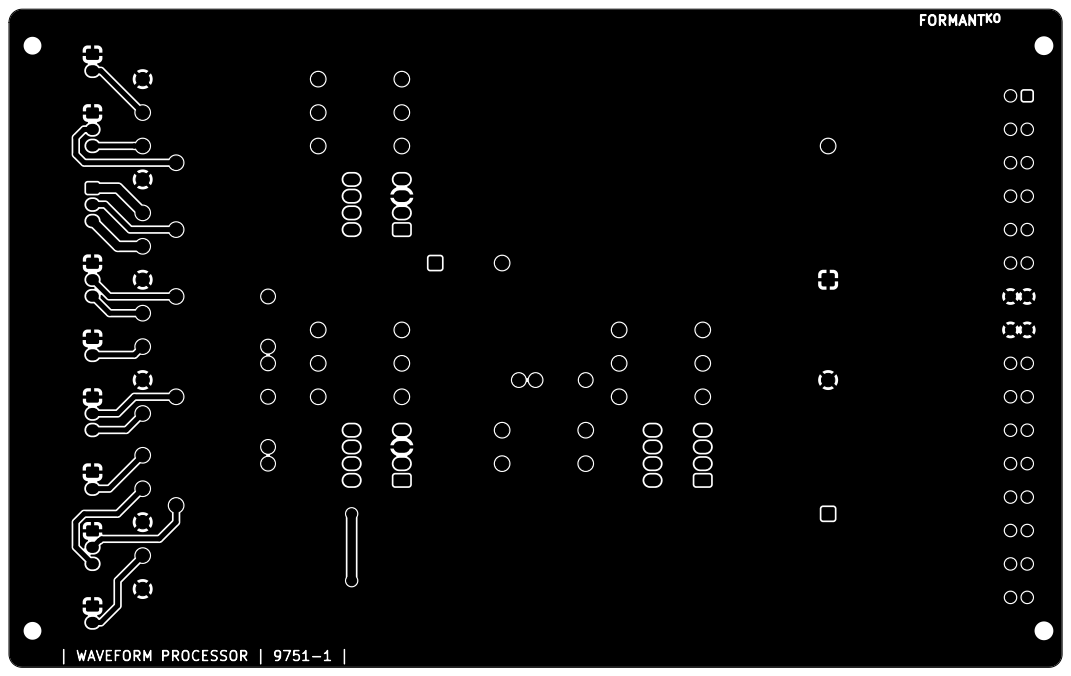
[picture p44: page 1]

KO mailto:paul.f.burdette@gmail.com

Do Not Fold, Spindle or Mutiliate
https://github.com/Desval27/FormantKO/

FORMANT
THE HOUSE OF GALAHAD
Sheet:
File: WAVEFORM_PROCESSOR.kicad_pcb
Title: WAVEFORM PROCESSOR

Size: USLetter | Rev: A
KiCad E.D.A. 10.0.5 | Id: 1/6

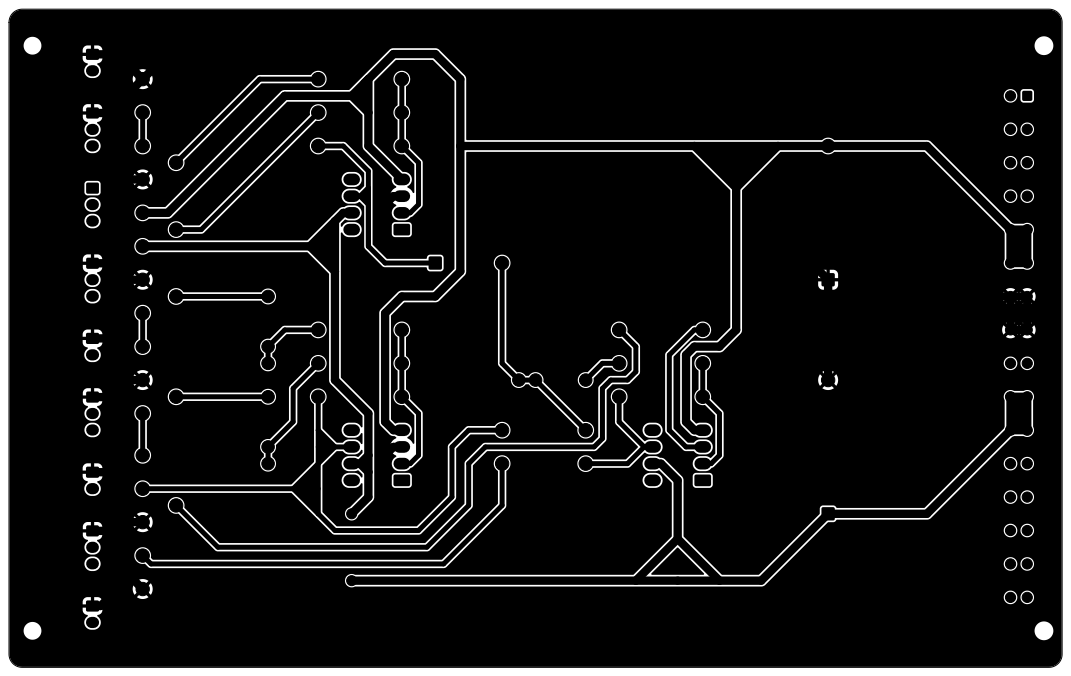
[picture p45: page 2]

KO mailto:paul.f.burdette@gmail.com

Do Not Fold, Spindle or Mutiliate
https://github.com/Desval27/FormantKO/

FORMANT
THE HOUSE OF GALAHAD
Sheet:
File: WAVEFORM_PROCESSOR.kicad_pcb
Title: WAVEFORM PROCESSOR

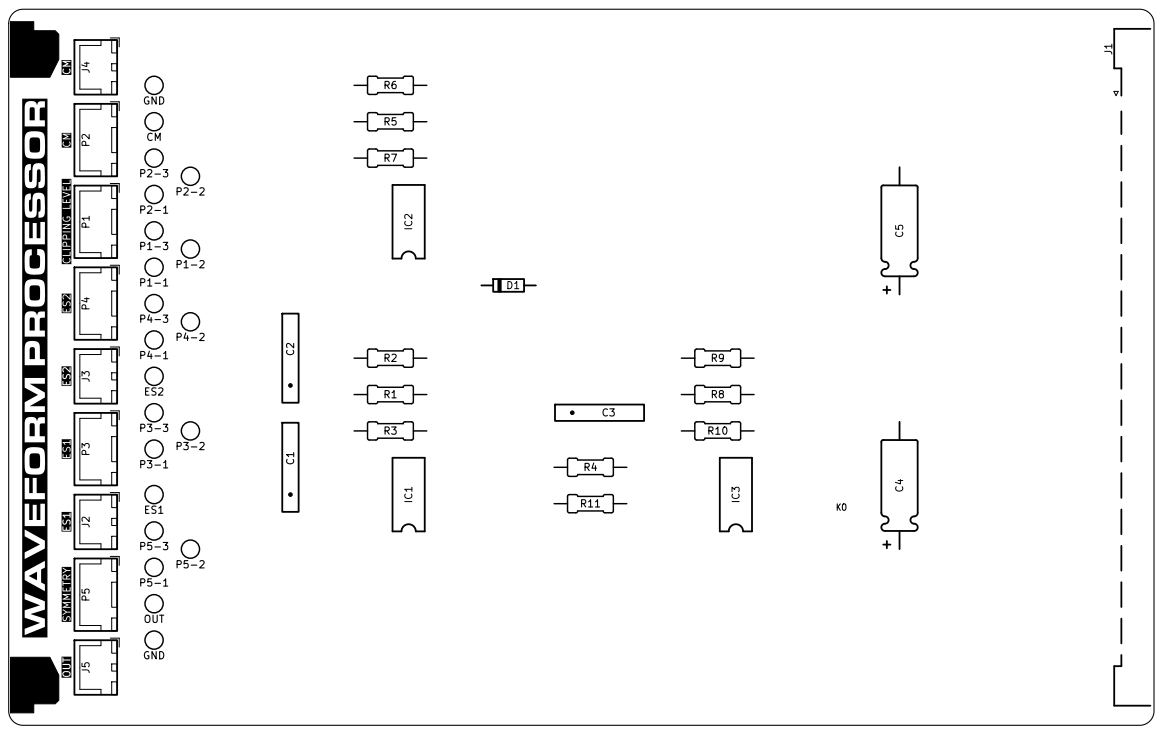
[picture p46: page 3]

KO mailto:paul.f.burdette@gmail.com

https://github.com/Desval27/FormantKO/

FORMANT
THE HOUSE OF GALAHAD
Sheet:
File: WAVEFORM_PROCESSOR.kicad_pcb
Title: WAVEFORM PROCESSOR

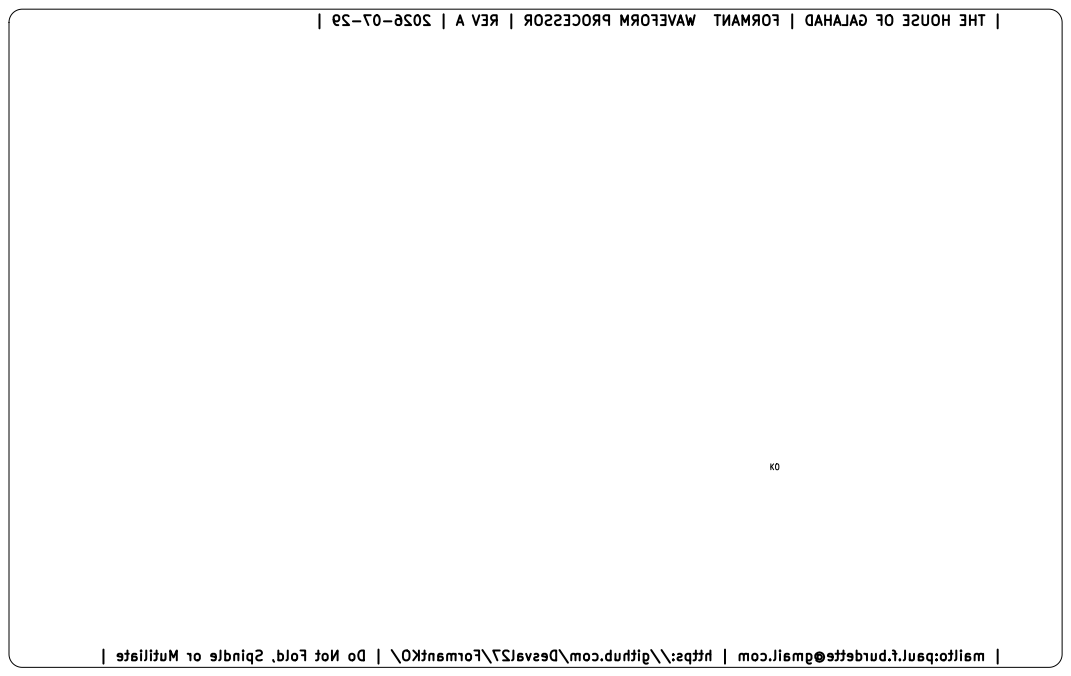
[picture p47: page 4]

KO mailto:paul.f.burdette@gmail.com

Do Not Fold, Spindle or Mutiliate
https://github.com/Desval27/FormantKO/

FORMANT
THE HOUSE OF GALAHAD
Sheet:
File: WAVEFORM_PROCESSOR.kicad_pcb
Title: WAVEFORM PROCESSOR


KO mailto:paul.f.burdette@gmail.com

https://github.com/Desval27/FormantKO/

FORMANT
THE HOUSE OF GALAHAD
Sheet:
File: WAVEFORM_PROCESSOR.kicad_pcb
Title: WAVEFORM PROCESSOR


KO mailto:paul.f.burdette@gmail.com

Do Not Fold, Spindle or Mutiliate
https://github.com/Desval27/FormantKO/

FORMANT
THE HOUSE OF GALAHAD
Sheet:
File: WAVEFORM_PROCESSOR.kicad_pcb
Title: WAVEFORM PROCESSOR

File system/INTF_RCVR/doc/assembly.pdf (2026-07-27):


KO mailto:paul.f.burdette@gmail.com

Do Not Fold, Spindle or Mutiliate
https://github.com/Desval27/FormantKO/

FORMANT
THE HOUSE OF GALAHAD
Sheet:
File: INTF_RCVR.kicad_pcb
Title: INTF RCVR

Size: USLetter | Rev: A
KiCad E.D.A. 10.0.5 | Id: 1/6


KO mailto:paul.f.burdette@gmail.com

Do Not Fold, Spindle or Mutiliate
https://github.com/Desval27/FormantKO/

FORMANT
THE HOUSE OF GALAHAD
Sheet:
File: INTF_RCVR.kicad_pcb
Title: INTF RCVR


KO mailto:paul.f.burdette@gmail.com

Do Not Fold, Spindle or Mutiliate
https://github.com/Desval27/FormantKO/

FORMANT
THE HOUSE OF GALAHAD
Sheet:
File: INTF_RCVR.kicad_pcb
Title: INTF RCVR


KO mailto:paul.f.burdette@gmail.com

Do Not Fold, Spindle or Mutiliate
https://github.com/Desval27/FormantKO/

FORMANT
THE HOUSE OF GALAHAD
Sheet:
File: INTF_RCVR.kicad_pcb
Title: INTF RCVR


KO mailto:paul.f.burdette@gmail.com

Do Not Fold, Spindle or Mutiliate
https://github.com/Desval27/FormantKO/

FORMANT
THE HOUSE OF GALAHAD
Sheet:
File: INTF_RCVR.kicad_pcb
Title: INTF RCVR


KO mailto:paul.f.burdette@gmail.com

Do Not Fold, Spindle or Mutiliate
https://github.com/Desval27/FormantKO/

FORMANT
THE HOUSE OF GALAHAD
Sheet:
File: INTF_RCVR.kicad_pcb
Title: INTF RCVR

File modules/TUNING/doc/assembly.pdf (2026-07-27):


KO mailto:paul.f.burdette@gmail.com

Do Not Fold, Spindle or Mutiliate
https://github.com/Desval27/FormantKO/

FORMANT
THE HOUSE OF GALAHAD
Sheet:
File: TUNING.kicad_pcb
Title: TUNING

Size: USLetter | Rev: A
KiCad E.D.A. 10.0.5 | Id: 1/6


KO mailto:paul.f.burdette@gmail.com

Do Not Fold, Spindle or Mutiliate
https://github.com/Desval27/FormantKO/

FORMANT
THE HOUSE OF GALAHAD
Sheet:
File: TUNING.kicad_pcb
Title: TUNING


KO mailto:paul.f.burdette@gmail.com

Do Not Fold, Spindle or Mutiliate
https://github.com/Desval27/FormantKO/

FORMANT
THE HOUSE OF GALAHAD
Sheet:
File: TUNING.kicad_pcb
Title: TUNING


KO mailto:paul.f.burdette@gmail.com

Do Not Fold, Spindle or Mutiliate
https://github.com/Desval27/FormantKO/

FORMANT
THE HOUSE OF GALAHAD
Sheet:
File: TUNING.kicad_pcb
Title: TUNING


KO mailto:paul.f.burdette@gmail.com

Do Not Fold, Spindle or Mutiliate
https://github.com/Desval27/FormantKO/

FORMANT
THE HOUSE OF GALAHAD
Sheet:
File: TUNING.kicad_pcb
Title: TUNING


KO mailto:paul.f.burdette@gmail.com

Do Not Fold, Spindle or Mutiliate
https://github.com/Desval27/FormantKO/

FORMANT
THE HOUSE OF GALAHAD
Sheet:
File: TUNING.kicad_pcb
Title: TUNING

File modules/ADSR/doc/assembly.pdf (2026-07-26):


KO mailto:paul.f.burdette@gmail.com

Do Not Fold, Spindle or Mutiliate
https://github.com/Desval27/FormantKO/

FORMANT
THE HOUSE OF GALAHAD
Sheet:
File: ADSR.kicad_pcb
Title: ADSR

Size: USLetter | Rev: B
KiCad E.D.A. 10.0.5 | Id: 1/2


KO mailto:paul.f.burdette@gmail.com

Do Not Fold, Spindle or Mutiliate
https://github.com/Desval27/FormantKO/

FORMANT
THE HOUSE OF GALAHAD
Sheet:
File: ADSR.kicad_pcb
Title: ADSR

Size: USLetter | Rev: B
KiCad E.D.A. 10.0.5 | Id: 2/2

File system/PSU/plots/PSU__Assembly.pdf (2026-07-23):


TO BUS GND +15V-15V GND

FORMANT-KO
THE HOUSE OF GALAHAD
Sheet:
File: PSU.kicad_pcb
Title: PSU

Size: USLetter | Rev: A
KiCad E.D.A. 10.0.3 | Id: 1/2


FORMANT-KO
THE HOUSE OF GALAHAD
Sheet:
File: PSU.kicad_pcb
Title: PSU

Size: USLetter | Rev: A
KiCad E.D.A. 10.0.3 | Id: 2/2

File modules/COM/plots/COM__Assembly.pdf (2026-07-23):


KO mailto:paul.f.burdette@gmail.com

Do Not Fold, Spindle or Mutiliate
https://github.com/Desval27/FormantKO/

FORMANT
THE HOUSE OF GALAHAD
Sheet:
File: COM.kicad_pcb
Title: COM

Size: USLetter | Rev: A
KiCad E.D.A. 10.0.4 | Id: 1/6


KO mailto:paul.f.burdette@gmail.com

Do Not Fold, Spindle or Mutiliate
https://github.com/Desval27/FormantKO/

FORMANT
THE HOUSE OF GALAHAD
Sheet:
File: COM.kicad_pcb
Title: COM


KO mailto:paul.f.burdette@gmail.com

Do Not Fold, Spindle or Mutiliate
https://github.com/Desval27/FormantKO/

FORMANT
THE HOUSE OF GALAHAD
Sheet:
File: COM.kicad_pcb
Title: COM


KO mailto:paul.f.burdette@gmail.com

Do Not Fold, Spindle or Mutiliate
https://github.com/Desval27/FormantKO/

FORMANT
THE HOUSE OF GALAHAD
Sheet:
File: COM.kicad_pcb
Title: COM


KO mailto:paul.f.burdette@gmail.com

Do Not Fold, Spindle or Mutiliate
https://github.com/Desval27/FormantKO/

FORMANT
THE HOUSE OF GALAHAD
Sheet:
File: COM.kicad_pcb
Title: COM


KO mailto:paul.f.burdette@gmail.com

Do Not Fold, Spindle or Mutiliate
https://github.com/Desval27/FormantKO/

FORMANT
THE HOUSE OF GALAHAD
Sheet:
File: COM.kicad_pcb
Title: COM

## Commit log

2026-05-13 Start of COM; Custom Symbols
    [COM.kicad_pcb, COM.kicad_sch]
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2026-05-15 library work. project restructure
    [BACKPLANE_B.kicad_pcb, BACKPLANE_B.kicad_sch, COM.kicad_pcb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]
2026-05-15 additional components, noise module
    [NOISE.kicad_pcb, NOISE.kicad_sch]
2026-05-16 com work added lfos
    [COM.kicad_pcb, COM.kicad_sch, LFOs.kicad_pcb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]
2026-05-18 work on lfos, fix pins?
    [LFOa.kicad_sch, LFOb.kicad_sch, LFOs.kicad_pcb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]
2026-05-18 com routing. archive before something goes bad...
    [COM.kicad_pcb, COM.kicad_sch]
2026-05-18 com overhaul & initial complete
    [COM.kicad_pcb, COM.kicad_sch]
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2026-05-19 started dual vca; footprint consistency work
    [DUAL_VCA.kicad_pcb, DUAL_VCA.kicad_sch]
2026-05-19 noise module and footprint work
    [COM.kicad_pcb, COM.kicad_sch, NOISE.kicad_pcb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]
2026-05-20 template for 3U panel work
    [COM.kicad_pcb, COM.kicad_sch, TEMPLATE_3U.kicad_pcb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]
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2026-05-20 adsr schematic; added template module
    [ADSR.kicad_pcb, ADSR.kicad_sch, TEMPLATE.kicad_pcb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]
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2026-05-21 asset update; com refresh
    [COM.kicad_pcb]
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2026-05-22 3u panel template updates
    [TEMPLATE.kicad_pcb, TEMPLATE.kicad_sch, TEMPLATE_3U.kicad_pcb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]
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2026-05-27 panel template rework
    [COM.kicad_pcb, COM.kicad_sch, NOISE.kicad_pcb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]
2026-05-27 3U panels from templates
    [ADSR.kicad_pcb, ADSR.kicad_sch, COM.kicad_pcb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]
2026-05-27 3U panels initial version
    [ADSR.kicad_pcb, COM.kicad_pcb, DUAL_VCA.kicad_pcb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]
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2026-05-27 fix rendered images
    [LFOs.kicad_pcb, NOISE.kicad_pcb]
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2026-05-28 work on noise panel
    [NOISE.kicad_pcb]
2026-05-29 panel dials, leds, jacks and pcb brackets
    [COM.kicad_pcb, NOISE.kicad_pcb]
2026-05-29 DIN connector and COM work
    [COM.kicad_pcb, COM.kicad_sch, system.kicad_sch]
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2026-05-30 tuning schematic and placement
    [TUNING.kicad_pcb, TUNING.kicad_sch, system.kicad_sch]
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2026-05-31 project reorg and cleanup
    [+5v.kicad_sch, -15v.kicad_sch, ADSR.kicad_pcb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]
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2026-06-01 COM updates, NPD text
    [COM.kicad_pcb, COM.kicad_sch, system.kicad_sch]
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2026-06-03 com & tuning panels
    [COM.kicad_pcb, COM.kicad_sch, TEMPLATE_3U.kicad_pcb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]
2026-06-03 noise panel
    [ADSR.kicad_pcb, ADSR.kicad_sch, DUAL_VCA.kicad_pcb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]
2026-06-03 3U panel updaets. LFOs still needed
    [ADSR.kicad_pcb, ADSR.kicad_sch, COM.kicad_pcb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]
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2026-06-04 added 6U template, vco, vcf*2,rfm seeds
    [RFM.kicad_pcb, RFM.kicad_sch, VCF_12.kicad_pcb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]
2026-06-04 mini dial, rfm work
    [RFM.kicad_pcb, VCF_12.kicad_pcb, VCF_24.kicad_pcb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]
2026-06-04 cleanup, vco/vcf12 panel work
    [VCF_12.kicad_pcb, VCO.kicad_pcb]
2026-06-04 fixed card bracket footprint
    [ADSR.kicad_pcb, COM.kicad_pcb, DUAL_VCA.kicad_pcb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]
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2026-06-05 removed bad panels; restarted templates
    [ADSR.kicad_pcb, ADSR.kicad_sch, COM.kicad_pcb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]
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2026-06-05 template additions; adsr semi-final-final-semi version
    [ADSR.kicad_pcb, TEMPLATE_3U.kicad_pcb]
2026-06-05 fixed pad stack for panel pot drill holes
    [ADSR.kicad_pcb]
2026-06-05 new adsr, com, vca, and noise panels based on updated template
    [ADSR.kicad_pcb, ADSR.kicad_sch, COM.kicad_pcb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]
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2026-06-09 panel updates & vco
    [DNG.kicad_pcb, DNG.kicad_sch, TEMPLATE.kicad_pcb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]
2026-06-10 module tester. readme cleanup
    [TEST_HARNESS.kicad_pcb, TEST_HARNESS.kicad_sch]
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2026-06-11 template updates and fixes
    [TEMPLATE_3U.kicad_pcb, TEMPLATE_6U.kicad_pcb]
2026-06-11 led footprint model, vco panel work
    [TEMPLATE_6U.kicad_pcb, VCO.kicad_pcb, VCO.kicad_sch]
2026-06-12 vco, vcf12, vcf24, rfm panels
    [RFM.kicad_pcb, RFM.kicad_sch, TEMPLATE_3U.kicad_pcb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]
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2026-06-13 translations & rfm module
    [RFM.kicad_pcb, RFM.kicad_sch, system.kicad_sch]
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2026-06-17 lib cleanup, vca & psu work
    [+5v.kicad_sch, -15v.kicad_sch, DUAL_VCA.kicad_pcb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]
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2026-06-21 finish adsr module & panel
    [ADSR.kicad_pcb, ADSR.kicad_sch, system.kicad_sch]
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2026-06-22 noise cnc module
    [NOISE_CNC.kicad_pcb, NOISE_CNC.kicad_sch]
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2026-06-22 fix pour
    [RING_MODULATOR.kicad_pcb]
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2026-06-23 multiple jack panels (3U & 6U)
    [MULTIPLE_JACKS_3U.kicad_pcb, MULTIPLE_JACKS_3U.kicad_sch, MULTIPLE_JACKS_6U.kicad_pcb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]
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2026-06-23 mixer 3 panel, LF-VCO translated
    [MIXER_3.kicad_pcb, MIXER_3.kicad_sch]
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2026-06-24 phase shifter pcb placement
    [PHASE_SHIFTER.kicad_pcb, PHASE_SHIFTER.kicad_sch, system.kicad_sch]
2026-06-24 phase shifter trace work
    [PHASE_SHIFTER.kicad_pcb, PHASE_SHIFTER.kicad_sch, system.kicad_sch]
2026-06-25 phase shifter module ready for proto
    [PHASE_SHIFTER.kicad_pcb, PHASE_SHIFTER.kicad_sch, system.kicad_sch]
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2026-06-29 vcf 12 pcb rfs
    [VCF_12.kicad_pcb, VCF_12.kicad_sch, system.kicad_sch]
2026-06-29 restarted vcf 24 module
    [TEMPLATE_6U.kicad_pcb, TEMPLATE_6U.kicad_sch, VCF_24.kicad_pcb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]
2026-06-30 vcf 24 pcb work
    [VCF_24.kicad_pcb, VCF_24.kicad_sch, system.kicad_sch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]
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2026-07-02 noise dng ext
    [NOISE_DNG.kicad_pcb, NOISE_DNG.kicad_sch]
2026-07-02 noise_dng complete?
    [NOISE_DNG.kicad_pcb]
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2026-07-04 added card extender to system
    [CARD_EXTENDER.kicad_pcb, CARD_EXTENDER.kicad_sch, KBI.kicad_pcb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]
2026-07-05 started book 2 sequencer
    [SEQUENCER.kicad_pcb, SEQUENCER.kicad_sch, TEMPLATE_6U.kicad_sch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]
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2026-07-07 s&h schematic & pcb work
    [SAMPLE_AND_HOLD.kicad_pcb, SAMPLE_AND_HOLD.kicad_sch, system.kicad_sch]
2026-07-07 finish up S&H pcb
    [SAMPLE_AND_HOLD.kicad_pcb, SAMPLE_AND_HOLD.kicad_sch]
2026-07-08 fixed PSU values; reorganized PSU info
    [+5v.kicad_sch, -15v.kicad_sch, PSU.kicad_pcb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]
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2026-07-08 com rework; channel first stab at schematic
    [CHANNEL.kicad_pcb, CHANNEL.kicad_sch, COM.kicad_pcb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]
2026-07-09 com fixups, sequencer clock
    [CLOCK.kicad_pcb, CLOCK.kicad_sch, clock_2.kicad_sch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]
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2026-07-11 sequencer clock pcb work
    [CLOCK.kicad_pcb, CLOCK.kicad_sch, clock_2.kicad_sch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]
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2026-07-13 sequencer panel and project cleanup
    [ANALOG.kicad_pcb, ANALOG.kicad_sch]
2026-07-13 fixed images
    [CLOCK.kicad_pcb]
2026-07-13 analog cv-16 panel update
    [ANALOG.kicad_pcb]
2026-07-13 fixed alignment on 6U panel
    [GATE.kicad_pcb, GATE.kicad_sch, TEMPLATE_6U.kicad_pcb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]
2026-07-13 update gate-16 sequencer panel
    [GATE.kicad_pcb]
2026-07-13 updated ADSR panel to add gate input and change led
    [ADSR.kicad_pcb, ADSR.kicad_sch]
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2026-07-14 dual vca pcb traces
    [ADSR.kicad_pcb, ANALOG.csv, CLOCK.csv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]
2026-07-14 finish? dual vca module & panel
    [DUAL_VCA.kicad_pcb, system.kicad_sch]
2026-07-15 com test ready panel & pcb
    [COM.kicad_pcb, COM.kicad_sch, DUAL_VCA.kicad_pcb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]
2026-07-15 vc-lfo schematic; pcb start
    [DUAL_VCA.kicad_pcb, TEMPLATE.kicad_pcb, VC_LFOs.kicad_pcb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]
2026-07-15 vc-lfos pcb and schematic fix for opamp orientations
    [VC_LFOs.kicad_pcb, VC_LFOs.kicad_sch, b.kicad_sch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]
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2026-07-20 added missing gate & env selectors for envelope follower
    [ENVELOPE_FOLLOWER.kicad_pcb, ENVELOPE_FOLLOWER.kicad_sch, system.kicad_sch]
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2026-07-22 Replace panel images with PCB images in README
    Updated images in the README to include PCB renderings.
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2026-07-27 noise updates
    [BACKPLANE_A.kicad_pcb, NOISE.kicad_pcb, NOISE.kicad_sch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]
2026-07-28 noise updates; transistor sockets
    [NOISE.kicad_pcb, NOISE.kicad_sch, system.kicad_sch]
2026-07-28 noise revision; cp axial consistency updates
    [NOISE.kicad_pcb, NOISE.kicad_sch, system.kicad_sch]
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
